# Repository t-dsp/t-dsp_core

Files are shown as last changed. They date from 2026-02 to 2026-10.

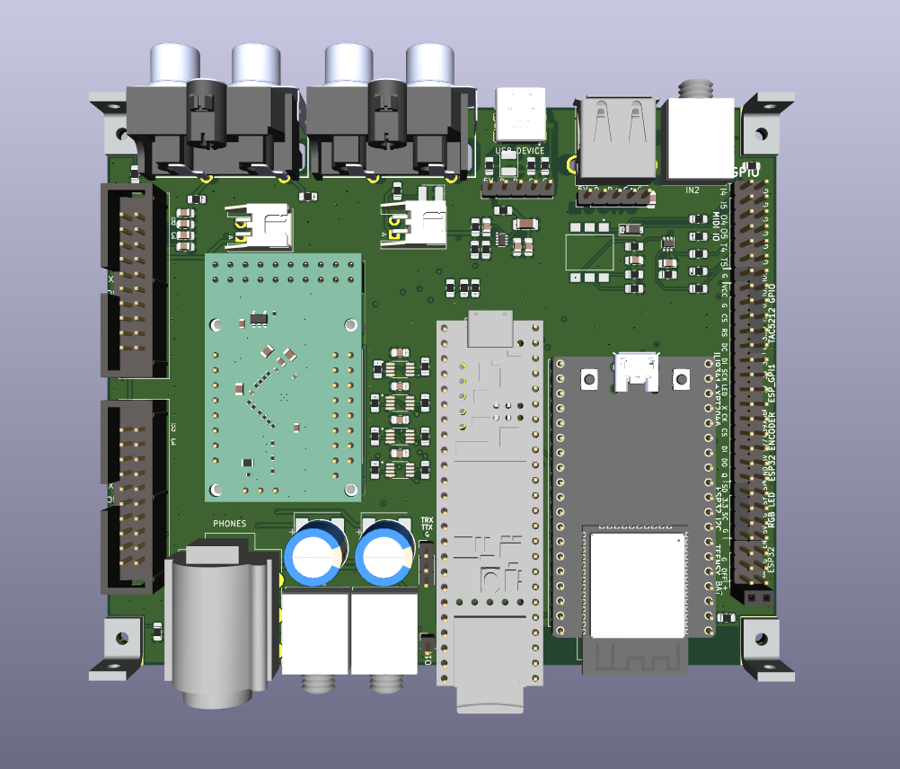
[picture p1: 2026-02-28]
documentation/t-dsp-desktop-pro-3d-top.png

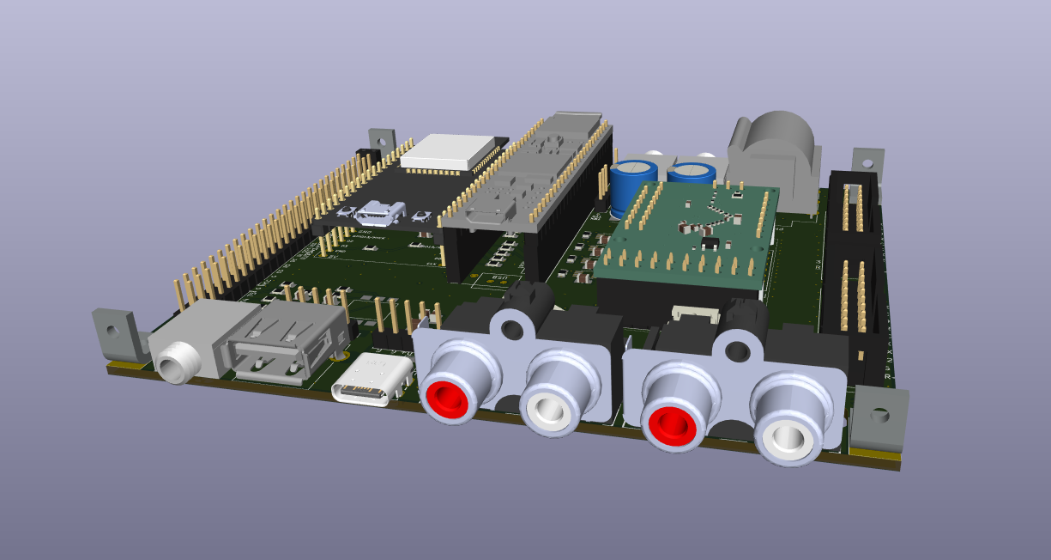
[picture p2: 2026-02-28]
documentation/t-dsp-desktop-pro-3d-angle_back.png

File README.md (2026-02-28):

# T-DSP Core

**Part of the [T-DSP](https://t-dsp.com) open modular audio platform.**

A compact 4-layer digital backplane for the T-DSP modular ecosystem. Hosts a Teensy 4.1 and ESP32 with USB Audio, MIDI, Ethernet, and TDM expansion headers for connecting T-DSP audio modules.

T-DSP Core - Top Isometric

| | |
|:---:|:---:|
| Top | Bottom |
| Front | Rear |

**[View 3D Render Gallery](https://t-dsp.github.io/t-dsp_core/gallery.html)** -- interactive slideshow of all board views

## About T-DSP

T-DSP is an open modular audio platform designed for musicians, engineers, and developers who want powerful digital signal processing in a flexible, hackable format. Built around the [Teensy](https://www.pjrc.com/teensy/) microcontroller and the [Teensy Audio Library](https://www.pjrc.com/teensy/td_libs_Audio.html), T-DSP combines studio-quality audio with a growing library of open-source modules.

Learn more at [t-dsp.com](https://t-dsp.com).

## Overview

The T-DSP Core is a **4-layer digital backplane PCB** hosting a Teensy 4.1 and ESP32 alongside supporting ICs. It provides USB Audio, MIDI, Ethernet, and TDM expansion headers for connecting T-DSP audio modules -- in a more accessible and cost-effective form factor than the 8-layer Desktop Pro.

## Processing

- **Teensy 4.1** -- ARM Cortex-M7 running the Teensy Audio Library for real-time DSP (mixing, effects, synthesis, routing). Also receives USB Audio.
- **ESP32** -- UI controller, WiFi/Bluetooth. Drives the display, buttons, and encoder, and sends commands to the Teensy over serial.

## Connectivity

### Audio I/O
- **3.5mm headphone jack** -- Switchcraft 35RAPC4BV4
- **RCA outputs** -- Stereo analog audio output
- **S/PDIF** -- Digital audio input and output

### USB
- **USB-C DEVICE** -- Power and USB Audio to Teensy with ESD protection
- **USB-A HOST** -- USB host connector

### Networking
- **RJ45 Ethernet** -- Wired network connectivity

### MIDI
- **MIDI input** -- 3.5mm TRS with optical isolation (H11L1)
- **MIDI GPIO** -- Configurable for MIDI in, out, or thru

### Power
- **Dual power input** -- USB-C or external supply via JST-XH header, with TPS22860 power switch for automatic switchover
- **Reverse polarity protection** -- P-channel MOSFET on power inputs
- **Power indicators** -- LED indicators for 5V and 12V rails

### Storage
- **SD card** -- Accessible via Teensy 4.1 built-in SD slot

## Expansion

- **2x TDM expansion headers** (2x10 pin, 2.54mm) -- Connect T-DSP audio modules
  - TDM digital audio bus (BCLK, LRCK, DATA_IN, DATA_OUT, MCLK)
  - I2C control bus (SDA, SCL)
  - Power rails (3.3V, 5V, 12V, GND)
  - Control pins (Held-high, Held-low)
- Modules can be soldered directly or socketed with pin headers
- Multiple modules can be chained on the same TDM bus

## User Interface

- **GPIO header** -- Active-low buttons, rotary encoder, and display connections for tactile UI
- **OLED display header** (128x64, SSD1306) -- Status and menu-driven UI
- **3.2" TFT touchscreen header** (ILI9341) -- Touchscreen UI
- **SK6812 addressable LED header** -- ESP32 and Teensy status indication, plus LED strip control

## Board Design

- **4-layer PCB** -- F.Cu (components/analog), In1.Cu (ground plane), In2.Cu (signal/digital), B.Cu (components/analog)
- **1.6mm board thickness**
- LDO voltage regulation for clean analog power
- Separate analog and digital ground domains
- Buffered digital outputs for reliable module distribution

## Project Files

| Directory | Contents |
|---|---|
| `/3d_models/` | 3D models for PCB components |
| `/documentation/` | Schematic PDF, board images, and reference docs |
| `/lib_fp/` | Custom KiCad footprint libraries |
| `/lib_sch/` | Custom KiCad schematic symbol libraries |
| `/manufacturing/` | CI-generated manufacturing outputs (gerbers, BOM, pick & place) |
| `/panel/` | Panelized board layouts for production |

## Status

This board is under active development.

If you build one, we'd love to hear how it goes -- please open an issue or reach out with your findings.

## Contact

For consulting, custom board design, or commercial licensing inquiries, reach out via [LinkedIn](https://linkedin.com/in/jayshoe).

## License

This project is licensed under the [Creative Commons Attribution-NonCommercial-ShareAlike 4.0 International (CC BY-NC-SA 4.0)](https://creativecommons.org/licenses/by-nc-sa/4.0/).

You are free to share and adapt this work for non-commercial purposes, as long as you give appropriate credit and distribute any derivatives under the same license.

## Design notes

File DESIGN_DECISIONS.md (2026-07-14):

# T-DSP Core — Design Decisions

Architecture decision records for the T-DSP Core (Desktop Pro) backplane. Newest first.

---

## ADR-002 — Next core: OPI PSRAM footprint for 32/64 MB resident fonts (2026-07-14)

**Status:** Accepted — design intent for the next core spin.

### Context
ADR-001 caps this Teensy-4.1 board at **16 MB** (stock QSPI PSRAM). To hold a high-quality GM
font **fully resident** in the chosen TSF engine — native GeneralUser GS (**30.6 MB** of
samples), or larger — the next system moves to a **bare i.MX RT1062** owning its own FlexSPI2,
populated with a single **OPI (Octal) PSRAM** chip. Downsampled GeneralUser variants
(`t-dsp_software/tools/sf2/`) let TSF fit 16 MB *today* (gu12 ~11.7 MB, gu14 ~13.5 MB) but
trade treble for fit; OPI PSRAM removes the ceiling.

### Decision
Design the next core around **one x8 OPI PSRAM footprint**, populated **one chip at a time**
with either density — these two parts are the targets:

| Target | Part number | Density / bus | Holds resident |
|---|---|---|---|
| **32 MB** | **AP Memory APS256XXN-OBRx** | 256 Mbit, DDR Octal (x8) | native GeneralUser GS (30.6 MB) + headroom |
| **64 MB** | **AP Memory APS512XXN-OBRx** | 512 Mbit, DDR Octal (x8) | GeneralUser + a 2nd font, or a ~40–50 MB studio font |

- **One land pattern, two densities.** Pick an x8 OPI BGA common to both the 256 Mb and 512 Mb
  parts so the same PCB accepts 32 MB *or* 64 MB per build. **Verify pin/package compatibility**
  between APS256XXN and APS512XXN in the chosen x8 package before committing the footprint (the
  512 Mb part also offers x16 — use **x8** to match the 256 Mb).
- Route FlexSPI2's **8 data lines + DQS** (vs. 4 for QSPI) plus CLK/CS.
- **Diminishing returns past 64 MB** (holding a 200–400 MB reference font resident) — beyond
  that, stream from SD (sf22aswt) or move to a larger-DRAM SoC.

### Firmware impact — going OPI BREAKS stock PSRAM until the Octal driver is written
- The stock Teensy / i.MXRT core PSRAM bring-up (`configure_external_ram`) speaks **QSPI
  APS6404 only**. It will **not** detect or initialise an OPI part: `external_psram_size` reads
  **0**, `extmem_malloc` fails, and **both SF2 engines are dead** until fixed.
- Fix = a one-time **Octal-DDR FlexSPI2 init driver** (custom LUT + mode-register config, and
  it must set `external_psram_size`), ported from the NXP SDK / RT1170 OPI examples. Everything
  *above* the PSRAM driver — the TSF int16 storage, the font loader, the engines — is
  chip-agnostic and unchanged.

### One interface only (decided) — OPI is not a second bus
OPI is **not a separate interface**. It is the **same FlexSPI2 controller** the Teensy already
uses for its QSPI PSRAM, run in **octal (x8) DDR** mode — a *superset* of the same pins (adds
DQ4–7 + a DQS strobe). So the next core routes exactly **one** PSRAM interface (the single OPI
chip on FlexSPI2) and does not populate any QSPI PSRAM. **No dual-routing.** On a bare RT1062,
FlexSPI1 stays the boot NOR flash; FlexSPI2 is yours for the OPI PSRAM.

**Fast/robust enough? Yes — *faster* than today's QSPI.** 8 DDR data lines vs 4 gives ~4–6× the
bandwidth (roughly ~66 MB/s QSPI → ~400 MB/s octal-DDR), and the DQS strobe aids timing closure
at speed. It's the mainstream external-RAM interface on the NXP RT1060/1170 EVKs and countless
shipping products. TSF already renders from QSPI PSRAM at ~45 % CPU today, so OPI is pure
headroom, not a risk — it just needs normal high-speed-DDR layout care (length-matched
DQ / DQS / CLK).

### Nested / concentric footprints (populate-one, zero extra routing)
Because QSPI is a **pin-subset** of OPI on the *same* FlexSPI2, multiple parts can share **one
land area** — populate exactly one, no second interface:
- **QSPI (SOIC-8) nested inside the OPI BGA.** APS6404 uses only SCLK, CS#, DQ0–3 — all of which
  the OPI part also uses (it adds DQ4–7 + DQS). Co-locate an 8 MB QSPI SOIC-8 land *inside* the
  OPI BGA, wiring the shared FlexSPI2 nets (CLK / CS0 / DQ0–3) to both, and DQ4–7 / DQS / RESET#
  to the BGA only. Stuff the QSPI part → **8 MB on the STOCK Teensy library** for board bring-up;
  later stuff the OPI part → 32/64 MB with the custom Octal driver. The earlier "fallback
  footprint" hedge is now **free** — it's the same nets, not a second bus.
- **APS256 (32 MB) and APS512 (64 MB) on one BGA.** Both are x8 Xccela; if they share the x8
  BGA-24 package (**verify** — the 512 Mb also comes as x16 BGA-49; use the x8), a single BGA
  land takes either density. Nest only if the packages actually differ.

Two caveats for the shared land: **(1)** keep the stub from the shared trace to each unpopulated
pad **short** — dangling stubs hurt the octal-DDR bus at speed; **(2)** **match IO voltage** —
Xccela OPI PSRAM is often **1.8 V** while APS6404L is commonly **3.3 V**; the shared FlexSPI2
pins sit at one bank voltage, so pick same-voltage parts (a 1.8 V QSPI PSRAM, or a 3.3 V OPI
part) or the nesting doesn't fly.

### More than 64 MB (e.g. 64+16)?
Possible, but not worth it. FlexSPI2 can address multiple devices on separate chip-selects, so an
OPI chip **plus** a QSPI chip (→ 64 + 16 = 80 MB) is not impossible — but it means two devices on
the high-speed bus (ideally split across FlexSPI2's A/B ports, pinmux permitting), a mixed
octal+quad custom driver, and tighter layout, all for capacity nothing needs: **64 MB already
holds native GeneralUser (30.6 MB) ~2× over.** If a font ever exceeds 64 MB, stream it from SD
(the sf22aswt engine) instead of adding RAM. **Target stays: one 32 MB or 64 MB OPI chip on the
single FlexSPI2 interface.**

### References
- Datasheets: **APS256XXN-OBRx** (256 Mb OPI) and **APS512XXN** (512 Mb OPI), AP Memory Xccela.
- Extends ADR-001's "Future / custom-MCU consideration" with committed part targets (supersedes
  the placeholder "APS25616" named there).
- Firmware font tooling: `t-dsp_software` → `tools/sf2/FONTS.md`, `tools/sf2/build_gu_fonts.py`.

---

## ADR-001 — PSRAM for the sampled soundfont engines (2026-07-14)

**Status:** Accepted

### Context
T-DSP Core hosts a **Teensy 4.1**. Its external PSRAM lives on the two QSPI pads on the
**underside of the Teensy module itself** (not on this backplane), so this is a
*populate-the-Teensy* decision, not a backplane-footprint one.

The T-DSP synth firmware includes sampled **General-MIDI SF2 engines** that need PSRAM
to hold sample data:

- **`teensy41_sf2_tsf` — TinySoundFont (the chosen engine).** Full-fidelity SF2 renderer:
  velocity layers, region layering, per-voice filters, and **MPE** (per-note pitch bend +
  pressure). It keeps the **entire font's samples RESIDENT in PSRAM** (stored as int16 via
  a local patch), so its font must *fit* PSRAM. Shipped font: **TimGM6mb (~6 MB)**.
- **`teensy41_sf2` — sf22aswt / AudioSynthWavetable.** Streams instruments **on-demand**
  from the SD card, so the font itself can be huge (full GeneralUser GS, 30 MB) while only
  the in-use instruments sit in PSRAM. Trade-off: fidelity ceiling — no velocity layers.

With `external_psram_size == 0` both are effectively unusable (TSF load fails; sf22aswt
falls back to a ~400 KB internal-RAM cap). The core auto-detects size and the firmware runs
unchanged on 0 / 8 / 16 MB.

### Decision
**Populate the Teensy 4.1 with PSRAM. Minimum 1× 8 MB; 16 MB (both pads) recommended.**

| PSRAM | Enables | Notes |
|---|---|---|
| 0 MB | *(no sampled GM)* | sampled SF2 engines don't run |
| **8 MB** (1 chip) | **TSF + TimGM6mb resident, full MPE** — the shipped config | minimum for the chosen engine |
| **16 MB** (2 chips) | headroom: larger resident TSF font (≤~14 MB) or bigger sf22aswt streaming cache | recommended full-populate |

Part: **AP Memory APS6404L-3SQR** — 64 Mbit (8 MB) QSPI PSRAM, SOIC-8 — one or both
underside Teensy pads. Adding the 2nd chip is auto-detected; **no firmware rebuild**.

### Rationale — quality is set by the *engine*, not PSRAM size
- TSF sounds best and does real MPE, but its font must be RESIDENT → compact font only
  (TimGM6mb-class at 8 MB; up to ~14 MB font at 16 MB).
- sf22aswt can reach genuinely high-quality fonts (FluidR3 ~150 MB) streamed from SD, but
  cannot render velocity layers.
- High-quality GM fonts are ~150 MB (FluidR3) to ~400 MB (reference); those live on **SD**,
  and PSRAM only ever holds the *working set* — you never need "as much PSRAM as the font."

Given the project has committed to TSF + MPE, **8 MB is the functional minimum and 16 MB the
comfortable target** for this Teensy-4.1-based board.

### Future / custom-MCU consideration (>16 MB via OPI PSRAM)
16 MB is the ceiling of the Teensy 4.1 / stock i.MXRT **QSPI** PSRAM driver. A future spin
that places a **bare i.MX RT1062** on this board (owning its own FlexSPI2) could go larger
with **OPI (Octal) PSRAM**:

- **QSPI caps at 8 MB/chip** (APS6404L). 16/32 MB parts are **OPI** — 8 data lines, not 4.
- **A single 32 MB OPI chip (e.g. APS25616) is the sweet spot:** it lets **TSF hold the full
  30 MB GeneralUser GS resident at full fidelity** — high-quality *and* fully expressive, the
  biggest quality-per-effort jump beyond 16 MB.
- **Cost:** route **8 data lines** (vs 4) + a one-time **Octal FlexSPI init** driver (the stock
  core is QSPI-only; port from the NXP SDK / RT1170 OPI examples). Everything *above* the PSRAM
  driver — the int16 TSF storage, the font loader, the engines — is chip-agnostic and unchanged.
- **Diminishing returns past ~64 MB** (holding a 200–400 MB reference font resident); at that
  point, stream from SD or move to a larger-DRAM SoC.

**Recommendation:** ship 8/16 MB **QSPI on the Teensy 4.1** (zero new firmware, sufficient for
the shipped TSF engine). *If* a custom-RT1062 spin happens and resident high-quality GM is a
goal, target **one 32 MB OPI PSRAM chip** + the Octal FlexSPI driver.

### References
- Firmware: `t-dsp_software` → `lib/TDspTsf` (TSF int16 patch), `lib/TDspSF2` (sf22aswt),
  build envs `teensy41_sf2_tsf` / `teensy41_sf2`, and `lib/TDspSF2/SF2_GM_ENGINE_PLAN.md`.
- Teensy 4.1 PSRAM: underside SOIC-8 pads on FlexSPI2, `external_psram_size` = 0/8/16.

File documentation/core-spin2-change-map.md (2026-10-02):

# T-DSP Core spin 2 — change map

Status: **schematic edits done 2026-09-28 on branch `spin2/core-module`** (stages 2–5 of §12). Netlist
verified after every stage; ERC is down to one residual (see §14). PCB not yet updated from the
schematic. This document
collects every decision made in the 2026-09-28 design review so the schematic work can be
checked against it. It supersedes the architecture parts of `bt-asrc-block-netplan.md`
where the two disagree (Port B routing, control-line assignments, the DIT). The netplan
remains the reference for the BT module pinout and the IDC747 → IDC777 migration.

Every item is tagged **[decided]**, **[consequence]** (follows from a decision), or
**[open]** (still needs the user's call).

---

## 1. What the board is

**[decided]** The core is a **general-purpose audio compute module**, not a finished
backplane. 2.54 mm headers on two board edges expose the Teensy 4.1, the ESP32-S3, the
audio buses, and the SRC. Users design a backplane that carries codecs, amps, jacks,
connectors, and power entry. The core accepts **5 V** and generates its own rails. The
backplane may carry the bulk of the system current (core ≈ 0.6 A typical, ≈ 1.3 A peak; see the
current budget in §7).

**[decided]** The **isolated DMX / RS-485 block stays on the core** (U16, U17, U18, J28,
D6). It keeps S3 pins IO1, IO5, IO48.

**[decided]** Single-source wireless audio. BT **or** WiFi streaming, never both. No
mixing on the S3, no software resampler on the S3.

**[consequence]** Parts that belong on the backplane and leave the core schematic:

| Leaves the core | Refs |
|---|---|
| Ethernet jack, header | ETHERNET1, ETHERNET_J1 |
| USB-A host, USB-B, USB-C device, USB ESD, USB pin headers | USBA1, USBB1, USBC1, U10, USB_HOST_1, USB_DEVICE_1, D5, CC1, CC2, RLED1, R27 |
| 3.5 mm jacks, 6.35 mm phone jack, RCA/line | J22, J23, J_PHONE1, HPTRS1, HPTRS2, OUT1, INPUT1 |
| MIDI jacks only (opto U4, buffer U9 and passives **stay**) | MIDI_IN_1, MIDI_OUT_1, MIDI_IO1, MIDI_OT1, MIDI_OT2 |
| Rotary encoder, tactile switches | SW1–SW10 (SW3/4/9/10 are the EN/IO0 buttons, see §6) |
| JST power inputs and reverse-polarity FETs | J10, J11, Q1, Q2 |
| Optical S/PDIF TX/RX | TT1, TT2, TR1, TR2, SPDIF1, SPDIF_IO1, SPDIF_IO2 |
| MEMS microphones | MIC1, MIC2 |
| LED chain header only (the SK6812 status LEDs D3/D4 and their 5 V level shifter IC1 **stay**; the chain continues to the backplane via the LED_OUT header pins) | J12 |
| TFT / GPI / encoder / I2C / programming header duplicates | ILI1, ILI2, GPI1, GPI2, ESP_R_ENC1, ESP_R_ENC2, ESP_I1, ESP_I2, ESP_PROG1, ESP_PROG2, T_PROG1 |
| Old ESP32 DevKitC and TAC5212 module symbol | U2, board_outline1 |
| Battery header/cell | BAT1, BAT2 |

Delete them rather than leaving them excluded-from-board: U2 alone is still on 30+ nets
and every one of these adds ERC noise and confuses the header map.

---

## 2. Wireless audio block (BT + S3 → mux → ASRC → Teensy)

> **Superseded on 2026-10-01 (stage 10y, section 11.8).** The SRC4382, both 74LVC157 muxes and the
> S/PDIF header are gone. IDC777 and S3 now reach the Teensy's SAI2 port through a 74LVC257 mux,
> sample-rate conversion is done in Teensy software, and a buffered J_SAI2 header offers the same
> port to an external I2S master or slave. The text below is kept as the history of the decision.

Architecture: IDC777 (U22) and the S3 are both **I2S masters** into a hardware mux, the
mux feeds SRC4382 Port A (slave), the SRC resamples onto the Teensy's clock and outputs on
Port B (slave to the Teensy). One source at a time.

### 2.1 Mux

**[decided]** Keep U21 (74LVC157A) for BT vs S3.

**[decided]** Add a **second 74LVC157A (U23)** cascaded after U21: selects between U21's
output and an **aux I2S input from the edge header** (BCK, LRCK, DATA). Aux must be an I2S
master. Cost: one TSSOP-16, three header pins. If the header pin budget gets tight, aux is
the first thing to cut.

### 2.2 SRC4382 (U19) wiring changes

| Pin | Today | New |
|---|---|---|
| 48 BCKB | BCLK1+TDM1 | **4_BCLK2** (Teensy pin 4, I2S2 BCLK) |
| 47 LRCKB | LRCK1+TDM1 | **3_LRCLK2** (Teensy pin 3, I2S2 LRCLK) |
| 45 SDOUTB | SRC_SDOUT (dangling) | **5_IN2** (Teensy pin 5, I2S2 IN) |
| 46 SDINB | NC | **2_OUT2** (Teensy pin 2, I2S2 OUT) — reverse ASRC path |
| 40 SDOUTA | NC | **edge header, aux I2S out** — reverse ASRC path |
| 24 ~RST | SRC_RST (dangling) | **ESP32_EN** net |
| 26 GPO1 | NC | **BT_RST** (U22 pin 36) |
| 27 GPO2 | NC | **BT_SYS_CTRL** (U22 pin 13) + 100 k pulldown to GND |
| 28 GPO3 | NC | **BT_S3_SEL** (U21 pin 1) |
| 29 GPO4 | NC | **AUX_SEL** (U23 select) |
| 1–8 RX1±…RX4± | NC | **edge header**, raw differential pairs |
| 31, 32 TX−, TX+ | NC | **edge header**, raw pair |
| 12 RXCKO, 11 ~LOCK, 15 ~RDY, 23 ~INT | NC | leave NC (or S3 GPIO later) |

Why: the SRC has **no TDM mode** (checked in the full SRC4392 datasheet) and drives SDOUT
continuously, so Port B cannot share the TDM1 data line. Moving Port B to Teensy I2S2
gives the Teensy a plain stereo `AudioInputI2S2`. GPOs default **low** at reset, are
register-forced high/low (regs 0x1B–0x1E), and cost zero S3 pins. BT held in reset until
the S3 configures the SRC is the desired ordering. SRC ~RST on ESP32_EN resets the SRC with
the S3 and satisfies the 500 µs I2C hold-off by a wide margin. The SRC4382 **does** have
a DIT (TX pins are real), contrary to the netplan.

Firmware notes that follow: soft-mute (reg 0x2D) around source switches, since the
hardware MUTE pin is tied to GND. Reverse path = SRCIS=Port B, AOUTS=SRC; one direction at
a time.

### 2.3 S3 I2S master

**[decided]** S3 is I2S master on its second I2S controller into U21 inputs I1a/I1b/I1d.
**[consequence]** The existing S3-slave I2S2 link to the Teensy is **retired in both
directions**: IO4/IO6/IO7 become the master port, IO16 is freed. The Teensy's I2S2 port is
now owned by the SRC (2, 3, 4, 5).

### 2.4 BT module (U22) — unchanged from netplan except:

- BT_UART_TX / BT_UART_RX → **S3 UART2** on IO16 (RX) and IO35 (TX) — see §3 for the
  variant dependency.
- BT_RST, SYS_CTRL, BT_S3_SEL now from SRC GPOs (§2.2).
- VCHG / VCHG_SENSE / CHG_EXT stay no-connect; add **test points** per datasheet advice.

---

## 3. ESP32-S3 (U13) pin map

| Pin | Use after spin 2 |
|---|---|
| IO4, IO6, IO7 | I2S master → U21 (DOUT, BCK, LRCK — assign in firmware) |
| IO16 | BT UART2 RX |
| IO3 | BT UART2 (S3 RX side, net `BT_UART_RX`). IO35 is not available on the N16R8 module |
| IO19, IO20 | **native USB D−/D+ → edge header** (OTG, host or device) |
| RXD0, TXD0 | Teensy Serial7 (programming + FlasherX tunnel) **and** edge header |
| IO0, EN | Teensy 36/37 **and** edge header (already pins 60/56) |
| IO1, IO5, IO48 | DMX (stays) |
| IO8, IO9, IO10, IO11, IO2, IO42, IO18 | TFT SPI + touch (already on header) |
| IO12, IO13, IO14, IO17 | SPI link to Teensy (internal) |
| IO15, IO38, IO39 | encoder (already on header) |
| IO40, IO41 | GPI (already on header) |
| IO21, IO47 | I2C (already on header) |
| IO45 | **→ J8** (strapping pin; document the boot constraint). IO46 drives the SK6812 chain (`ESP32_LED`), 5 V copy on J11 |
| IO35, IO36, IO37 | **NC** - owned by the octal PSRAM on the N16R8 module |

**[decided 2026-09-28] Module variant: ESP32-S3-WROOM-1-N16R8** (LCSC C2913202). Spotify
Connect (cspot and the Espressif audio SDK) buffers and decodes the Vorbis stream in PSRAM and
needs 4-8 MB; the 2 MB quad-PSRAM R2 parts are not enough. Octal PSRAM uses IO35/IO36/IO37,
so those three module pins are NC and the BT UART RX moved to IO3. PCB antenna (-1, not -1U).

---

## 4. Teensy 4.1 (U1) pin changes

| Pin | Today | New |
|---|---|---|
| 2 OUT2 | → S3 IO4 | `SAI2_OUT` → U21 buffer → J_SAI2 DOUT (stage 10y; was SRC SDINB) |
| 3 LRCLK2, 4 BCLK2 | → S3 (via 49.9 Ω) | `SAI2_LRCLK` / `SAI2_BCLK`: from the U19 257 mux (IDC777 or S3) or J_SAI2 via U21, or driven out to J_SAI2 (stage 10y) |
| 5 IN2 | ← S3 IO7 | `SAI2_IN`: from the U19 mux or J_SAI2 DIN via U20 (stage 10y) |
| 22 | NC | `SAI2_SEL` (U19 select: 0 = IDC777, 1 = S3; 10 k pull-down) — stage 10y, no longer on J3 |
| 26, 27 | NC | `SAI2_MODE0` / `SAI2_MODE1` (U23 interlock, 10 k pull-ups = all off) — stage 10y, no longer on J3 |
| 32 OUT1B | J15 (1-pin) | → edge header |
| 33 MCLK2 | J19 (1-pin) | `SAI2_MCLK` → U21 buffer → J_SAI2 MCLK in both header modes (stage 10y; J3 pin 22 is GND now) |
| 49 VUSB | NC | → **TPS2116 VIN2** (see §7) |
| 46 3V3 | on the 3.3V rail | **disconnected from the rail, not exposed** (see §7) |
| 55–57 host USB | USBA1 / USB_HOST_1 | → edge header (D+, D−, HOST_5V) |
| 66/67 device USB | USBC1 / U10 | **stays on the Teensy's own jack only; not on header** |
| 28/29 Serial7, 36/37 | S3 UART0 / IO0 / EN | unchanged — programming kit + FlasherX |
| 53 PROGRAM, 54 ON_OFF | header 55/59 | unchanged |

MIDI: MIDI_IN/OUT/THRU are on header pins 1–6 at the *jack* level. **[decided]** the opto
(U4), buffer (U9) and their passives stay on the core.

Also **[open]**: `9_OUT1C_INPUT` feeds Teensy pin 9 as TDM2's data-in. Pin 9 is OUT1C; the
audio library's inputs are IN1 (pin 8) and IN2 (pin 5). Confirm this is intentional or
re-purpose.

---

## 5. Edge headers

**[decided]** 2.54 mm headers, **two 2-row headers side by side near each 60.96 mm edge**
(four rows per end, inboard by ~5 mm): **≈168–176 pins**. See §11 for placement and §11.2
for the pin-assignment rules.

**[consequence]** The `board_outline` symbol (lib_sch:t-dsp_core, 106 pins) is the header
net map, but **no outline footprint has pads for it**. A real header footprint must be
built (this is the source of the six `footprint_link_issues` ERC errors). TDM1/TDM2 as
separate 2x10 connectors are redundant with the T*/TT* header groups and leave the core.

**[decided 2026-09-28] GPIO exposure policy: raw pins, not named UI functions.** The
core does not decide what a backplane builds. Pins go to the header as plain GPIO and the
backplane wires TFT, touch, encoder, buttons, LEDs, or nothing. Consequences:

- **S3 side:** every free S3 pin is `S3_IOnn`. The S3's GPIO matrix maps SPI, I2C, UART,
  PWM, and I2S to any pin, so nothing is lost by not naming them. The on-core TFT/touch
  pull-ups (R22/R23/R64/R65), LED jumpers (ILI_LED1–4), and the duplicate UI headers all go.
- **Teensy side:** every free Teensy pin is `T_nn`. The i.MX RT has *fixed* peripheral
  pins, so the header doc carries the Teensy pin-capability table (which pins are I2C,
  SPI, UART, CAN, PWM, analog). **MIDI logic stays on the core** (opto U4, buffer U9, their
  passives): the header carries MIDI IN/OUT/THRU at the *jack level* (existing pins 1–6);
  only the DIN/TRS jacks themselves are on the backplane. Same for DMX: isolation and
  transceiver on the core, the XLR on the backplane.
- **Exceptions, still named, because the core transforms or owns them:** the two buffered
  TDM buses, `I2C0` (shared with the SRC, pull-ups on the core), SRC S/PDIF RX/TX pairs,
  aux I2S in/out, the three USB pairs, S3 `UART0` + `EN` + `IO0` (programming), Teensy
  `PROGRAM`/`ON_OFF`, `VBAT`, **MIDI IN/OUT/THRU (jack level)**, **DMX A/B**,
  **ESP32_LED_OUT / TEENSY_LED_OUT** (SK6812 chain continuation, 5 V level), and all power pins.
- **The reference backplane** (dev board + test jig) is where the opinionated wiring lives:
  TFT, encoder, buttons, MIDI jacks, codec. That is what makes the platform "easy to build
  something useful with", not the core.

Signals to **add** to the existing 106:

| Group | Pins |
|---|---|
| SRC S/PDIF: RX1± … RX4±, TX± | 10 |
| Aux I2S in (BCK, LRCK, DATA) | 3 |
| Aux I2S out (SDOUTA) | 1 |
| S3 USB D−/D+ | 2 |
| S3 RXD0/TXD0 | 2 |
| S3 spare GPIO (IO3, IO45, IO46, IO36, IO37) | 3–5 |
| Teensy 22, 26, 27, 32, 33 | 5 |
| Teensy host USB D+, D−, HOST_5V | 3 |
| 5V_IN (into TPS2116 primary) | 1–2 |
| Extra GND adjacent to USB/clock pairs | ~6 |
| **Total ≈ 106 + 38 = ~144** | fits, barely |

Rules: every USB pair on adjacent pins with GND either side; the same for MCLK/BCLK;
5 V and 3.3 V pins are **output-only** except the dedicated 5V_IN. If short of pins, drop
in this order: aux I2S in/out, duplicate 3.3 V/5 V pins, S3 strapping pins.

---

## 6. USB and programming

**[decided]** **No USB mux.** The Teensy's own micro-USB jack is the core's power input and
the Teensy's programming / USB-audio port. The Teensy **device** pair is **not** on the
header (a second connector would be an unterminated stub on a 480 Mbps pair). A panel USB
for the Teensy on a product is a short extension from the Teensy jack.

**[decided]** Teensy **host** pair and S3 **OTG** pair go to the header. Backplane provides
connectors, ESD, VBUS switching (Teensy HOST_5V is just VIN; the host library has no
power-enable pin).

**[revised 2026-10-01, stage 10y]** All three USB ports are on headers and **none is isolated**
(the ISOUSB211 plan of stage 10x was dropped with the SAI2 rework): Teensy host pair on J4 odd
row (1 GND, 3 HOST_D1-, 5 HOST_D1+, 7 GND, 9 HOST_5V), Teensy device pads 66/67 on J4 even row
(2 GND, 4 T_USB_DN, 6 T_USB_DP, 8 GND, 10 GND), S3 OTG pair on J8 (31 S3_USB_DN, 32 S3_USB_DP,
33 GND, 34 5V). The S3 port is host or device by firmware; J8 pin 34 is the core's 5 V rail, so a
backplane wires it to a jack's VBUS only for a host-mode jack (or through a load switch); a
device-mode jack leaves VBUS unconnected. The Teensy device row has no VBUS pin: the Teensy's
VUSB is NC on the core (stage 10x). Ground-loop hum between a laptop and the externally powered
core is handled on the backplane (isolator or audio-side ground lift) if it shows up.

**[decided]** EN and IO0 on the edge connector (already). On-core prog headers and EN/IO0
buttons leave. **Add a 10 k pull-up on ESP32_EN** — required by the software repo's
`TDspProgrammingKit` README for the next spin and by the S3 module reference design.
Today the net has only the two 0.1 µF caps.

**[verified]** FlasherX path (`@FXUP` over Teensy Serial7 ↔ S3 UART0, EN from Teensy 37,
IO0 from Teensy 36) is fully wired. S3 UART0 is not its USB console, so the tunnel no
longer competes with logging. 115200 is a firmware constant on both ends.

**[consequence]** Teensy is flashed by the S3 via FlasherX only (self-reflash). HalfKay is
USB-only; recovery of a bricked Teensy needs a cable in the Teensy jack.

---

## 7. Power

```
edge header 5V_IN ──► TPS2116 VIN1 (priority) ─┐
Teensy VUSB (pin 49) ► TPS2116 VIN2 (secondary) ┴──► 5V rail ──► Teensy VIN
                                                        ├──► 3.3 V buck  ──► 3.3V_DIG (S3, BT, SRC, mux, ISO7761)
                                                        │                     └► TLV76718 ──► +1V8 (SRC core)
                                                        ├──► LT3045 (U15) ──► 3.3V (buffers, header, analog)
                                                        └──► TEA1-0505 ──► 5V_ISO (DMX)
```

| Item | Status | Action |
|---|---|---|
| TPS2116 input mux | wired (JST + USB-C) | **VIN1 ← header 5V_IN; VIN2 ← Teensy VUSB**. J20 already sits on VIN2. |
| Teensy VUSB↔VIN pad | intact | **Must be cut** on every Teensy. Otherwise PC USB 5 V and the backplane supply are paralleled. Build note. |
| 3.3V_DIG regulator | TLV76733 LDO, 1.3 W in 2×2 WSON at 750 mA | **[decided] replace with a 3.3 V buck**, 1.5–2 A class (TPS62A02 / TPS563xx class). Keep R66 enable pull-up semantics. |
| LT3045 (U15) | output dangling (only C42) | **connect OUT to the 3.3V rail**. SET = 33 k → 3.3 V. Check R58 ILIM value. |
| Teensy 3V3 (pin 46) | sources the 61-node 3.3V rail | **remove from rail; not exposed**. Never parallel two regulators. |
| LP5907 3.3V_A (U109) | mic rail via net-tie + jumper to 3.3V | mics leave the core; **[open]** keep as a second analog LDO or delete. |
| FL2 / CR1 / FB8 branch | dead (5V_unfiltered, GND_unfiltered single-node) | delete |
| 12V | JST + Q2 pass-through to headers | **[open]** keep as pass-through pin only, or drop. Core does not generate it. |
| 3.3V header pins | on rail | output-only, advertise a limit (~200 mA). Never accept 3.3 V in. |
| USB-C PD | none | **not on the core.** Backplane/submodule PD sink (STUSB4500 or CH224K) when >15 W is needed; backplane bucks to 5 V for 5V_IN. |
| MCLK1 | Y1 via R61 **and** Teensy pin 23 via R7 | **[open]** two drivers on one net. Y1 standby jumpers R59/R60 exist. Decide which populates. |

Current budget on the 5 V rail, core alone (revised 2026-09-30):

| Load | Typical | Peak | Note |
|---|---|---|---|
| Teensy 4.1 at 600 MHz + 2x PSRAM | 150 mA | 200 mA | +100 mA more with the Ethernet PHY linked |
| ESP32-S3 (via the 3.3V_DIG buck, ~90 %) | 200 mA | 450 mA | WiFi TX bursts; ~40 mA idle, ~100 mA BLE only |
| IDC777 BT audio | 50 mA | 100 mA | A2DP streaming |
| SRC4382 + 1V8 LDO | 60 mA | 80 mA | |
| DMX: TRACO TEA1-0505 + ISO7762 + RS-485 | 100 mA | 250 mA | 1 W converter at full isolated load |
| SK6812 D3/D4 | 40 mA | 120 mA | full white |
| Buffers, muxes, LDO quiescent | 15 mA | 20 mA | |
| **Core total** | **≈ 0.6 A** | **≈ 1.3 A** | plus Ethernet: ≈ 1.4 A peak |

Plan **1.5 A for the core** and a 2.5-3 A external supply once a backplane with codecs and small
amps hangs off `5V` and `3.3V`. The TPS2116 mux is rated 2.5 A. A PC USB port (500 mA) on the
Teensy jack programs both MCUs and runs the board with the radios idle, but browns out under
WiFi bursts or DMX + LEDs; a USB-C port at 1.5 A is fine for bench use.

---

## 8. Slave-clock option (keeps DAC-master and multi-core architectures possible)

Today the core can only be the audio clock **master**: buffers U5 (LRCK1), U6 (MCLK1),
U7 (BCLK1) have ~OE tied to GND and drive outward; the Teensy's clock pins sit behind them
with no path back from the bus.

**[decided]** Make it switchable, cheaply:

1. **Buffer ~OE pins** (U5, U6, U7, U8 data-out, U11 data-in) move from hard GND to a
   **solder jumper (default GND) or one S3/Teensy GPIO** (`BUS_MASTER_EN`). A slave core
   tri-states its drivers.
2. **Bypass jumpers** from the header-side clock nets (BCLK1+TDM1, LRCK1+TDM1, MCLK1+TDM1)
   to the Teensy-side nets (BCLK1, LRCK1, MCLK1) — one 2-pad solder jumper per line,
   default open. Closed + buffers disabled = Teensy is I2S slave to the bus.
3. **Y1** already has standby jumpers (R59 to VDD / R60 to GND); a slave core populates R60.
4. **SRC I2C address**: add a jumper option on A0/A1 (pins 19/21) so two cores on one I2C
   bus don't collide. Zero cost.
5. **No-radio build variant**: IDC777, S3 antenna path, U20/U21/U23 DNP-able. Multiple cores
   in one box should have radios on one core only.

Firmware: the audio library has I2S slave objects for both Teensy ports (stereo). A TDM
slave object does not exist in the software repo yet.

Why: a serious DAC stage wants the oscillator beside the DAC with the DAC as clock master;
multi-core digital mixing needs one clock master. Both need the core to accept clocks.
Cost is a handful of jumpers.

---

## 9. Cleanups found during the review

- Delete **U2** (ESP32-DevKitC, excluded-from-board, still on 30+ nets) and
  **board_outline1** (TAC5212 module symbol).
- Orphan single-node nets to remove or connect: `Earth`, `GNDD`, `S-GND`, `SN`,
  `ESP32_3.3V`, `5V_unfiltered`, `GND_unfiltered`, `MCLK2` (J19), `32_OUT1B` (J15).
- **Footprints missing**: C130, C131 (5 V decoupling), C132, C133 (3.3V_DIG decoupling),
  R66 (100 k enable pull-up).
- Konnect user config `%APPDATA%\konnect\config.json` line 10: `layer_count` is 2, the
  board is 4-layer. Set to 4 before trusting DRC.
- Antenna keepout for U22: 8 × 4.44 mm at the −X end, all copper removed on every layer
  out to the board edge, plus a PCB keepout rule. Board-edge, top-left per datasheet.

---

## 10. Open decisions (blocking nothing else)

| # | Decision | Default if not decided |
|---|---|---|
| 1 | ~~S3 module variant~~ **[decided 2026-09-28]: ESP32-S3-WROOM-1-N16R8** (8 MB octal PSRAM, required for Spotify Connect stream buffering; costs IO35-37). PCB antenna. | - |
| 2 | ~~Board outline~~ **[decided 2026-09-28]: 100 × 60.96 mm**, see §11 | — |
| 3 | MCLK1 driver: Y1 or Teensy pin 23 | Y1 (24.576 MHz = 512·fs), Teensy pin 23 via R7 removed |
| 4 | 12 V: pass-through pin or drop | pass-through pin, no on-core parts |
| 5 | ~~MIDI logic~~ **[decided 2026-09-28]: stays on the core**, jack-level on the header (user: MIDI and DMX are core features of an audio device) | — |
| 6 | LP5907 3.3V_A: keep or delete | delete (mics leave) |
| 7 | `9_OUT1C_INPUT` intent | ask |
| 8 | ~~External antennas~~ **[decided 2026-09-28]**: BOM options -1U and IDC767, u.FL J13 DNP on pad 57 (see section 11) | — |

---

## 11. Mechanical and placement

**[decided]** Outline **100 mm × 60.96 mm** (`project_fp:audio_project_board_outline_100x60.96`,
already placed as board_outline2). 60.96 mm = the Teensy 4.1's 2.4 in length.

**[decided]** The Teensy spans the full 60.96 mm depth with its **micro-USB end flush with
one 100 mm edge and its microSD end flush with the other**, so a backplane or enclosure
can expose either. Soldered directly, no socket.

**[decided]** The edge headers are on the two **60.96 mm edges**, perpendicular to the
Teensy. The 100 mm edges carry only the Teensy ends and the antennas.

**[consequence] Pin budget.** A 60.96 mm edge holds 24 positions at 2.54 mm with no
margin, ~21–22 with corner mounting holes. One 2-row header per edge = **~84–88 pins
total**, far short of the ~144 in §5. Options:

| Option | Pins | Notes |
|---|---|---|
| **A. Two 2-row headers side by side per edge** (4 rows, 10.16 mm strip) | 168–176 | **recommended.** Fits §5 with ~25 spare. Backplane sees two parallel 2×21/2×22 connectors per edge, a common arrangement. |
| B. One 2-row header per edge + cuts | 84–88 | needs ~55 pins cut: TDM2 bus gone, TDM GND pins thinned, MIDI THRU, aux I2S, S3 spares, SRC RX3/RX4, duplicate power pins. Loses the second TDM bus, which a backplane can replace by chaining modules on one bus. |
| C. 2.0 mm or 1.27 mm pitch | 100+ | rejected: 2.54 mm is a product requirement. |

**[decided 2026-09-28]: option A**, two 2-row headers per short edge (four rows).

**[consequence] Area.** With option A each short edge loses a 10.16 mm strip and the Teensy
takes an 18 mm strip: usable top area ≈ 62 × 61 mm ≈ 3800 mm². Estimated courtyard after
the §1 deletions and the §2/§7 additions ≈ 3300 mm² plus the headers. **Two-sided assembly
is required**: Teensy, S3, IDC777, SRC and headers on top; small ICs and passives on the
bottom. The bottom under the Teensy is usable, the top under it is not (the Teensy carries
bottom-side parts).

**[consequence] Antennas.** Both radios need a board edge with copper removed on every
layer: 8 mm along the edge × 4.44 mm inward for the IDC777, roughly 15 × 6 mm for a
PCB-antenna S3. Both go on the **100 mm edges**, in the 82 mm not occupied by the Teensy
end, offset ≥ 6 mm from the corners so the header strips on the short edges are not cut
into. One radio per long edge, or both on one long edge at opposite ends, ≥ 40 mm apart.

**[decided] Headers sit inboard, not on the edge.** Outer row centreline ≈ 5 mm from the
short edge (rows at x ≈ 5.0, 7.5, 10.1, 12.6 mm and mirrored at the other end). Nothing
requires a mezzanine header to touch the edge, and inboard gives every row an escape
channel on both sides, frees the true corners for mounting holes, and leaves a copper-free
margin. Moving them further inboard than that buys nothing: the routing lever is *which*
signals go to *which* header, set by the placement below.

### 11.1 Placement plan (drawn for routing, X in mm from the left short edge)

```
 x:  0    5   13  15         33  35                                   85  87   95  100
     |  [hdr L 4 rows] [  TEENSY  ]  [ S3 ]  [SRC][mux]   [DMX iso][pwr] [hdr R 4 rows]  |
     |                  USB end @ y=0  ant@y=0                                            |
     |                  SD end @ y=61  [IDC777 ant @ y=61]                                |
     bottom side under the Teensy: 5 bus buffers, series Rs, Y1, TPS2116, input caps
```

- **Left header = Teensy domain.** TDM1 and TDM2 buses (from the buffers directly beneath
  the Teensy on the bottom side, shortest possible path), MIDI, Teensy S/PDIF, CAN3,
  Teensy spares (22/26/27/32/33), Teensy host USB, PROGRAM/ON_OFF, VBAT, 5V_IN, power outs.
- **Right header = S3 / peripheral domain.** TFT SPI + touch, encoder, GPI, both I2C
  buses, S3 USB, S3 UART0, EN/IO0, S3 spares, DMX A/B, SRC S/PDIF RX/TX, aux I2S in/out,
  LED outs.
- **Antennas on the long edges** in the 50 mm between the Teensy and the right header:
  S3 PCB antenna on one long edge, IDC777 on the other, ≥ 40 mm apart.
- **Teensy near the left header** so its left pin row (pins 0–12: MIDI, I2S2, TDM data,
  SPI) is 2–3 mm from the header and the I2S2 pins face the SRC. Its right row (TDM
  clocks 20/21/23, I2C, S3 control) reaches the buffers on the bottom side through vias.

### 11.2 Header pin-assignment rules (for the pin map, not yet drawn)

1. **Order pins along Y to match the physical order of their sources** (Teensy pin 0 at the
   USB end ascending toward the SD end; S3 pins likewise) so traces do not cross.
2. **Outer 2-row header = signals that arrive on the outer layers; inner header = signals
   that arrive through the bottom side or In2.** Keeps layer changes near the pins.
3. **One GND per ≤ 4 signals, and a GND adjacent to every clock and every differential pair.**
   MCLK (24.576 MHz), BCLK, and the USB pairs get GND on both flanks.
4. **Differential pairs on adjacent pins in the same row**, never across rows: Teensy host
   USB, S3 USB, SRC RX1–RX4, SRC TX.
5. **Power pins at the ends of each block** (5V_IN, 5 V, 3.3 V, 12 V pass-through, GND) so
   wide copper stays out of the signal field.
6. **All four TDM lines of a bus in one row, contiguous, with GND between**: MCLK, BCLK,
   LRCK, DATA_OUT, DATA_IN.
7. **Reserve ≥ 8 spare pins per block** at the inner end, labelled RESERVED, never repurposed
   without a header-contract version bump.
8. **Name every pin by function, not by MCU pin number** (the header is the product API;
   a future core with a different MCU must fit the same backplane).

Stackup for routing: F.Cu signal, In1.Cu solid GND, In2.Cu signal with 3.3 V / 5 V islands,
B.Cu signal + bottom-side parts. Every header signal has In1 GND directly beneath it.

**[decided 2026-09-28] Teensy memory.** The Teensy 4.1 carries two bottom-side SOIC-8 pads for
PSRAM/flash. Fit **2 x APS6404L-3SQR-SN** (16 MB PSRAM, mapped as EXTMEM) for loop recording,
echo and reverb buffers, or one PSRAM + one W25Q128 flash. The chips are 1.2 mm tall on the
Teensy's underside, so the core's top side under the Teensy footprint is a **placement keepout**
and the Teensy mounts on 2.54 mm headers (not soldered flat). Power: about 10 mA per PSRAM at
3.3 V from the Teensy's own regulator.

**[decided 2026-09-28] Ethernet.** The Teensy's 10/100 PHY pairs are on six 2 mm-pitch pads
(60-65) on its underside. They are **not** reachable by a cable once the Teensy is mounted, so
the core picks them up: pads 60-65 return to the Teensy footprint (they exist in
`Teensy41.kicad_mod`, were dropped in `_mod3`) and route under 20 mm as two 100 ohm pairs to
**J12 `J_ETH`** right beside them. Magnetics, RJ45 and the LED resistor live on the backplane.

**[decided 2026-09-28] Antennas: on-board by default, off-board as a BOM option, no layout change.**
- S3: `ESP32-S3-WROOM-1-N16R8` (PCB antenna, C2913202) or `ESP32-S3-WROOM-1U-N16R8` (u.FL on the
  module, C3013946). Same pad layout; the -1U is 6 mm shorter. Keep the top-edge copper keep-out in
  both builds.
- Bluetooth: `IDC777-1` (chip antenna) or `IDC767` (external antenna). Verified from datasheets
  IDC767-DTS-V003 and IDC777-DTS-V003: identical 60-pad LGA and pin table; **pad 57 is EXT_RF on
  both** ("RF to EXT Antenna (Ext ANT SKU - IDC767)"), unused on the IDC777. The core routes pad 57
  to a DNP u.FL (J13) as a 50 ohm coplanar waveguide with ground pads 56 and 58 on either side,
  ground vias every 1-2 mm along it, trace as short as possible, continuous ground on the layer
  below. No matching network. With the IDC777 fitted the stub is simply unused.
- Off-board antennas also let the two radios be separated further than the 61 mm the board allows.

**[open] Mounting.** Four M3 (or M2.5) holes for standoffs to the backplane, needed for
header retention. Corners are the natural spot; each corner hole costs ~2 header positions
on that edge, already counted above. The 100x60.96 outline footprint currently has **no
holes and no header pads**; both are added when the header footprint is built.

---

### 11.3 PCB placement as executed (2026-09-28, Konnect IPC, single-sided top assembly)

Board-local coordinates (X from the left short edge, Y from the top long edge; KiCad x = 100 + X,
y = 139.04 + Y). Everything is on F.Cu. Collision-checked against real courtyards and every Teensy pad;
DRC after placement: no shorts, no clearance errors, 499 unrouted connections (expected).

| Block | Where | Notes |
|---|---|---|
| U1 Teensy 4.1 | X 15.7-33.5, full height, USB end at the top edge, rot 180 | mounts on 2.54 mm headers; PSRAM on its underside |
| Oscillator Y1/FB1/C44-46/R59-61/C129 | under the Teensy, X 23.5-30.7, Y 6-16.5 | next to Teensy pin 23 (MCLK); clear of the D+/D-/VUSB pads |
| Teensy series Rs, SPI pull-ups, C2-C5 | under the Teensy, three columns X 20/24/28, Y 18.5-44 | clear of the USB-host pads and the PROGRAM/ON-OFF pad row; flip to B.Cu if you prefer nothing under the Teensy |
| J2 J_TDM + U5-U8/U11 + R40-47/R55/56 + C17-20/C40 | left column X 1.5-13.5 | buffers 3 mm from the header rows |
| J4 J_USBH, J12 J_ETH, J3 J_T | strip X 33.6-39.3 right of the Teensy, top to bottom | USB host and Ethernet opposite the Teensy's own pads |
| C27-C30 | X 41, Y 3-17 | 3.3 V rail decoupling |
| MIDI U4/U9/D2/C16/C21 | X 53.5-63, Y 41-56.9, right of the IDC777 | R31-R35 in a row at X 54.5-65.7, Y 34-37.7; R36-R39 in spare slots under the Teensy; J5 (MIDI header) at the top-middle X 40.7-46.8, Y 1.2-14.5 |
| DMX U17/U18/U16/D6/R71 + J10 | X 56-75, Y 8-28; C134-C139 in the strip above U17 (X 54-60.5, Y 0-8) | isolated side kept together; J10 at X 42-56 |
| U13 ESP32-S3 | X 75.3-93.8, Y 0-26.5, antenna on the top edge | R67/R68/R73/PU_EN1 row at Y 28 |
| J8 J_S3 | right edge X 94-99.5, Y 6.6-45 | |
| U19 SRC4382 + C140-149 + U20 | X 68.7-86.4, Y 30-45 | |
| U21/U23 mux + C146/C152 | X 87.6-93.6, Y 29-49.5 | |
| J6 J_SPDIF | X 39.5-68.4, Y 27.5-34 | directly left of the SRC |
| J7 J_AUX | top-middle X 47-53.1, Y 1.2-14.5 beside J5 | |
| LED IC1/C1/C33/C22/C23 + J11 | top-middle: J11 at Y 16-19.3, IC1 and the four caps in a row at Y 21.5, X 41-55 | D3/D4 at X 54-64, Y 38.1-40.3, now top-emitting SK6812-EC20 (no board windows needed) |
| U22 IDC777 + J13 u.FL (DNP) | vertical, X 40-53, Y 37.5-61, rot 90, antenna end on the BOTTOM edge; J13 at X 55.7, Y 59.4 with its RF pad toward the module, 3.5 mm from EXT_RF pad 57 (X 52.3, Y 56.8) | the IDC777 antenna is at the module's short end (keep-out pads 56/58 side), not along its long edge; antenna zone X 42.5-50.5, Y 55.9-61 must stay copper-free on all layers. Opposite edge from the S3 antenna, ~63 mm apart |
| J1 J_PWR | X 64.6-80.1, Y 41.6-46.9 | |
| U3 TPS2116 + C12-15/C31/32/34/35 + R28-30 | row Y 49.5, X 64.5-91 | |
| U24 buck + L1 + C153/154/R66/C130/131 + R57 | row Y 54, X 64-89 | |
| U15 LT3045 + FL1 + C41-43/C132/133 + R58 | row Y 58.6, X 64-87 | |
| J9 J_USB3 | X 91.6-94.4, Y 47-60 | |
| H1-H4 | 3.2 mm NPTH at the corners (3.5, 3.5) (96.5, 3.5) (3.5, 57.46) (96.5, 57.46) | on the PCB after the user's re-sync; schematic footprint changed to `MountingHole:MountingHole_3.2mm` (3.7 mm courtyard) so the next sync clears the courtyard clashes with J2/J8/J9 |

Antenna keep-outs (2026-09-28, second pass): nothing sits inside the ESP32 footprint's keep-out rectangle
(X 60.5-100, Y 0-6.3) any more, and the IDC777 was turned vertical on the bottom edge so its antenna end faces outward, opposite the S3. Both
zones still need KiCad rule areas (no copper, all layers) before pouring ground.
**IDC777 keep-out, to be added to the footprint (2026-09-28, datasheet IDC777-DTS-V003 p.8-9).** The
"Ground Clearance Area" is 8.0 x 4.44 mm at the pad-free end of the module: no metal on any layer of the
host PCB, extended to the board edge, ground vias along its boundary through all layers. In
`project_fp:IDC777-1` it exists only as four `Dwgs.User` lines (local x -11.10..-6.66, y -4.0..+4.0) and a
text note, which DRC ignores. To make it enforceable like the ESP32 footprint, open the footprint in the
Footprint Editor and add:
1. a **rule area** inside the footprint, rectangle local x -11.75..-6.66, y -4.0..+4.0 (from the module
   end to the inner edge of the antenna), all copper layers, keep out copper pours, tracks, vias and
   footprints;
2. a **F.CrtYd** rectangle over the same area so courtyard DRC catches parts placed on it.
Konnect cannot edit footprint graphics (its library toolset only creates pad layouts and edits pads).
On this board (U22 at rot 90, origin X 46.5, Y 49.21) the area lands at **X 42.5..50.5, Y 55.87..60.96**;
until the footprint carries it, draw a board rule area there (x 142.5..150.5, y 194.91..200.0 in KiCad
coordinates) and stitch ground vias along X 42.5, X 50.5 and Y 55.5. The ESP32 keep-out is drawn as
courtyard only, so it also needs a board rule area for copper: X 75.3..93.8, Y 0..6.3 (x 175.3..193.8,
y 139.04..145.34).

Known DRC leftovers: courtyard overlaps against U13 caused by the stock ESP32-S3-WROOM-1
footprint's 15 mm antenna courtyard (the module body itself is clear); U13/U20 footprint-type
attribute mismatches and the WSON thermal-via 0.2 mm drills, both inherited footprint properties.
Konnect cannot flip footprints to B.Cu, so the board is single-sided as placed.

### 11.4 Layout rework (2026-09-28, stage 10m): four header rows, three slots, two-sided assembly

The single-sided placement of 11.3 was rejected: it fitted, but the passives were dropped into
generic columns (median 9.9 mm from the pin they serve, 59 of 118 more than 10 mm away) and the
top side was 80 % courtyard. Decisions:

- **Two-sided assembly, 4-layer stack**: F.Cu signal, In1.Cu GND plane, In2.Cu power plane, B.Cu
  signal. Chips, modules, headers and every capacitor stay on the front; resistors, ferrites,
  diodes and the EN solder jumper go on the back, directly under the pin they serve.
- **Headers in four vertical rows** (X = pin-1 column, mm from the left edge), each next to the
  slot it serves, so the backplane mates four straight connector rows instead of twelve scattered
  headers. J9 was folded into J8 (2x17) and J1 trimmed to 2x5 to make the rows fit the 61 mm height.

| Row | X (pin 1 column) | Headers top to bottom |
|---|---|---|
| A (left edge) | 3.0 | J3 J_T 2x12 (Y 8.75), J12 J_ETH 2x4 (Y 40.6); sits between H1 and H3 |
| B | 35.5 | J2 J_TDM 2x13, J5 J_MIDI 2x4, J4 J_USBH 1x5 |
| C | 63.0 | J6 J_SPDIF 2x11, J1 J_PWR 2x5, J7 J_AUX 2x5 |
| D (right edge) | 94.46 | J8 J_S3 2x17 (Y 8.75; S3 GPIO, UART0, EN/IO0, I2C, USB pair, 5V); sits between H2 and H4 |
| horizontal | - | J10 J_DMX 1x5 along the bottom edge of slot 2 (X 40.5-54.2, Y 57-60.5); J11 J_LED 1x5 vertical at X 41.77 in the strip left of the IDC777 |

Revised 2026-09-28 (stage 10n) at the user's request: the two outer rows are at the board edges and
fit between the corner holes (47 mm usable), so J4 moved to row B, J1 to row C, J10 and J11 to slot 2.

| Slot | X range | Contents |
|---|---|---|
| 1 | 13.3-33.7 | Teensy U1 full height; TDM buffers U5-U8/U11 on the front under it; Teensy passives on the back |
| 2 | 39.8-61.2 | IDC777 U22 on the right (X 48.1-61.2, Y 0.4-23.9), antenna out the top edge (ground-clearance keep-out X 50.6-58.6, Y 0-5.5); in the strip to its left: J11, J13 u.FL beside pad 57, LED driver IC1 with D3/D4; DMX isolated block (U18 horizontal, U17, U16, U20) in the middle; MIDI (U4, U9, D2) at the bottom above the horizontal J10 |
| 3 | 67.3-86.7 | power (U24 + L1, U3 in the top row, U15 below) at the top; SRC4382 U19 (Y 15.5) and muxes U21/U23 (Y 28.5) in the middle; ESP32-S3 U13 at the bottom with its pads at Y 35.2-53.2 and the antenna out the bottom edge (keep-out X 68-86, Y 53.2-61) |

Antenna-to-antenna distance is about 45 mm on opposite edges. Passive placement is net-driven
(scratchpad `placer2.py`): decoupling caps at the supply pin of the chip drawn next to them in
the schematic, pull-ups and series parts at the IC pin, chains through their neighbour; accepted
only with the passive-to-pin metric reported (target median < 3 mm, nothing > 6 mm).

**Passive footprints (stage 10n, 2026-09-28):** the hand-solder 0805 footprints (3.7 x 1.9 mm courtyard)
made it impossible to seat decoupling caps at the pins, so every 0805 resistor and every capacitor up
to 10 uF is now a plain 0603 (`Capacitor_SMD:C_0603_1608Metric`, `Resistor_SMD:R_0603_1608Metric`)
with JLCPCB basic parts: 100 nF C14663, 1 uF C15849, 10 uF C19702 (10 V, X5R), 4.7 uF C19666,
resistors UNI-ROYAL 0603WAF: 0R C21189, 33R C23140, 49.9R C23185, 120R C22787, 220R C22962,
300R C23025, 1.5k C22843, 2.2k C4190 (R13/R14/R16/R17/R67/R68 were 2.21k), 5.1k C23186, 10k C25804,
33k C4216, 100k C25803. Kept: R28 16.9k 0805 (C17484, no 0603 basic part), the 22 uF / 47 uF 0805 and
the 100 uF 1206 bulk caps, the three 0402 parts. Board footprints, values and fields were synced from
the schematic with pcbnew (`swap_fp.py`, `sync_fields.py`), so a plain *Update PCB from Schematic*
reports no changes.
**Result on the board (stage 10n):** passive-to-pin median 2.2 mm (was 9.9), 6 of 118 more than 10 mm
(R1/R2 Teensy TDM2 series resistors, R11, R52, 3.3V_DIG caps in the crowded DMX / power blocks).
DRC: no shorts or clearance errors; only the stock ESP32 courtyard overlaps and inherited drill
warnings. **Open:** C31 (10 uF) and C32 (100 nF) have pin 1 connected only to each other, a leftover
pair that decouples nothing; delete or assign a rail.

### 11.5 Stage 10o (2026-09-29): Teensy in the middle, MIDI + DMX top right, SRC + IDC777 left

User request. Same four rows and two-sided rule as 11.4; contents re-dealt:

| Row | X (pin 1 column) | Headers top to bottom |
|---|---|---|
| A (left edge) | 3.0 | J6 J_SPDIF 2x11 (Y 8.75), J7 J_AUX 2x5 (Y 38.1); between H1 and H3 |
| B | 35.5 | J3 J_T 2x12 (Y 3.0), J4 J_USBH 1x5 (Y 34.9), J11 J_LED 1x5 (Y 49.0) |
| C | 63.0 | J5 J_MIDI 2x4 (Y 3.2), J2 J_TDM 2x13 (Y 14.8), J12 J_ETH 2x4 (Y 49.2) |
| D (right edge) | 94.46 | J8 J_S3 2x17 (Y 8.75); between H2 and H4 |
| horizontal | - | J1 J_PWR along the top edge of slot 1 (X 8-21.7); J10 J_DMX along the top edge of slot 3 (X 78.5-92.2) |

| Slot | X range | Contents |
|---|---|---|
| 1 | 7.3-33.7 | power (U24, L1, U3, U15) top right under J1; SRC4382 U19 (X 7.6, Y 14) with muxes U21/U23 beside it; IDC777 U22 bottom-left (X 7.4-20.5, Y 37-60.5), antenna out the bottom edge (keep-out X 9.9-18, Y 55.4-61); J13 u.FL beside its pad 57; LED driver IC1 + D3/D4 next to J11 |
| 2 | 39.8-61.2 | Teensy U1 full height centred X 50.5; TDM buffers U5-U8/U11 on the front under it (X 48.7-52.2); Teensy passives on the back |
| 3 | 67.3-92.7 | MIDI (U4, U9, D2) at the top under J10 and beside J5; DMX isolated block (U18 horizontal Y 14.2, U17, U16, U20) below it; ESP32-S3 U13 at the bottom centred X 80, pads Y 35.2-53.2, antenna out the bottom edge (keep-out X 71-89, Y 53.2-61) |

Result: passive-to-pin median 2.4 mm, 5 of 118 more than 10 mm; signal ratsnest 3.5 m (3.7 m in 10n).
DRC: only the stock ESP32 courtyard overlaps and inherited drill warnings; parity clean apart from
board_outline2. Both antennas are on the bottom edge, 53 mm apart (IDC777 X 10-18, S3 X 71-89).

**Stage 10p (2026-09-29, user request):** SRC4382 U19 moved under the Teensy, on the front, below the
Teensy's interior VBAT/3V3/PROGRAM/ON-OFF pad row (box X 45.3-55.6, Y 49-59.3, between the two pin
columns at X 42.9 and 58.1). Muxes U21/U23 stay in the left slot at X 7.6 (Y 14-25.5). The Teensy on
8.5 mm headers leaves room for the 1.2 mm TQFP under it. Cost: the SRC's six 1V8/3V3 caps cannot sit
beside it (1.6 mm to the pin columns) and land 4.5-11 mm away above the pad row; the S/PDIF pairs from
J6 (left edge) now run about 40 mm to the SRC. Passive-to-pin median 2.6 mm, 8 of 118 more than 10 mm.

**Stage 10q (2026-09-29, user request):** the two 74LVC157 muxes U21/U23 go with the SRC: both under the
Teensy, rotated 90, side by side at X 45-50.5 / 51-56.5, Y 38.5-46.2, just above the interior pad row;
the SRC sits below that row (Y 49-59.3). The five TDM buffers moved up to Y 5-34 (5.9 mm pitch) to make
room. "SRC" in the user's instructions means SRC4382 plus its two muxes. Passive-to-pin median 3.3 mm.

**Stage 10r (2026-09-29, user request): TDM fan-out buffers consolidated.** The four SN74LVC2G125
(U5-U8, all enables hard-wired low) that copied LRCK1 / MCLK1 / BCLK1 and the two Teensy TDM data
outputs to J2 are replaced by one **SN74LVC541APWR** (U5, TSSOP-20, LCSC C113281, extended part).
Group A (OE1, pin 1, grounded) = TDM1 copies: Y0 LRCK1 -> R42, Y1 MCLK1 -> R41, Y2 BCLK1 -> R44,
Y3 OUT1A -> R46. Group B (OE2, pin 19 = `TDM2_OE`) = TDM2 copies: Y4 LRCK1 -> R43, Y5 MCLK1 -> R40,
Y6 BCLK1 -> R45, Y7 OUT1D -> R47. `TDM2_OE` is held low by solder jumper **JP1** (bridged,
`Jumper:SolderJumper-2_P1.3mm_Bridged`) with 10k pull-up **R74** to 3.3V: cut JP1 to tri-state
the whole TDM2 clock/data set when a backplane device (Pi CM) is the TDM2 clock master. The
series resistors R40-R47 and U11 (the 2G125 on the Teensy-input lines) are unchanged; C18-C20
removed, C17 is the 541's decoupling cap. Net names between U5 and the resistors: `TDM1_*_B`,
`TDM2_*_B`. Board synced with pcbnew (`swap_fp.py` now also adds/removes footprints and sets pad
nets from the netlist; `sync_fields.py` refreshes values, fields and pad nets). U5 sits at the top
of the column under the Teensy (X 47-54, Y 5-12.7), U11 below it.

### 11.6 Stage 10s (2026-09-29): holistic re-spacing, S3 and IDC777 swapped

User request: keep the flow (power top-left, TDM buffers middle, MIDI/DMX top-right) but give every part
air, and try the S3 in the wider left slot. Result:

| Row | X (pin 1 column) | Headers top to bottom |
|---|---|---|
| A (left edge) | 3.0 | J8 J_S3 2x17 (Y 8.75), next to the S3 |
| B | 35.5 | J3 J_T 2x12 (Y 3.0), J4 J_USBH 1x5 (Y 34.9), J11 J_LED 1x5 (Y 49.0) |
| C | 63.0 | J5 J_MIDI 2x4 (Y 3.2), J2 J_TDM 2x13 (Y 14.8), J12 J_ETH 2x4 (Y 49.2) |
| D (right edge) | 94.46 | J6 J_SPDIF 2x11 (Y 8.75), J7 J_AUX 2x5 (Y 38.1) |
| horizontal | - | J1 J_PWR top edge of slot 1 (X 8-21.7); J10 J_DMX top edge of slot 3 (X 78.5-92.2) |

| Slot | X range | Contents |
|---|---|---|
| 1 | 7.3-33.7 | power row under J1 (U24 X 9, L1 X 15, U3 X 21.8, U15 X 26.6, all Y 7.5-12.3); ESP32-S3 U13 centred X 20, pads Y 35.2-53.2, antenna out the bottom edge (keep-out X 11-29, Y 53.2-61); LED driver IC1 + D3/D4 in the strip X 29.8-32.8 beside the S3, next to J11 |
| 2 | 39.8-61.2 | Teensy U1 centred X 50.5; under it U5 (SN74LVC541A, Y 5-12.7), U11 (Y 15.2-20.7), muxes U21/U23 (Y 38.5-46.2), SRC4382 U19 (Y 49-59.3) |
| 3 | 67.3-92.7 | MIDI U4 (X 69.2-80.2, Y 5-14), U9, D2; DMX block U18 horizontal (Y 15.5-22), U17 (X 69.2-81, Y 23.5-34.3), U16/U20 (X 83.6-91); IDC777 U22 (X 69.2-82.3, Y 37-60.5) antenna out the bottom edge (keep-out X 71.7-79.8, Y 55.4-61); J13 u.FL beside pad 57 at X 82.4-86.8 |

Every chip has at least 1.6 mm to the nearest header courtyard and 2 to 3 mm to the next chip; the
passive placer margin is now 0.35 mm part-to-part (was 0.15). Antennas 45 mm apart on the bottom edge.
Passive-to-pin median 3.4 mm, 11 of 116 more than 10 mm. DRC: only the stock ESP32 courtyard overlaps
and the inherited drill warnings; parity clean apart from board_outline2.
**Open:** the 49.9 ohm series resistors (20x) may move to 0402 or to 4-element 0804 arrays
(Yageo AF124-FR-0749R9L, LCSC C6463554, extended); no MELF 0204/0206 49.9 ohm is stocked at JLCPCB.

**Stage 10t (2026-09-29, user request):** IDC777 moved as far right as its u.FL allows (U22 X 74.6-87.7,
J13 X 87.8-92.2, antenna keep-out X 77.1-85.2, Y 55.4-61; 45.6 mm clear between the S3 body and the
IDC777 body). J8 lowered to Y 9.7-53.9 so it sits beside the S3; row B is now J4 J_USBH (Y 1.2-14.9,
beside the Teensy host pads) / J3 J_T (Y 15.3-46.8) / J11 J_LED (Y 47.2-60.9). Nothing else moved.
**Series terminations (stage 10u):** user accepts anything from 22 to 100 ohm, easy to source. JLCPCB
stocks no 22-100 ohm MELF (0204/0206); chosen: **33 ohm 0402, Uniroyal 0402WGF330JTCE, LCSC C25105**
(basic part), footprint `Resistor_SMD:R_0402_1005Metric`, on R1-R7, R9, R10, R40-R47, R52, R55, R56
(twenty parts, were 49.9 ohm 0603). 22 ohm C25092 and 100 ohm C25076 are the basic alternatives.

**Stage 10v (2026-09-29, user request): OUT1B buffered, OUT1B and OUT1C direction-switchable.**
Before: OUT1A/OUT1D were output-only through the 541, IN1 and OUT1C input-only through U11, and
OUT1B (Teensy pin 32) reached the backplane only as raw GPIO `T32_OUT1B` on J3 pin 20 through R5.
Now: **U6** (SN74LVC2G125, C206035) buffers OUT1B in both directions to **J2 pin 27** (`32_OUT1B`;
J2 is a 2x14, pin 28 GND): half 1 Teensy -> J2 through R75 (33 ohm), half 2 J2 -> Teensy through
R76. **U7** (2G125) adds the Teensy -> J2 direction for OUT1C through R81 next to the existing U11
input half; U7's spare half is parked (2A GND, 2OE high, 2Y NC). Direction is chosen with 0 ohm
0402 jumper pairs (C17477) on the enable pins, one of each pair fitted:

| Line | Enable net | to GND | to 3.3V | Default |
|---|---|---|---|---|
| OUT1B output (U6 half 1) | `OUT1B_OE_OUT` | R77 fitted | R78 DNP | output |
| OUT1B input (U6 half 2) | `OUT1B_OE_IN` | R79 DNP | R80 fitted | disabled |
| OUT1C output (U7 half 1) | `OUT1C_OE_OUT` | R82 DNP | R83 fitted | disabled |
| OUT1C input (U11 half 2) | `OUT1C_OE_IN` | R84 fitted | R85 DNP | input |

To turn a line around, move both jumpers of that line. Never fit both enables of one line low.
`T32_OUT1B` stays on J3 pin 20 as the raw pin (it is the buffer's Teensy-side node). C18/C19 are
the new decoupling caps. Row C on the board: J5 pin 1 Y 3.2, J2 (2x14) pin 1 Y 14.4, J12 pin 1 Y 51.0.

**Stage 10w (2026-09-29, user request):** LED driver IC1 (X 17.8-22.3, Y 21-23.6) with D3/D4 below it
(Y 25.6-28) moved to the middle of the left column, in the free band between the power row and the S3.
J11 stays at the bottom of row B.

### 11.7 Stage 10x (2026-09-30): mandatory external supply, protected input, isolated USB device ports

**Power entry.** The TPS2116 mux (U3), its PR1 divider R28/R29/R30 and the Teensy-USB bulk caps
C13/C14 are gone; Teensy VUSB (pin 49) is NC (the VUSB-VIN pad is cut on every Teensy, so the
Teensy jack is a data-only service port). `5V_IN` (J1 pins 1/2) -> **D7** SMAJ5.0A TVS to GND
(C78401) -> **Q1** AO3401A P-MOSFET reverse-polarity protection (C15127; drain 5V_IN, source
`5V`, gate GND) -> `5V` rail (PWR_FLAG #FLG10). The core needs the external supply to run; a PC
USB port no longer powers it. J1 pins 5/6 stay 5V outputs. Current budget: change map section 7.

**USB isolation on the core (decision: both device ports, host port stays direct).** Two
**ISOUSB211DPR** (TI, high-speed USB isolator, LCSC C5772877, extended, ~$11), one per port:
- S3 port: module side `S3_USB_DN_M`/`S3_USB_DP_M` (U13 pins 13/14) -> isolator side 2 (DD-/DD+,
  VCC2/VBUS2 from `5V`, GND2 = GND); laptop side -> J8 pins 31 `S3_USB_DN`, 32 `S3_USB_DP`,
  33 `S3_USB_GND`, 34 `S3_VBUS` (was GND / 5V). Side 1 is powered from the laptop's VBUS.
- Teensy device port: Teensy pads 66/67 (`T_USB_DN_M`/`T_USB_DP_M`) -> isolator side 2; laptop
  side -> **J4 J_USB 2x5** even row: 2 `T_USB_GND`, 4 `T_USB_DN`, 6 `T_USB_DP`, 8 `T_USB_GND`,
  10 `T_VBUS`. The odd row keeps the unisolated host port: 1 GND, 3 HOST_D1-, 5 HOST_D1+, 7 GND,
  9 HOST_5V.
- `S3_USB_GND` and `T_USB_GND` are isolated grounds: never tie them to core GND or to each other,
  on the core or on a backplane. A backplane wires each jack straight to its four pins; VBUS must
  be brought in (it powers the isolator's laptop side).
- Symbol `ISOUSB211DPR:ISOUSB211DPR` (lib_sch/ISOUSB211DPR.kicad_sym, made from the datasheet pin
  table) and footprint `project_fp:SSOP-28_7.5x10.3mm_P0.65mm_ISO` (IPC land pattern, 8.2 mm
  clearance between the pad rows) were created with Konnect. **Manual step:** place two instances
  (U25 for the S3 port, U26 for the Teensy port) in eeschema; Konnect cannot place project-library
  symbols. Wiring after placement: EQxx to GND (default equalisation), CDPENZx to the local 3.3 V
  (CDP off), V1OK/V2OK NC, caps per datasheet 8.3 (1 uF on VBUSx, 0.1 uF on V3P3Vx, 2 uF + 0.1 uF
  + 10 nF on V1P8Vx; pins 4-11 and 18-25 tied), 45 ohm-ish 90 ohm differential routing, no vias
  on D+/D- (datasheet 8.4).

> The USB-isolation half of stage 10x was **reversed in stage 10y** (below): no isolators, all
> three ports unisolated on the headers. The ISOUSB211DPR symbol library, its SSOP-28 footprint
> and the sym-lib-table entry are still in the repo, unused; remove them in the KiCad library
> manager when convenient.

### 11.8 Stage 10y (2026-10-01): SAI2 aux input block replaces the SRC4382 + muxes + S/PDIF header

**Why.** The SRC4382 was the only consigned, non-stock IC on the core, it has no TDM mode, and the
Teensy can resample in software. The user's design note "SAI2 input routing + expansion header"
replaced the hardware ASRC path with a plain, interlocked SAI2 port. S/PDIF is served by the
Teensy's own pins 14/15 on J3 (J6 removed).

**Architecture (schematic commit 026acc0, board 0dd4533).** One asynchronous I2S source at a time
enters the Teensy's SAI2 (pins 4 BCLK2, 3 LRCLK2, 5 IN2, 2 OUT2, 33 MCLK2); SAI1 stays the TDM
engine for the codec backplane. Every driver reaches the shared `SAI2_*` / `AUX_I2S_*` nets through
its own 33 R 0402 (C25105), and a 74LVC138 interlock guarantees that only one driver group is ever
enabled:

| Part | Function | Enable |
|---|---|---|
| U19 SN74LVC257APWR (TSSOP-16, C205921) | 2:1 mux, A = IDC777 `BT_BCK/BT_LRCK/BT_SDATA`, B = S3 `S3_I2S_BCK/LRCK/DOUT`; S = `SAI2_SEL` (Teensy 22 = T22, 10 k pull-down: 0 = IDC777, 1 = S3). Outputs -> 33 R -> `SAI2_BCLK/LRCLK/IN`. Channel 4 inputs grounded, 4Y NC. | `SAI2_nOE_INT` = U23 Y0 (mode 00) |
| U21 SN74LVC244APWR (TSSOP-20, C7668) | Group 1 (core slave, header master): `AUX_I2S_BCK/LRCK` -> 33 R -> `SAI2_BCLK/LRCLK`; `SAI2_MCLK` -> 33 R -> `AUX_I2S_MCLK`; `SAI2_OUT` -> 33 R -> `AUX_I2S_DOUT`. Group 2 (core master): `SAI2_BCLK/LRCLK/MCLK/OUT` -> 33 R -> `AUX_I2S_BCK/LRCK/MCLK/DOUT`. | group 1 `SAI2_nOE_HDR` = Y1 (mode 01); group 2 `SAI2_nOE_OUT` = Y2 (mode 10) |
| U20 SN74LVC2G125DCTR (SOP-8, C206035) | `AUX_I2S_DIN` -> gate 1 and gate 2 (inputs tied) -> 33 R each -> `SAI2_IN` | gate 1 Y1, gate 2 Y2 (either header mode) |
| U23 SN74LVC138APWR (TSSOP-16, C485077) | A1:A0 = `SAI2_MODE1:MODE0` (Teensy 27/26 = T27/T26, 10 k pull-ups C25744), A2/E1/E2 GND, E3 3.3V_DIG; Y3-Y7 NC | - |

Mode table (firmware contract; the power-on default is 11 = everything tri-stated):

| MODE1:0 | Core role | Clock source | Enabled | Teensy SAI2 |
|---|---|---|---|---|
| 00 | internal | IDC777 or S3 (by `SAI2_SEL`) is I2S master | U19 | slave (BCLK2/LRCLK2 inputs), MCLK2 unused |
| 01 | header **slave** | external device on J_SAI2 is master | U21 group 1, U20 gate 1 | slave; MCLK2 still output to the header (buffered) |
| 10 | header **master** | Teensy is master | U21 group 2, U20 gate 2 | master (BCLK2/LRCLK2/MCLK2 outputs) |
| 11 | off | - | nothing | idle |

The firmware must set MODE and SEL **before** starting SAI2 and must never leave a Teensy-driven
clock enabled while switching to 00 or 01 (the 33 R resistors limit, but do not prevent, contention
during a bad sequence). Decoupling: 100 nF 0603 (C14663) C140 (U19), C141 (U21), C142 (U23),
C143 (U20). All four ICs run from `3.3V_DIG`.

**J_SAI2 = J7 (2x6, right edge, row D).** 1 GND, 2 GND, 3 `AUX_I2S_MCLK`, 4 GND, 5 `AUX_I2S_BCK`,
6 GND, 7 `AUX_I2S_LRCK`, 8 GND, 9 `AUX_I2S_DIN` (into the core), 10 `AUX_I2S_DOUT` (out of the
core), 11 `3.3V_DIG`, 12 `5V`. A GND flanks every clock in the even row. The old J_AUX 2x5
assignment and J6 J_SPDIF 2x11 are gone.

**Other pin moves.** J3 pins 17/18/19/22 (were T22/T26/T27/MCLK2) are GND. BT_RST and
BT_SYS_CTRL, previously SRC GPOs, now come from S3 IO40 / IO41; J8 pins 25/26 (were IO40/IO41)
are GND. USB: see section 6 (revised) and the note above 11.8.

**Removed.** U19 SRC4382 + C144-C149/C152 + R1/R2/R10, U20 TLV75718 1V8 LDO, U21/U23 74LVC157,
J6, the `+1V8` rail, the `SPDIF_RX*/TX*`, `SRC_A_*`, `MUX1_*`, `AUX_SEL`, `BT_S3_SEL` nets.

**Board.** U19/U23 sit under the Teensy at Y 38.5 (slot 2, where the two 157 muxes were); U21 in the
right column under U16 at (83.6, 29.3) and U20 beside the IDC777 at (88.4, 38.5, 90), both next to
J7; D7/Q1 (stage 10x) in the power row where the TPS2116 was. 131 passives re-placed two-sided
(median 2.4 mm, mean 3.4 mm to their pin; 8 beyond 10 mm). Three stray `/OUT1B_MCU` track
fragments from the old design were removed; the board has no routing. DRC with schematic parity:
only the pre-existing U13 courtyard (the module's antenna keep-out) against H3/J11, the U13 0.2 mm
thermal-via holes and the `board_outline2` outline footprint remain.

**Verification.** `kicad-cli sch export netlist` diffed against the stage 10x netlist: only the
nets listed above changed; ERC adds no violation versus commit 1c8bd6e (one pre-existing error:
D3 GND is a power-input pin on the project LED symbol). Hazard found on the way: Konnect
`add_schematic_text` writes literal newlines into the text string, which KiCad refuses to load;
multi-line notes must be separate single-line texts. Konnect `batch_delete` with a symbol's pin
uuid deletes the whole symbol (D3 had to be re-placed from the committed file).

### 11.9 Stage 10z (2026-10-02): DMX leaves the core

**Decision.** The isolated DMX block moves to its own board, `t-dsp_dmx_module` (sibling project
folder). MIDI stays on the core. Reasons: isolation belongs at the XLR jack (with the isolator on
the core, every backplane had to continue the barrier around J10), the isolated corner and its
plane split were the main obstacle to routing the core, and it cost about 9 USD per core plus
four Extended parts and the only tall through-hole component.

**Core schematic (commit f956de6).** Removed U16 THVD1450, U17 ISO7762, U18 TRACO TEA1-0505HI,
D6 SM712, R71, C134-C139 and the nets `5V_ISO`, `DMX_GND`, `DMX_A/B`, `DMX_*_ISO`. J10 `J_DMX`
is a 2x4 logic-level header: 1 GND, 2 GND, 3 `DMX_TX`, 4 `DMX_RX`, 5 `DMX_DE`, 6 `3.3V_DIG`,
7 `5V`, 8 GND. The three signals are ESP32-S3 pins (U13 5, 39, 25), so the port also serves any
other UART or RS-485 device.

**Core board (commit cfb9e5e).** J10 sits on row B at Y 49 beside the S3. Slot 3 is MIDI at the
top, U21 at (83.0, 27.5) beside J_SAI2 and the IDC777 at the bottom, with the area between
MIDI and U21 free. No isolation barrier and no plane split remain. New rule area `IDC777_ANT`
(all four copper layers, X 77.1-85.2, Y 55.4 to the edge) keeps copper out from under the BT
antenna; the stock footprint only had a silkscreen keep-out. 123 passives re-placed (median
2.4 mm, mean 3.3 mm, 7 beyond 10 mm). DRC with parity: only the S3 antenna courtyard (vs H3 and
J10), its 0.2 mm via holes and the outline footprint.

**The module.** ISO7731DWR (C524804) + B0505S-1WR3 (C7465178) + THVD1450DR + SM712, Neutrik
NC5FAH 5-pin XLR plus a 3-pin header, 63.9 x 31 mm, 2 layers, routed, about 3.10 USD of
semiconductors. Its J1 mates 1:1 with J10. Details in that project's README.

**Still open before routing the core:** the Ethernet decision (J12 nets are single-node until
the U1 symbol and footprint swap, or J12 is dropped), the In2 power-plane split (5V, 3.3V,
3.3V_DIG, V_BAT) and a differential-pair net class for the two USB pairs.

### 11.10 Stage 11a (2026-10-02): four GPIO columns

User requirement: every header in one of four columns so a backplane is easy to route, with pins
in the order of the chip pads they come from.

| Column | X (mm) | Headers, top to bottom | Content |
|---|---|---|---|
| A, left edge | 3.0 | J8 2x17 | ESP32-S3 IO, in module pad order |
| B, left of Teensy | 35.5 | J2 2x14, J7 2x6 | TDM1/TDM2 + I2C, SAI2 aux I2S |
| C, right of Teensy | 63.0 | J4 2x5, J3 2x12, J12 2x4 | Teensy USB host + device, Teensy GPIO, Ethernet |
| D, right edge | 94.46 | J5 2x4, J11 1x5 | MIDI, LED |

J1 (power) stays horizontal on the top edge. J10 is gone: with DMX on its own module the three S3
pins are plain GPIO on J8 as `S3_IO5`, `S3_IO1`, `S3_IO48`. T38-T40 moved from J8 to J3 pins
17-19, so column A carries only S3 pins and column C only Teensy pins.

**J8 pin order** follows the module perimeter as seen from the header, so traces leave the module
without crossing: far-side pads (EN, IO5, IO15, IO18, IO8, USB D-/D+ with GND and 5V) at the top,
the pad row facing the Teensy side next (IO9, IO10, IO11, SDA, SCL, IO48, IO45), then the pads
that face the header (IO0, IO38, IO39, IO42, RXD0, TXD0, IO2, IO1). Pin table in section 13.

**Board (schematic 59258c2).** LED driver IC1 and the LEDs D3/D4 sit beside J11 in the right
slot; MIDI parts at the top right beside J5; the SAI2 header buffer U21 and gate U20 moved under
the Teensy at the bottom beside J7. The Teensy footprint is now `project_fp:Teensy41` (user
change, Ethernet pads 60-65 present), so U11/U6/U7 start at Y 19.5 below those pads. MST ratsnest
length fell from 4415 mm to 3900 mm; 123 passives at median 2.2 mm / mean 3.1 mm from their pin.
DRC with parity: only the S3 antenna courtyard (vs H3, J7), its via holes and the outline footprint.

## 12. Edit order and verification

1. Commit the July 27 work as-is (BT/ASRC block + libraries) so it is not only in the
   working tree.
2. Deletions (§1, §9) → ERC drops from 466 to something readable.
3. Wireless block rewire (§2, §3, §4) → netlist check: each of `4_BCLK2`, `3_LRCLK2`,
   `5_IN2`, `2_OUT2` has exactly Teensy + SRC (+ series R); `S3_I2S_*` each has S3 + U21;
   `BT_RST`/`BT_SYS_CTRL`/`BT_S3_SEL`/`AUX_SEL` each has SRC GPO + load; `SRC_RST` on
   ESP32_EN.
4. Power (§7) → netlist check: `3.3V` sourced by U15 only; Teensy pin 46 isolated; VUSB on
   VIN2; no node on the old USB-C nets.
5. Slave-clock jumpers (§8), EN pull-up (§6), aux mux (§2.1).
6. Header footprint + pin map (§5); assign the five missing footprints; update PCB from
   schematic.
7. Fix Konnect layer count; choose outline; place antenna keepout; then layout.

All schematic edits go through Konnect and are verified with
`kicad-cli sch export netlist`, per the project's write-hazard rules.

## 13. Header pin map (spin 2, function-scoped headers, as wired 2026-10-02)

Generated from the kicad-cli netlist of schematic commit 59258c2 (stage 11a). The four 2x22 edge blocks (176 pins) are gone. J9 (S3 USB) was folded into J8 and J1 trimmed to 2x5 on 2026-09-28 (stage 10m); J6 (S/PDIF) was removed and J7 became the 2x6 J_SAI2 port on 2026-10-01 (stage 10y); J10 (DMX) was removed on 2026-10-02 and its S3 pins became plain GPIO on J8 (stage 11a). The nine headers sit in four columns (section 11.10): J8 on the left edge (ESP32-S3 IO, pins in module pad order), J2 + J7 left of the Teensy (audio buses), J4 + J3 + J12 right of the Teensy (Teensy USB, GPIO, Ethernet), J5 + J11 on the right edge (MIDI, LED); J1 power lies along the top edge. Each function has its own stock
`Connector_Generic` header placed next to the chip that serves it, so the PCB traces are short and
the backplane only needs to mate the headers it uses. Ground rule applied to every header: at least
one GND per three signals, a GND row (both rows) on both sides of every clock and every differential
pair, and GND at both ends of every header.

| Ref | Name | Size | Placed next to | Pins | GND |
|---|---|---|---|---|---|
| J8 | `J_S3` | 2x17 | ESP32-S3 U13 | 34 | 11 |
| J2 | `J_TDM` | 2x14 | TDM buffers U5/U6/U7/U11 under the Teensy | 28 | 13 |
| J7 | `J_SAI2` | 2x6 | U21 244 buffer / U20 2G125 gate | 12 | 5 |
| J4 | `J_USB` | 2x5 | Teensy USB host pads and device pads 66/67 | 10 | 5 |
| J3 | `J_T` | 2x12 | Teensy 4.1 | 24 | 10 |
| J12 | `J_ETH` | 2x4 | Teensy 4.1 Ethernet pads | 8 | 3 |
| J5 | `J_MIDI` | 2x4 | MIDI opto/buffer U4/U9 | 8 | 2 |
| J11 | `J_LED` | 1x5 | SK6812 level shifter IC1 | 5 | 2 |
| J1 | `J_PWR` | 2x5 | TVS D7 / P-FET Q1 / buck U24 / LT3045 U15 | 10 | 3 |
| | | | **total** | **139** | **54** |

Footprints: `Connector_PinHeader_2.54mm:PinHeader_<size>_P2.54mm_Vertical`. Odd pins are one row, even
pins the other (KiCad Odd_Even numbering). `DMX_GND` is the isolated ground, not core GND.
Net names are the current schematic names; the raw-GPIO rename (T_nn / S3_IOnn) is a later cosmetic
pass and does not change connectivity.

### J8 - `J_S3` 2x17, next to ESP32-S3 U13

S3 UART0 (also Teensy Serial7), EN/IO0, I2C, raw GPIO, and the S3 native USB (OTG) pair with 5V (pin 34 = core 5 V rail: wire to a jack VBUS only for host use). IO40/IO41 left the header in stage 10y (BT_RST / BT_SYS_CTRL); pins 25/26 are GND. IO35-37 are consumed by the octal PSRAM.

| odd | net | even | net |
|---|---|---|---|
| 1 | `GND` | 2 | `GND` |
| 3 | `S3_EN` | 4 | `S3_IO5` |
| 5 | `S3_IO15` | 6 | `S3_IO18` |
| 7 | `S3_IO8` | 8 | `GND` |
| 9 | `S3_USB_DN` | 10 | `S3_USB_DP` |
| 11 | `GND` | 12 | `5V` |
| 13 | `S3_IO9` | 14 | `S3_IO10` |
| 15 | `S3_IO11` | 16 | `GND` |
| 17 | `S3_IO21_SDA` | 18 | `S3_IO47_SCL` |
| 19 | `S3_IO48` | 20 | `S3_IO45` |
| 21 | `GND` | 22 | `GND` |
| 23 | `S3_IO0_BOOT` | 24 | `S3_IO38` |
| 25 | `S3_IO39` | 26 | `S3_IO42` |
| 27 | `GND` | 28 | `GND` |
| 29 | `/S3_IO44_RXD0` | 30 | `/S3_IO43_TXD0` |
| 31 | `S3_IO2` | 32 | `S3_IO1` |
| 33 | `GND` | 34 | `GND` |

### J2 - `J_TDM` 2x14, next to TDM buffers U5/U6/U7/U11 under the Teensy

Both TDM buses plus the two I2C buses for codec control. GND on both flanks of every clock; TDM1 in the odd row, TDM2 in the even row. Pin 27 (since stage 10v) is the buffered OUT1B line whose direction is set by 0 ohm jumpers.

| odd | net | even | net |
|---|---|---|---|
| 1 | `GND` | 2 | `GND` |
| 3 | `MCLK1+TDM1` | 4 | `MCLK1+TDM2` |
| 5 | `GND` | 6 | `GND` |
| 7 | `BCLK1+TDM1` | 8 | `BCLK1+TDM2` |
| 9 | `GND` | 10 | `GND` |
| 11 | `LRCK1+TDM1` | 12 | `LRCK1+TDM2` |
| 13 | `GND` | 14 | `GND` |
| 15 | `7_OUT1A+` | 16 | `6_OUT1D+` |
| 17 | `8_IN1` | 18 | `9_OUT1C_INPUT` |
| 19 | `GND` | 20 | `GND` |
| 21 | `T18_SDA0` | 22 | `T17_SDA1` |
| 23 | `T19_SCL0` | 24 | `T16_SCL1` |
| 25 | `GND` | 26 | `GND` |
| 27 | `32_OUT1B` | 28 | `GND` |

### J7 - `J_SAI2` 2x6, next to U21 244 buffer / U20 2G125 gate

Teensy SAI2 as an expansion I2S port (stage 10y, section 11.8). Core is header master (MODE 10) or header slave (MODE 01) by firmware; MCLK is always sourced by the core. DIN is into the core, DOUT out of it. GND flanks every clock.

| odd | net | even | net |
|---|---|---|---|
| 1 | `GND` | 2 | `GND` |
| 3 | `AUX_I2S_MCLK` | 4 | `GND` |
| 5 | `AUX_I2S_BCK` | 6 | `GND` |
| 7 | `AUX_I2S_LRCK` | 8 | `GND` |
| 9 | `AUX_I2S_DIN` | 10 | `AUX_I2S_DOUT` |
| 11 | `3.3V_DIG` | 12 | `5V` |

### J4 - `J_USB` 2x5, next to Teensy USB host pads and device pads 66/67

Odd row: Teensy host pair, GND flanked, HOST_5V is the host-port VBUS. Even row: Teensy device pair (pads 66/67) with GND on 2/8/10; no VBUS pin, the Teensy VUSB is NC. Neither port is isolated (stage 10y).

| odd | net | even | net |
|---|---|---|---|
| 1 | `GND` | 2 | `GND` |
| 3 | `HOST_D1-` | 4 | `T_USB_DN` |
| 5 | `HOST_D1+` | 6 | `T_USB_DP` |
| 7 | `GND` | 8 | `GND` |
| 9 | `HOST_5V` | 10 | `GND` |

### J3 - `J_T` 2x12, next to Teensy 4.1

Teensy S/PDIF (the only S/PDIF path since stage 10y), CAN3, Serial8, PROGRAM/ON_OFF, buttons, OUT1B. Pins 17/18/19/22 are GND since stage 10y (T22/T26/T27/MCLK2 now serve the SAI2 block).

| odd | net | even | net |
|---|---|---|---|
| 1 | `GND` | 2 | `GND` |
| 3 | `T14_SPDIF_OUT` | 4 | `T15_SPDIF_IN` |
| 5 | `GND` | 6 | `GND` |
| 7 | `T30_CRX3` | 8 | `T31_CTX3` |
| 9 | `T35_TX8` | 10 | `T34_RX8` |
| 11 | `T_PROGRAM` | 12 | `T_ON_OFF` |
| 13 | `T24` | 14 | `T25` |
| 15 | `GND` | 16 | `GND` |
| 17 | `T38` | 18 | `T39` |
| 19 | `T40` | 20 | `T32_OUT1B` |
| 21 | `GND` | 22 | `GND` |
| 23 | `GND` | 24 | `GND` |

### J12 - `J_ETH` 2x4, next to Teensy 4.1 Ethernet pads

Teensy 4.1 10/100 PHY pairs and link LED from pads 60-65 (needs the U1 symbol swap, see 14.1). Magnetics and RJ45 on the backplane.

| odd | net | even | net |
|---|---|---|---|
| 1 | `ETH_R+` | 2 | `ETH_R-` |
| 3 | `GND` | 4 | `GND` |
| 5 | `ETH_T+` | 6 | `ETH_T-` |
| 7 | `ETH_LED` | 8 | `GND` |

### J5 - `J_MIDI` 2x4, next to MIDI opto/buffer U4/U9

Jack-level MIDI IN / OUT / THRU (DIN pins 4 and 5 across the rows).

| odd | net | even | net |
|---|---|---|---|
| 1 | `MIDI_IN_4` | 2 | `MIDI_IN_5` |
| 3 | `MIDI_OUT_4` | 4 | `MIDI_OUT_5` |
| 5 | `MIDI_THRU_4` | 6 | `MIDI_THRU_5` |
| 7 | `GND` | 8 | `GND` |

### J11 - `J_LED` 1x5, next to SK6812 level shifter IC1

5 V SK6812 data outs from the Teensy and the S3, GND between, 5V for the strip.

| pin | net |
|---|---|
| 1 | `GND` |
| 2 | `TEENSY_LED_OUT` |
| 3 | `GND` |
| 4 | `ESP32_LED_OUT` |
| 5 | `5V` |

### J1 - `J_PWR` 2x5, next to TVS D7 / P-FET Q1 / buck U24 / LT3045 U15

Power entry and rails. 5V_IN (mandatory external 5 V since stage 10x) feeds the TVS + reverse-polarity P-FET; 5V, 3.3V (LT3045, analog), 3.3V_DIG (buck) and V_BAT are outputs.

| odd | net | even | net |
|---|---|---|---|
| 1 | `5V_IN` | 2 | `5V_IN` |
| 3 | `GND` | 4 | `GND` |
| 5 | `5V` | 6 | `5V` |
| 7 | `3.3V` | 8 | `3.3V_DIG` |
| 9 | `V_BAT` | 10 | `GND` |

## 14. Status after the 2026-09-28 edit session

Done (all verified with `kicad-cli sch export netlist` diffs, zero unexpected net changes):

- §1 deletions: 129 backplane parts, old DevKitC, pseudo net-map symbols, dead branches.
- §2 wireless block: Port B on Teensy I2S2, reverse path, GPO control lines, S/PDIF labels,
  U23 aux mux cascade, R72 SYS_CTRL pulldown, R73 EN pull-up. **S3 IO46 drives the SK6812
  chain (`ESP32_LED`)** because the old DevKitC GPIO5 went away; IO46 is therefore not on
  the header (J4.35 is RESERVED).
- §7 power: AP63203 buck (U24 + L1 + C153 + C154) replaces the TLV76733; LT3045 owns the
  3.3V rail; Teensy 3V3 pins NC; VUSB → TPS2116 VIN2 (`5V_VUSB`); VIN1 = `5V_IN` from J1.
  PWR_FLAGs on 3.3V_DIG, V_BAT, 5V_IN, the LT3045 input, U9 VCC, Y1 VDD, U4 pins 5/6.
- §5/§13 headers: J1–J4 wired, 176 pins checked against the pin map.
- Cleanups: SPI-link and I2S2 labels made global; C129 GND restored; no-connect flags on
  every intentionally unused pin; C129/C48 footprints fixed; no symbol overlaps.

Residual ERC (kicad-cli, all severities):

| Count | Item | Meaning |
|---|---|---|
| 1 | `power_pin_not_driven` D3 pin 4 (GND) | ERC quirk; the netlist shows D3.4 on GND with 47 GND power symbols and the Teensy GND pins. A PWR_FLAG on GND collides with the Teensy symbol's GND pins being typed *Output* (`pin_to_pin`). Leave, or retype those pins in the Teensy symbol. |
| 50 + 56 | `lib_symbol_issues` / `lib_symbol_mismatch` | cached symbols differ from the libraries; fix in eeschema with *Tools → Update Symbols from Library*. Not touchable through Konnect. |
| 30 | `unconnected_wire_endpoint` | pre-existing wire overshoots past labels (cosmetic). |

Not done / next:

1. **External MCLK (user wants it — §10 #3 decided):** the hardware is already right. Y1
   (24.576 MHz = 512·fs) reaches MCLK1 through R61 (33 Ω); Teensy pin 23 reaches MCLK1
   through R7 (49.9 Ω). Population rule, now printed on the schematic next to Y1:
   - **External-MCLK build:** R59 populated (Y1 enabled), R60 DNP. Firmware must make the
     Teensy's SAI1 MCLK pin an input: clear `SAI1_MCLK_DIR` in `IOMUXC_GPR_GPR1`, then
     run SAI1 with MSEL = MCLK1 so BCLK/LRCK are divided from the external clock. The
     Teensy audio library sets MCLK as output; this is a small patch in the SAI init
     (`output_i2s.cpp` / the F32 TDM variant in `t-dsp_software/lib`). Not written yet.
   - **Default build until then:** R60 populated (Y1 in standby, output high-Z), R59 DNP;
     Teensy drives MCLK1 at 256·fs. Never populate both: two drivers through 33 Ω + 49.9 Ω.
   - The SRC accepts either clock; the TDM codecs on the backplane must accept the chosen
     MCLK ratio (512·fs with Y1, 256·fs with the Teensy).
2. Raw-GPIO renames (legacy names SWITCH/OUTPUTA/CS/… → S3_IOnn, T_nn) — cosmetic, later.
3. ~~Header footprints for the PCB, board outline holes~~ **done 2026-09-28 (section 11.3)**: PCB synced
   from the schematic and fully placed; next are antenna keep-out zones, GND pours and routing.
4. Symbol library sync (see residual ERC).

### 14.1 Stage 9 (2026-09-28, later): function-scoped headers, PSRAM, Ethernet

- J1-J4 (4 x 2x22) deleted with all 339 stubs/labels/NC flags; **J1-J12** placed next to their
  blocks and wired (section 13). Netlist diff against stage 8 = pin moves only; no net lost except
  `S3_IO3`, `S3_IO36`, `S3_IO37` (PSRAM pins, now NC) and the dead `S3_IO46` header pin.
- U13 -> **ESP32-S3-WROOM-1-N16R8** (C2913202); `BT_UART_RX` relabelled from IO35 to IO3;
  NC flags on IO35/IO36/IO37.
- **J12 `J_ETH` placed and labelled** (`ETH_R+ ETH_R- ETH_T+ ETH_T- ETH_LED`), but the six nets
  are single-node until the manual step below is done.
- ERC after stage 9: 0 dangling wires/labels, 0 undriven pins; only the 40 pre-existing
  cosmetic `unconnected_wire_endpoint` overshoots and the library-sync warnings.

**Manual eeschema steps that Konnect cannot do** (its library search is the KiCad install only,
so `project_sch` symbols cannot be placed or swapped):

1. U1: *Change Symbol* -> `project_sch:Teensy4.1` (full symbol, adds pins 60-65). Then label
   60 = `ETH_R+`, 61 = `ETH_LED`, 62 = `ETH_T-`, 63 = `ETH_T+`, 64 = `GND`, 65 = `ETH_R-`
   (names from the symbol). Konnect can do the six labels once the symbol is in the cache.
2. Footprint: copy pads 60-65 from `Teensy41.kicad_mod` into `Teensy41_mod3` (or a `_mod4`).
3. *Update Symbols from Library* for the ISO7762 / TLV757 / ASE cached symbols.

## 15. Sourcing for JLCPCB assembly (2026-09-28)

Every symbol now carries an `LCSC` field (and `LCSC_MPN` where the manufacturer part
number matters). Numbers were confirmed on lcsc.com / jlcpcb.com part pages, not guessed.

Substitutions made so the board can be assembled from stock:

| Ref | Was | Now | LCSC | Why |
|---|---|---|---|---|
| U17 | ISO7761DW | **ISO7762DW** | C2859648 | ISO7761 not stocked. 7762 = 4 fwd / 2 rev; DMX uses A, B fwd and F rev. Pin 6 (was INE→GND) is now NC; pin 11 becomes INE (unused input, left NC — tie to DMX_GND once the symbol is swapped in eeschema). |
| U20 | TLV76718DRVR | ~~TLV75718PDRVR~~ **SN74LVC2G125DCTR** | C206035 | Stage 10y: the 1V8 LDO left with the SRC4382; U20 is now the J_SAI2 DIN gate (project `SOP65P400X130-8N`). |
| U19 | SRC4382IPFBR (consigned) | **SN74LVC257APWR** | C205921 | Stage 10y: SAI2 source mux, TSSOP-16, stock. |
| U21, U23 | 74LVC157APW | **SN74LVC244APWR** (U21), **SN74LVC138APWR** (U23) | C7668, C485077 | Stage 10y: J_SAI2 header buffer and the mode interlock, TSSOP-20 / TSSOP-16, stock. |
| R86-R88 | (new) | 10 k 0402 | C25744 | SAI2_MODE0/1 pull-ups, SAI2_SEL pull-down. |
| R89-R101 | (new) | 33 R 0402 | C25105 | series resistors on every SAI2 / AUX_I2S driver. |
| Y1 | ASDMB-24.576MHZ | **ASE-24.576MHZ-LC-T** | C6159263 | ASDMB not stocked; ASE has the same 4-pin function (1 = standby, 2 GND, 3 OUT, 4 VDD) in 3.2×2.5 mm; footprint updated. |
| U13 | WROOM-1U (u.FL) | **ESP32-S3-WROOM-1-N16R8** | C2913202 | PCB antenna; 8 MB octal PSRAM for Spotify buffering (was N16R2 C2913205 for one commit). |
| L1 | NR4018T3R3M | **NRS4018T3R3MDGJ** | C92960 | same 4×4 mm 3.3 µH 2 A family, stocked. |
| U24 | (new) | AP63203WU-7 | C780769 | buck, JLC stock |
| D3, D4 | SK6812 3.2x2.8 reverse-mount (MINI-E) | **SK6812-EC20** 2.0x2.0 top-emitting | C2909058 | Decided 2026-09-28: the LEDs sit mid-board, so a top emitter is visible without board windows. Footprint `project_fp:LED_SK6812-EC20_2.0x2.0mm` built from datasheet SPC/SK68XX-EC20 rev 04 (pads 0.8x0.7 on 1.3x1.2); pad numbers follow the project symbol (1 DIN, 2 VDD, 3 DOUT, 4 GND), which differs from the datasheet numbering (1 VDD, 2 DOUT, 3 GND, 4 DIN). SK6805-EC15 (C2890035) is the drop-in smaller/dimmer alternative with `LED_SK6812_EC15_1.5x1.5mm`. |

Consigned (not at LCSC; supplied to the assembler or hand-placed): **U22 IDC777-1**,
**U1 Teensy 4.1**. Their `LCSC` field says `CONSIGN`. (The SRC4382 left the design in stage 10y.)

No LCSC number (no part or hand assembly): H1–H4 holes, T108–T111 panel tabs, PU_EN1
solder jumper, **J1-J12 pin headers** (stock 2.54 mm THT headers cut from 2x40 / 1x40 strips such
as C2333 / C50981; hand-soldered, so no LCSC field).

Passive numbers used: 0805 100 nF C49678, 10 µF C15850, 22 µF C45783, 4.7 µF C1779, 1 µF
C6119929, 0402 100 nF C1525; 0805 resistors 10k C17414, 100k C17407, 33k C17633, 300 Ω
C17617, 33 Ω C17634, 120 Ω C17437 (R71, DNP), 49.9 Ω C17720, 2.21k C17520, 0 Ω C17477.

## 16. Functional blocks on the sheet (for re-organising in eeschema)

Each block now has a title text at its top-left. Konnect can move symbols but not their
wires and labels as a group, so the actual tidy-up is a block-select + move in eeschema.
Coordinates are sheet mm (x, y), symbol centres:

| Block | x range | y range |
|---|---|---|
| TEENSY 4.1 + series terminations, SPI link pull-ups | 105 … 472 | 211 … 318 |
| SK6812 status LEDs + 5V level shifter | 457 … 794 | 430 … 518 |
| TDM bus buffers (I2S1 -> TDM1/TDM2 headers) | 492 … 639 | 681 … 883 |
| MIDI in/out/thru (opto + buffer) | 777 … 880 | 775 … 838 |
| 3.3V analog rail (LT3045) + 24.576 MHz MCLK oscillator | 596 … 1098 | 1002 … 1123 |
| 5V input mux (TPS2116): header 5V_IN / Teensy VUSB | 1063 … 1146 | 276 … 406 |
| 3.3V rail decoupling | 296 … 678 | 666 … 739 |
| ESP32-S3 module + I2C pull-ups + EN pull-up | -298 … -193 | 597 … 655 |
| 3.3V_DIG buck (AP63203) + 5V decoupling | -310 … -211 | 785 … 833 |
| Isolated DMX / RS-485 | -279 … -124 | 879 … 1010 |
| Bluetooth sink (IDC777) + SYS_CTRL pulldown | 1306 … 1360 | 389 … 615 |
| SRC4382 ASRC + 1.8V LDO | 1458 … 1584 | 453 … 704 |
| I2S source mux (BT / S3 / aux) | 1628 … 1669 | 574 … 660 |
| Edge headers J1-J4 | 1346 … 1651 | 900 … 900 |
| Mounting holes / panel tabs | 1032 … 1180 | 635 … 892 |

Suggested target arrangement (left→right, top→bottom): power (5 V mux, buck, LT3045, MCLK)
· Teensy + TDM buffers + MIDI + LEDs · S3 + DMX · BT + SRC + mux · headers. Keep every
block's stub-and-label style; nothing crosses blocks except by global label.

## 17. DNP / excluded-from-board audit (2026-09-28, after the user spotted X marks)

- **C10, C11** (0.1 µF on the old Teensy 3V3 rail) were `dnp` + `on_board no` → deleted.
- **H1–H4** mounting-hole symbols were `on_board no` → deleted; holes come from the outline
  footprint / PCB (§11).
- **R19, R53 (SPI-link pull-ups) and C4, C5 (EN / IO0 caps) were `on_board no`** — they would
  have been missing from the PCB. Konnect cannot clear that flag, so they were deleted and
  re-placed at the same coordinates (netlist unchanged), now on-board with LCSC numbers.
- Intentionally DNP and kept: **U1 Teensy** (consigned, hand-placed — hence the X on the
  schematic), T108–T111 panel tabs, PU_EN1 solder jumper.
- 35 stale text notes from the backplane era (USB/optical/Ethernet/mic/switch labels,
  8-layer stackup note, old titles) removed.

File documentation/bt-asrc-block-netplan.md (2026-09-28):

# Bluetooth sink + ASRC block — net plan

Status: parts placed, **wiring done** (2026-07-27). Every net below is in the schematic and verified
against a `kicad-cli sch export netlist` dump. Decoupling added as C140–C151. Remaining loose ends are
listed under [Open items](#open-items) — they are all *far-end* pin assignments, not block wiring.

## Architecture

```
IDC777-1 (BT) ──I2S──┐
   (U22)             │
                     ├─► 74LVC157A ──► SRC4382 Port A ──► SRC ──► Port B ──► Teensy TDM
ESP32-S3 stream ─────┘     (U21)          (U19)                    │
                                                          MCLK1 ───┘
optical S/PDIF ─────────────────────► DIR (RX1..RX4, future)
```

It is a **mux, not a mixer** — only one source is live at a time, so a single ASRC serves all of
them. The ASRC reconciles whichever source is selected onto the system clock, which is why neither
the Teensy nor the S3 needs to run a software resampler.

## Parts

| Ref | Part | Footprint | Notes |
|-----|---|---|---|
| **U22** | IDC777-1 | `project_fp:IDC777-1` | replaces the EOL IDC747 (was U14) — see [BT module migration](#bt-module-migration-idc747--idc777) |
| U19 | SRC4382IPFBR | `Package_QFP:TQFP-48_7x7mm_P0.5mm` | pin/register compatible with SRC4392 + DIX4192 |
| U20 | TLV76718DRVR | `Package_SON:WSON-6-1EP_2x2mm_P0.65mm_EP1x1.6mm_ThermalVias` | 1.8 V core rail |
| U21 | 74LVC157APW | `Package_SO:TSSOP-16_4.4x5mm_P0.65mm` | quad 2:1 mux, 3 channels used |
| Y1  | 24.576 MHz | (existing) | 512·fs @ 48 kHz — exact match to the SRC reference clock |

*(Historical, IDC747 only:* do not use the SnapEDA IDC747 footprint — legacy KiCad 5 format, all 51
pads omit `F.Mask` so mask would cover every pad. `project_fp:IDC747-1` was the correct one. The part
is now superseded; `project_fp:IDC777-1` is purpose-built and has proper `F.Mask` on all 60 pads.*)*

## BT module migration: IDC747 → IDC777

**The IDC747 is discontinued** — the Qualcomm die inside it went EOL. IOT747's stated replacement is
the **IDC777-1**: same software/AT interface, adds LE Audio (Unicast + Auracast), but **not
pin-to-pin compatible**. It is QCC518x-class silicon (Snapdragon Sound: aptX / aptX HD / aptX
Lossless, AAC), i.e. current top-tier for a BT sink — not a stopgap.

Library files built from datasheet `IDC777-DTS-V003` (pinout p.6-7, mechanical p.4, land pattern p.5):

- `lib_sch/IDC777-1.kicad_sym` — 60 pins, registered in `sym-lib-table` as `IDC777-1`
- `lib_fp/project_fp/IDC777-1.kicad_mod` — 22.2 × 11.8 mm, 60 castellated pads, 0.8 mm pitch,
  land pad 1.0 × 0.6 mm sitting 0.4 mm outside / 0.6 mm inside the body edge

Pad layout: pins **1–21** top edge (pin 1 is 5.1 mm from the −X end), **22–34** right edge,
**35–60** bottom edge running right-to-left. The −X end carries the integrated antenna and has no
pads. Both files verified with `kicad-cli sym/fp export svg`; pad grid checked for count, uniform
pitch and zero overlaps.

### Pin remap for the nets in this plan

| Net | IDC747 pin | **IDC777 pin** | Name on IDC777 |
|-----|---|---|---|
| GND | 1,2,3,4,11,22,27 | **1,12,18,19,21,22,27,34,35,41,51,56,58,59,60** | GND |
| 3.3V_DIG (VBAT) | 32 | **31** | VBAT |
| 3.3V_DIG (VBAT_SENSE) | 31 | **30** | VBAT_SENSE |
| 3.3V_DIG (VDD_PADS) | 33 | **32** | VDD_PADS |
| `BT_UART_TX` | 41 | **38** | UART_TX |
| `BT_UART_RX` | 42 | **39** | UART_RX |
| `BT_RST` | 44 | **36** | ~{RST} |
| `BT_BCK` | 47 | **53** | PCM_CLK |
| `BT_LRCK` | 46 | **52** | PCM_SYNC |
| `BT_SDATA` | 48 | **54** | PCM_OUT |
| no-connect | 29,30,34 | **28,29,33** | CHG_EXT, VCHG, VCHG_SENSE |

Every **net name is unchanged**, so U19, U20, U21 and all decoupling are unaffected — only U14's own
connections move.

**This also resolves open item 3.** On the IDC777 datasheet, PCM_CLK (53) and PCM_SYNC (52) are
**Bi-directional**, and the part explicitly supports *"Master (generate CLK and SYNC) or Slave
(receive CLK and SYNC)"*. The new symbol declares them bidirectional, so configuring the module as
I2S master makes `BT_BCK`/`BT_LRCK` properly driven. The old IDC747 symbol's input-only pins were a
symbol defect, not an architecture problem.

### Antenna orientation changed

The IDC747 note below says top-**right**. The IDC777 datasheet specifies the module be placed at the
top-**left** corner/edge, antenna facing the desired range direction, with an 8 × 4.44 mm ground
clearance area plus all metal removed on **every** layer out to the board edge. The footprint marks
the clearance area on `Dwgs.User` as a reminder — you must still add a real keepout zone/rule in the
PCB. Re-check this against the 100 × 30.48 mm outline before placing.

## Nets

```
U22 IDC777-1 (BT sink)   [was U14 IDC747-1 — EOL, replaced]
  1,12,18,19,21,22,27,34,35,41,51,56,58,59,60  GND  -> GND
  31 VBAT / 30 VBAT_SENSE / 32 VDD_PADS -> 3.3V_DIG  (fixed-voltage config)
  38 UART_TX        -> BT_UART_TX
  39 UART_RX        -> BT_UART_RX
  36 RST#           -> BT_RST
  53 PCM_CLK        -> BT_BCK      (bidirectional; module configured I2S master)
  52 PCM_SYNC       -> BT_LRCK     (bidirectional; module configured I2S master)
  54 PCM_OUT        -> BT_SDATA
  28 CHG_EXT, 29 VCHG, 33 VCHG_SENSE -> no-connect
  13 SYS_CTRL       -> UNRESOLVED, see open item 8
  Unused: 2-9,23-26 PIO, 10/11 USB, 14-17,20 AIO/LED, 37 UART_CTS, 40 UART_RTS,
          42-45 SPKR, 46 MIC_BIAS, 47-50 MIC, 55 PCM_IN, 57 EXT_RF

U21 74LVC157A (source mux)   S=0 selects BT, S=1 selects S3
  16 VCC -> 3.3V_DIG    8 GND -> GND    15 ~E -> GND    1 S -> BT_S3_SEL
  ch1 BCK :  2 <- BT_BCK     3 <- S3_I2S_BCK    4 -> SRC_A_BCK
  ch2 LRCK:  5 <- BT_LRCK    6 <- S3_I2S_LRCK   7 -> SRC_A_LRCK
  ch3 DATA: 14 <- BT_SDATA  13 <- S3_I2S_DOUT  12 -> SRC_A_SDATA
  ch4 unused: 11,10 -> GND   9 -> no-connect

U19 SRC4382 (ASRC + DIR)
  25 MCLK  -> MCLK1              (Y1, 24.576 MHz)
  17 VDD18 -> +1V8
  9 VCC / 33 VDD33 / 42 VIO -> 3.3V_DIG
  10 AGND, 16 DGND1, 30 DGND2, 43 DGND3, 44 BGND -> GND
  14 MUTE  -> GND
  18 CPM   -> 3.3V_DIG           (I2C control-port mode)
  19 A0    -> GND                (address)
  21 A1    -> GND                (address)
  20 CCLK/SCL  -> ESP32_IO22_SCL
  22 CDOUT/SDA -> ESP32_IO21_SDA
  24 RST#  -> SRC_RST
  Port A (input, slave to selected source):
    37 BCKA  <- SRC_A_BCK
    38 LRCKA <- SRC_A_LRCK
    39 SDINA <- SRC_A_SDATA
  Port B (output, slaved to existing TDM clocks):
    48 BCKB  <- BCLK1+TDM1
    47 LRCKB <- LRCK1+TDM1
    45 SDOUTB -> SRC_SDOUT       (new net -> Teensy TDM input)
  Unused for now: 1-8 RX1..RX4 (optical), 26-29 GPO, 31/32 TX, 34 AESOUT,
                  35 BLS, 36 SYNC, 40 SDOUTA, 46 SDINB, 41 NC, 12 RXCKO, 13 RXCKI,
                  11 ~LOCK, 15 ~RDY, 23 ~INT

U20 TLV76718 (1.8 V core rail)
  6 IN -> 3.3V_DIG   4 EN -> 3.3V_DIG   1 OUT -> +1V8   2 SNS -> +1V8
  3,5 GND / 7 PAD -> GND
```

## Decoupling

All placed as `project_fp:C_0805_2012Metric_Pad1.15x1.40mm_HandSolder` (project convention).

- U19: 100 nF at each of VCC(9), VDD18(17), VDD33(33), VIO(42) — **C140, C141, C142, C143**;
  10 µF bulk on +1V8 and 3.3V_DIG — **C144, C145**
- U20: 1 µF in **C147**, 10 µF **C148** + 100 nF **C149** out
- U21: 100 nF at VCC(16) — **C146**
- U22: 100 nF **C150** + 10 µF **C151** at VDD_PADS/VBAT

Schematic placement of these caps is functional, not tidy — they are grouped in free space near
their ICs and connected by label. Rearrange in eeschema if the sheet needs to read cleanly.

## Open items

Nets that exist in the schematic with **only one node** — the block end is wired, the far end is not
assigned. ERC reports each as `pin_not_driven`, which is expected until these are resolved:

| Net | Wired end | Needs |
|-----|---|---|
| `S3_I2S_BCK` | U21.3 | S3 source (see 1) |
| `S3_I2S_LRCK` | U21.6 | S3 source (see 1) |
| `S3_I2S_DOUT` | U21.13 | S3 source (see 1) |
| `BT_S3_SEL` | U21.1 | one S3 GPIO |
| `SRC_SDOUT` | U19.45 | Teensy TDM input (see 2) |
| `SRC_RST` | U19.24 | a GPIO or RC reset |
| `BT_UART_TX` | U14.41 | host UART RX |
| `BT_UART_RX` | U14.42 | host UART TX |
| `BT_RST` | U14.44 | a GPIO or RC reset |

1. **`S3_I2S_BCK` / `S3_I2S_LRCK` / `S3_I2S_DOUT`.** Note the S3 (U13) *already* has an I2S link to
   the Teensy's I2S2 port: `IO6→4_BCLK2`, `IO16→3_LRCLK2`, `IO7→5_IN2`, `IO4→2_OUT2`. The cheapest
   option is to tap those three existing nets into the mux rather than burning three more GPIOs —
   one driver, two loads, electrically fine. The alternative (a second S3 I2S peripheral) needs three
   free GPIOs, and U13's only unused pins are `IO3`, `IO45`, `IO46` (all strapping pins) and
   `IO35`/`IO36`/`IO37` (unusable on octal-PSRAM `-R8` module variants). Decide before assigning.
2. **`SRC_SDOUT`.** The Teensy's TDM1 data input (pin 8 / `IN1`) is **already occupied** by `8_IN1+`.
   Sharing it means relying on both sources tri-stating outside their TDM slots; otherwise this needs
   a different input or a rework of the TDM slot map.
3. ~~**BT I2S clock direction.**~~ **Resolved** by the IDC777 migration — the part supports I2S
   master mode and the new symbol declares PCM_CLK/PCM_SYNC bidirectional. The old symbol's
   input-only clock pins were the defect. Configure the module as I2S master.
7. ~~**Swap U14 to the IDC777-1.**~~ **Done.** U14 deleted (with all 30 wire segments, 10 labels and
   3 no-connect flags); U22 placed and wired. Verified by netlist: `BT_BCK`/`BT_LRCK`/`BT_SDATA` each
   carry exactly two nodes, U22 → U21, and no U14 node remains anywhere.
8. **`SYS_CTRL` (U22 pin 13) — soft power control, currently unconnected.** *Decision: drive it from
   the S3 so firmware can switch the BT receiver on and off.*

   From the datasheet's *Module Boot Modes* (p.12):
   - The module has a real **'Power Off' state that persists while VBAT stays powered** — a genuine
     low-power off, not just a reset.
   - Power Off → Active: **a rising edge on SYS_CTRL held high for 20 ms**.
   - Active → Power Off: **a UART command**, or a rising edge on SYS_CTRL.
   - Applying VBAT from *no* power boots straight to Active, so the module **defaults ON** at
     power-up regardless of this pin.

   Consequences for the design:
   - **It is edge-triggered, not level** — both directions are a rising edge, so pin state does not
     tell you module state. Use **UART for the off path** (BT_UART_TX/RX are already wired, giving a
     deterministic shutdown and known state) and reserve the SYS_CTRL pulse for **boot/wake**.
   - **Add a ~100 k pulldown** at SYS_CTRL. The pin has *no internal pull* and S3 GPIOs are high-Z
     during the S3's own boot/reset; a floating input near threshold can self-trigger and randomly
     toggle BT power.
   - **Drive it directly, no divider.** The datasheet example uses a resistor divider only because it
     sources from a Li-ion VBAT (up to 4.2 V). Here VBAT and the S3 IO are both 3.3 V — same domain.
   - New net: `BT_SYS_CTRL`.
9. ~~`VCHG_SENSE` should be tied to VCHG.~~ **Withdrawn — the no-connects are correct.** That advice
   came from the general pin-description table; the datasheet's *Fixed Voltage Supply Configuration*
   section (p.10) is config-specific and overrides it: with VBAT/VBAT_SENSE/VDD_PADS on one rail,
   *"VCHG and VCHG_SENSE and CHG_EXT are left unconnected"*. As wired. The datasheet does suggest
   bringing all three out to **test points** rather than leaving them bare — cheap bring-up insurance,
   worth adding at layout.

   Context: the charger pins are an **integrated Li-ion charger** aimed at portable products where the
   module is the whole system (cell + module + USB, no external charge IC): VBAT/VBAT_SENSE take the
   cell (3.0–4.6 V), VCHG/VCHG_SENSE take 5 V USB (4.75–6.5 V), CHG_EXT drives an external pass
   transistor above the internal 2–200 mA. This board has a regulated rail and no cell, so the whole
   feature is simply unused — the datasheet calls fixed-voltage the *typical* configuration.
4. **Antenna keepout.** The IDC747 must sit at a top-right corner/edge with all copper removed on
   *every* layer in the clearance zone out to the board edges, no metallic parts, and no routing
   through it. Settle this before placement on the 100 × 30.48 mm outline.
5. `SRC4382` VCC (pin 9) is the DIR comparator/PLL supply — consider an RC or ferrite filter off
   3.3V_DIG rather than a direct tie, if measured jitter matters. Currently a direct tie (C140).
6. Konnect's project config reports `layer_count: 2`; the board is 4-layer. Fix before DRC.

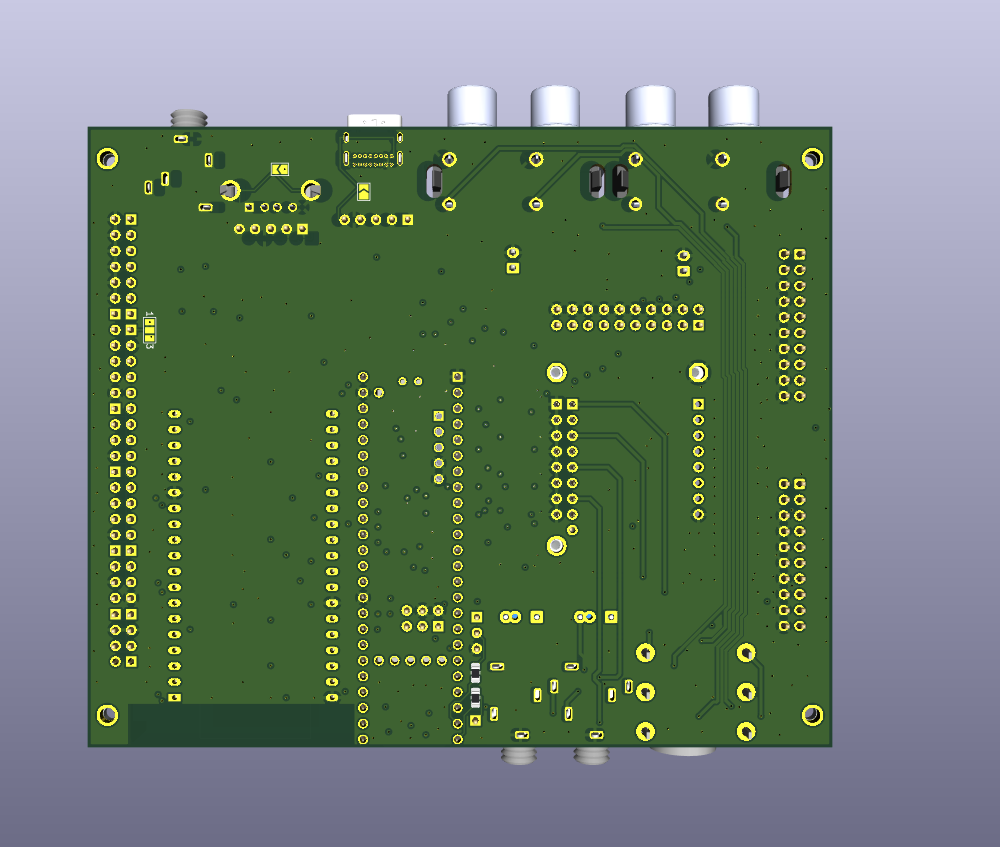
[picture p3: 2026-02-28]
documentation/t-dsp-desktop-pro-3d-bottom.png

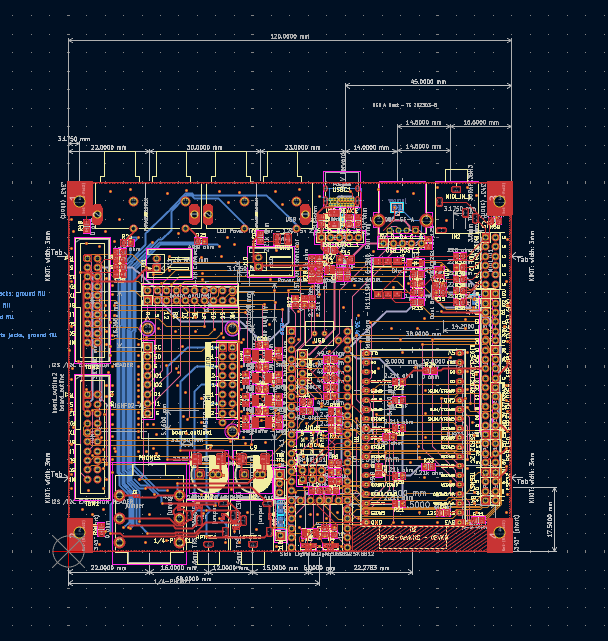
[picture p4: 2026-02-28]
documentation/t-dsp-desktop-pro-pcb-layout.png

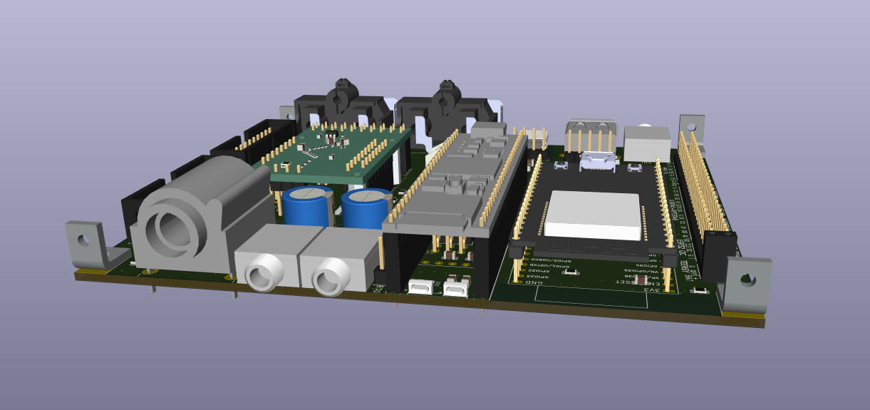
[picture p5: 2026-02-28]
documentation/t-dsp-desktop-pro-3d-angle_front.png

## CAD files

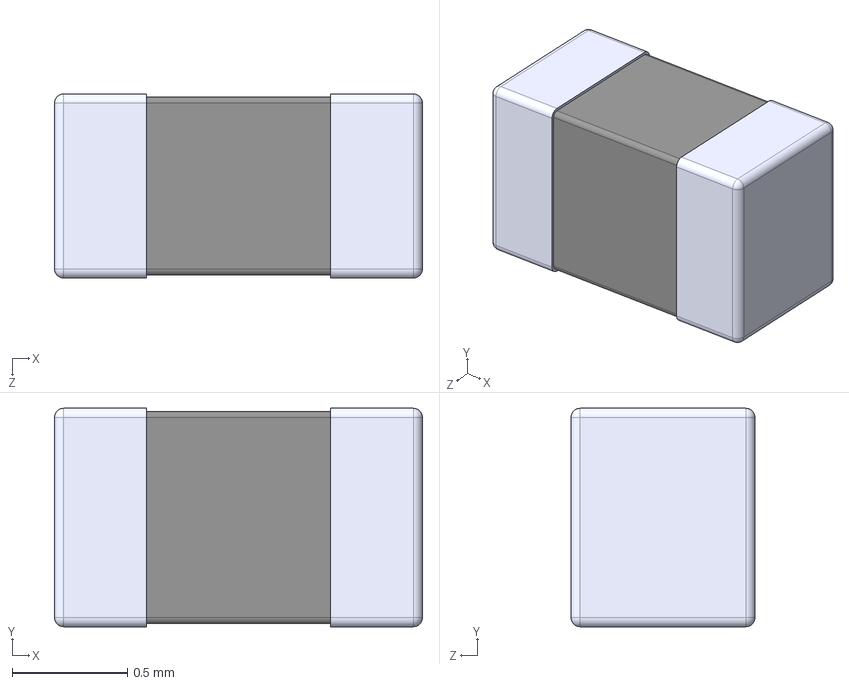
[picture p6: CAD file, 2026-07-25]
lib_sch/BLM18BA121SN1D.step
1.60 x 0.95 x 0.8 mm

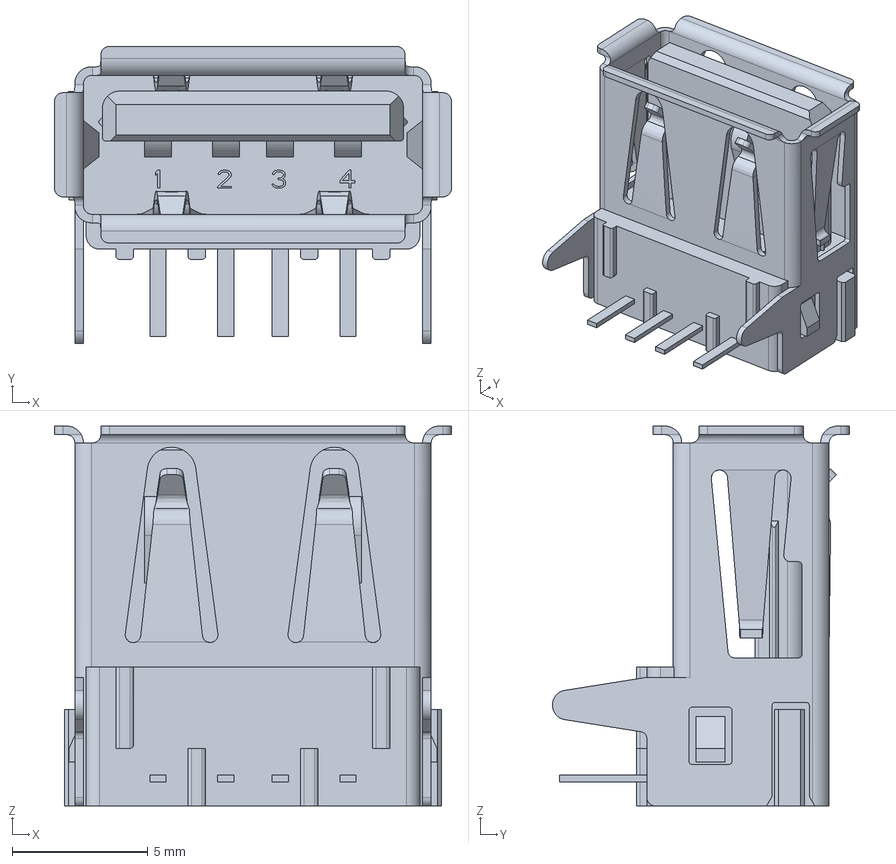
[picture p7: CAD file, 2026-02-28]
3d_models/c-6364372-2-o-3d.stp
14.6 x 10.9 x 14.0 mm

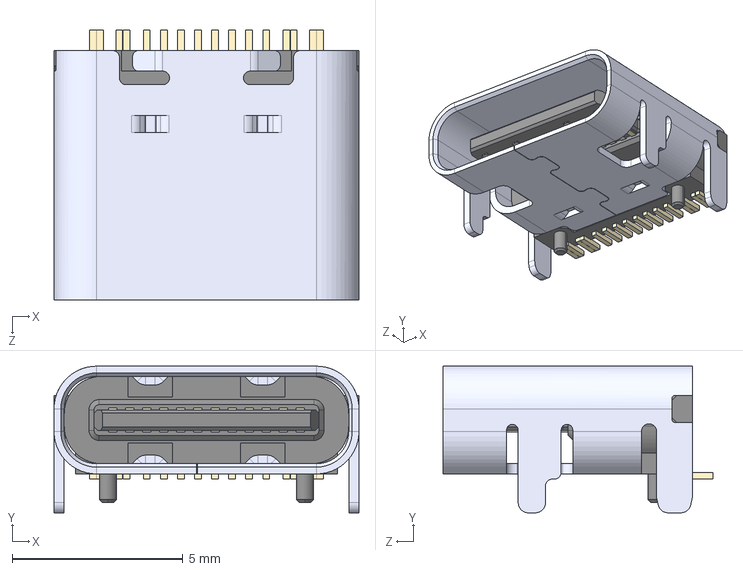
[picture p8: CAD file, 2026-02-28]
lib_fp/project_fp/TYPE-C-31-M-12.step
8.94 x 4.30 x 7.90 mm

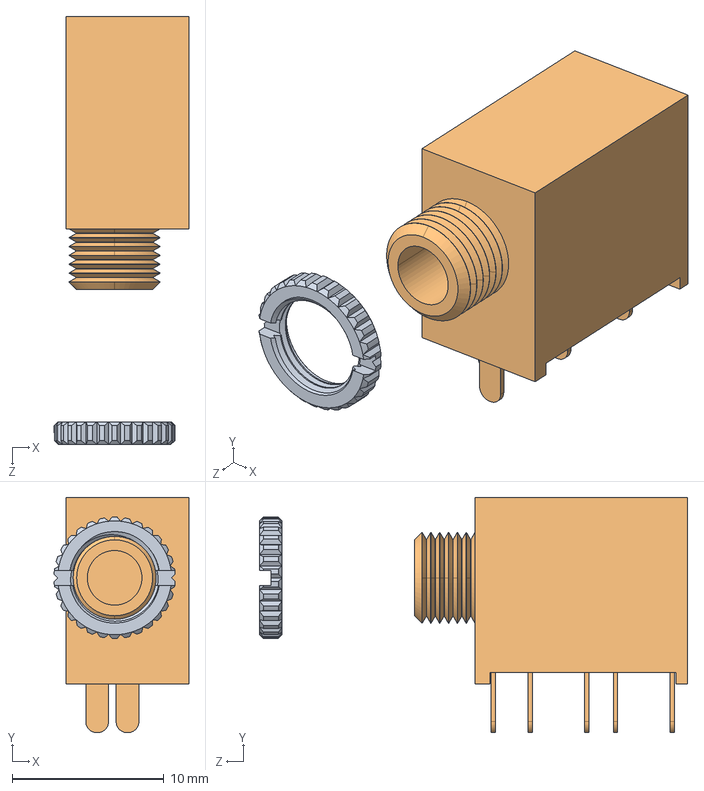
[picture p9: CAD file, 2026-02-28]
lib_sch/35RAPC4BV4.step
8.89 x 15.5 x 28.2 mm

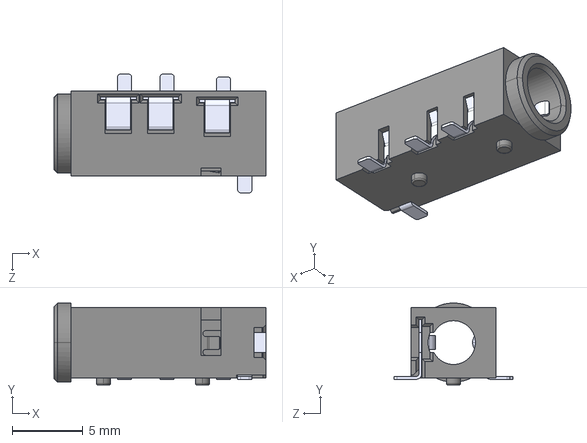
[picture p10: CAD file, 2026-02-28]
3d_models/SJ2-3574A-SMT-TR.step
15.0 x 5.80 x 8.40 mm

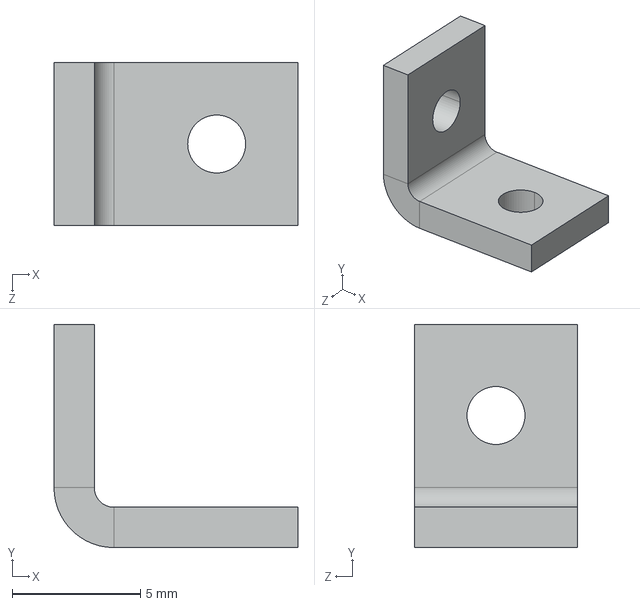
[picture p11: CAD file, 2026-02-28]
3d_models/Bracket 4-40 621.STEP
9.53 x 8.71 x 6.35 mm

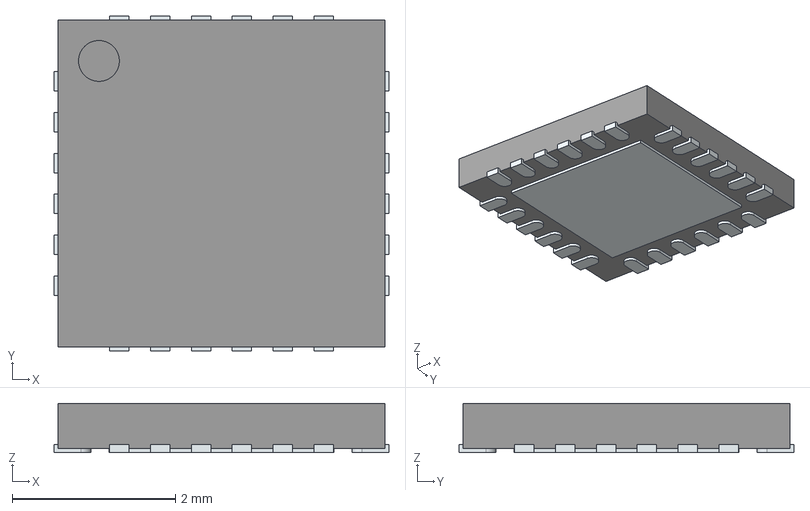
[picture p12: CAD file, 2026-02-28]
lib_fp/project_fp/CYPD3177-24LQXQ.stp
4.10 x 4.10 x 0.6 mm
ThermalPin
PinsArrayLR
PinsArrayTB

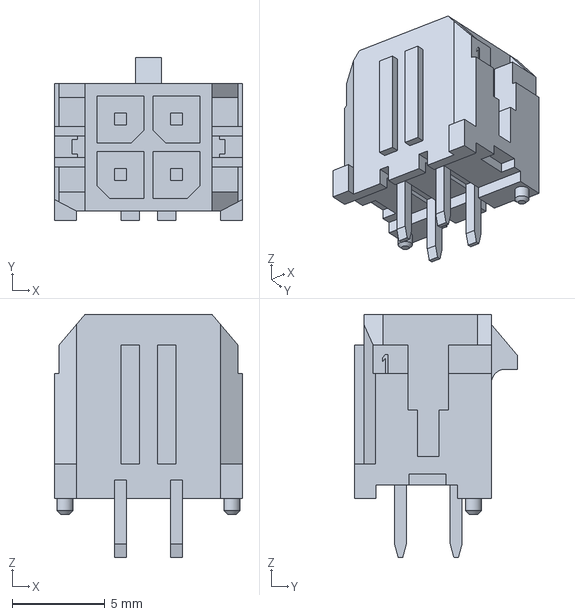
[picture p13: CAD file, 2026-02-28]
3d_models/MicroFit3-43045-0428.stp
10.1 x 8.77 x 13.1 mm

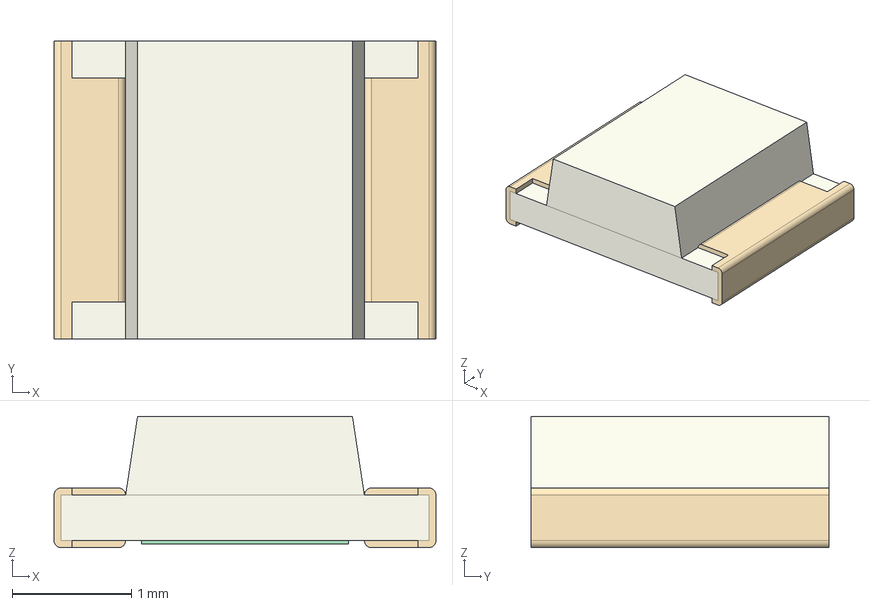
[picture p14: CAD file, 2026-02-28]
3d_models/LED_1210_3225Metric.step
3.20 x 2.50 x 1.10 mm

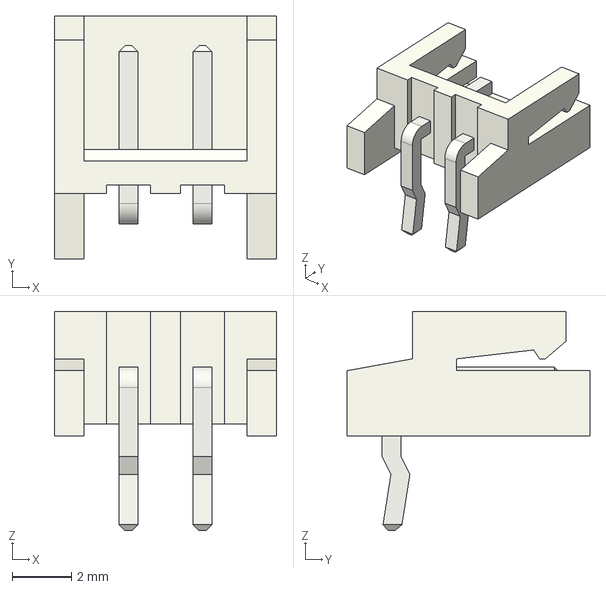
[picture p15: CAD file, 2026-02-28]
3d_models/JST_EH_S2B-EH_1x02_P2.50mm_Horizontal.step
7.50 x 8.20 x 7.40 mm

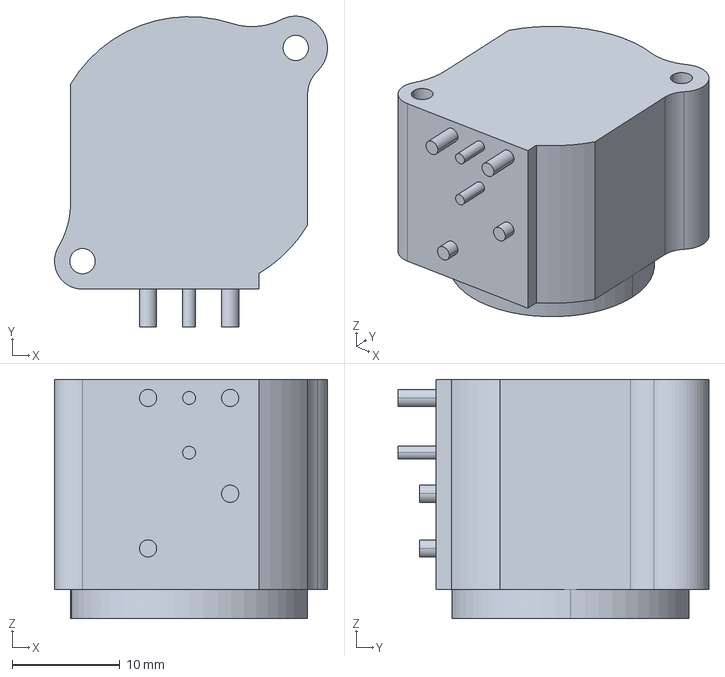
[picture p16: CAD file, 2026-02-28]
3d_models/3-D NC3MAH.stp
25.3 x 28.8 x 22.2 mm

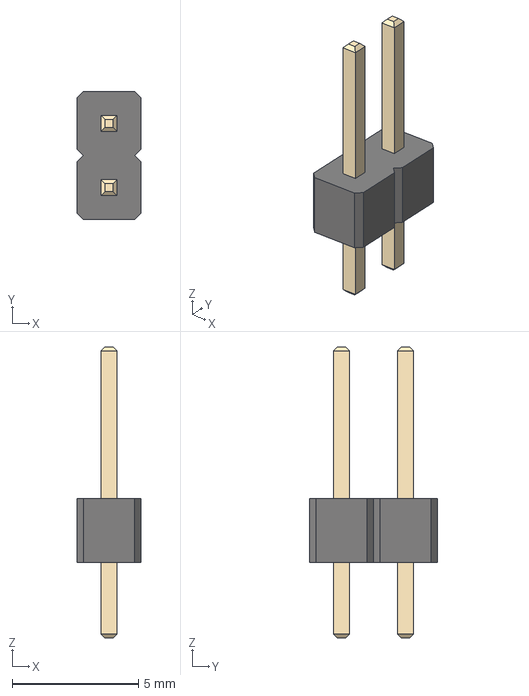
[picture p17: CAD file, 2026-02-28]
3d_models/PinHeader_1x02_P2.54mm_Vertical.step
2.54 x 5.08 x 11.5 mm

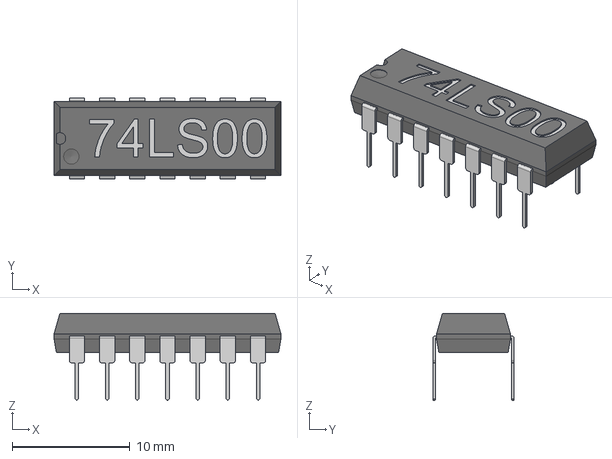
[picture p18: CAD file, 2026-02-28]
3d_models/74LS00.step
19.3 x 6.90 x 7.40 mm

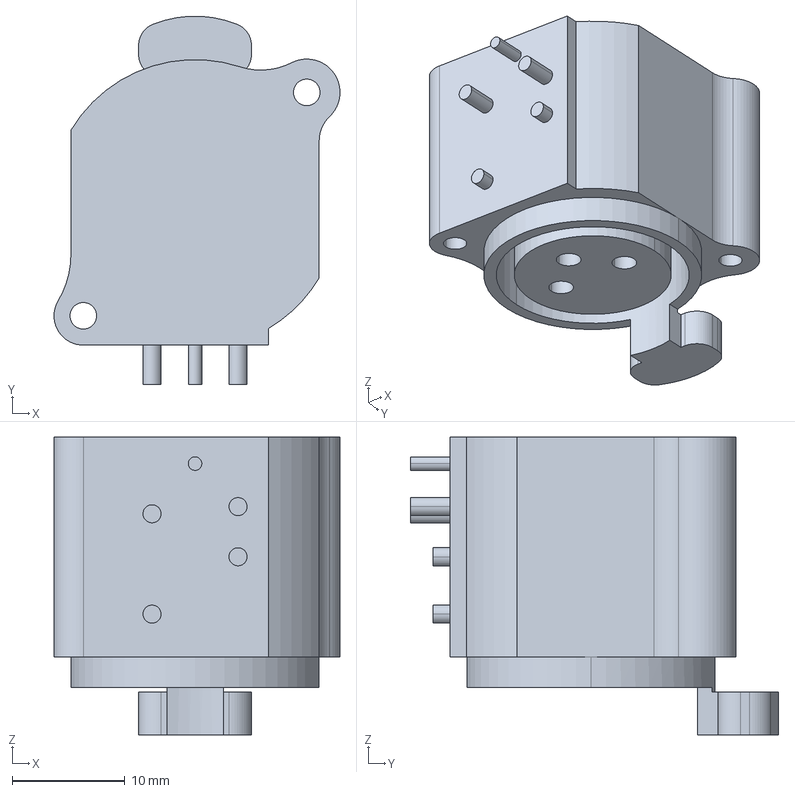
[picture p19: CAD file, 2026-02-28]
3d_models/d-nc3fah.stp
25.3 x 32.6 x 26.4 mm

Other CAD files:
3d_models/COMBO_XLR_NCJ6FI-H-0.stp
3d_models/PRT-14417.step
3d_models/COMBO-NCJ6FA-H.step
3d_models/1808--3DModel-STEP-630548.STEP
3d_models/2120--3DModel-STEP-630548.STEP
3d_models/3-D NCJ6FAH.stp
3d_models/3-D NCJ6FI-H-0.stp
3d_models/3-d-nmj6hcd3.stp
3d_models/3.5MM_STEREO_35RAPC4BHN2.STEP
3d_models/35RAPC3BH3.STEP
3d_models/35RAPC7JS.STEP
3d_models/35RAPC7JS_SIMPLIFIED.step
3d_models/3_2SPI-TFT-Modul_ILI9341.STEP
3d_models/4691.step
3d_models/73725-0110BLF.step
3d_models/73725-11A0BLF.stp
3d_models/74HCT2G125DC,125.stp
3d_models/CP_Radial_D10.0mm_P5.00mm.step
3d_models/C_1206_3216Metric.step
3d_models/DC_BARREL_PJ-202AH.step
3d_models/DIN-5.STEP
3d_models/DMG2307L-7.stp
3d_models/D_1210_3225Metric.step
3d_models/EC11E15204A3.stp
3d_models/EN11-HSM1AF15.STEP
3d_models/FCR6842032R ORJ3.stp
3d_models/FCR6842032T OTJ3.stp
3d_models/H11L1SM.step
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

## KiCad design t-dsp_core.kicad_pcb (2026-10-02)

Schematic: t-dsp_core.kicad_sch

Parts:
C1, C29, C30: 1 uF; C_0603_1608Metric; LCSC C15849
C2, C3, C4, C5, C16, C17, C21, C22, C32, C35, C40: 0.1 uF; C_0603_1608Metric; LCSC C14663
C12, C23, C31, C33, C34, C44: 10 uF; C_0603_1608Metric; LCSC C19702
C15: 100 uF; C_1206_3216Metric_Pad1.33x1.80mm_HandSolder; LCSC C15008
C18, C19, C131, C133, C140, C141, C142, C143, C150, C153: 100nF; C_0603_1608Metric; LCSC C14663
C27, C28: 47uF; C_0805_2012Metric_Pad1.15x1.40mm_HandSolder; LCSC C16780
C41, C42: 10 uF; C_0603_1608Metric; LCSC_MPN CL10A106KP8NNNC
C43: 4.7uF; C_0603_1608Metric; LCSC_MPN CL10A475KO8NNNC
C45: 1 uF; C_0402_1005Metric_Pad0.74x0.62mm_HandSolder; LCSC C29266
C46: 100nF; C_0402_1005Metric_Pad0.74x0.62mm_HandSolder; LCSC C1525
C129: 0.1uF; C_0402_1005Metric_Pad0.74x0.62mm_HandSolder; LCSC C106994
C130, C151: 10uF; C_0603_1608Metric; LCSC C19702
C132, C154: 22uF; C_0805_2012Metric_Pad1.15x1.40mm_HandSolder; LCSC C45783
D2: Diode - 1N4148; D_SOD-123; LCSC C81598
D3: SK6812-EC20; LED_SK6812-EC20_2.0x2.0mm; LCSC C5378721
D4: SK6812-EC20; LED_SK6812-EC20_2.0x2.0mm; LCSC TYPE SMD
D7: SMAJ5.0A; D_SMA; LCSC C78401
FB1: 600Ω@100MHz; BLM15AG601SN1D; LCSC C76884
FL1: BLM18BA121SN1D; LCSC C113012
H1, H2, H3, H4: M3 NPTH 3.2mm; MountingHole_3.2mm_M3
IC1: Logic Level Shifter - 74HCT2G125DC,125; SOP50P310X100-8N; LCSC C547558
J1: J_PWR; PinHeader_2x05_P2.54mm_Vertical
J2: J_TDM; PinHeader_2x14_P2.54mm_Vertical
J3: J_T; PinHeader_2x12_P2.54mm_Vertical
J4: J_USB; PinHeader_2x05_P2.54mm_Vertical
J5: J_MIDI; PinHeader_2x04_P2.54mm_Vertical
J7: J_SAI2; PinHeader_2x06_P2.54mm_Vertical
J8: J_S3; PinHeader_2x17_P2.54mm_Vertical
J11: J_LED; PinHeader_1x05_P2.54mm_Vertical
J12: J_ETH; PinHeader_2x04_P2.54mm_Vertical
J13: u.FL DNP (IDC767 ext-antenna build only); U.FL_Hirose_U.FL-R-SMT-1_Vertical
JP1: SJ bridged; SolderJumper-2_P1.3mm_Bridged_Pad1.0x1.5mm
L1: 3.3uH; L_Taiyo-Yuden_NR-40xx; LCSC C92960
PU_EN1: JUMPER; SolderJumper-2_Open_Pad0.5x1.0mm_PU; not fitted
Q1: AO3401A; SOT-23; LCSC C15127
R3, R4, R5, R6, R7, R9, R40, R41, R42, R43, R44, R45, R46, R47, R52, R55, R56, R75, R76, R81, R89, R90, R91, R92, R93, R94, R95, R96, R97, R98, R99, R100, R101: 33 ohm; R_0603_1608Metric; LCSC C23140
R8, R32, R34, R36, R37, R38, R39: 220 ohm; R_0603_1608Metric; LCSC C22962
R11, R19, R53, R54, R73, R74, R86, R87, R88: 10k; R_0603_1608Metric; LCSC C25804
R12, R15, R31, R35, R59, R60, R77, R80, R83, R84: 0 ohm; R_0603_1608Metric; LCSC C21189
R13, R14, R16, R17, R67, R68: 2.2k ohm; R_0603_1608Metric; LCSC C4190
R33: 1.5k ohm; R_0603_1608Metric; LCSC C22843
R57: 33.0 k; R_0603_1608Metric; LCSC_MPN 0603WAF3302T5E
R58: 300 ohm; R_0603_1608Metric; LCSC_MPN 0603WAF3000T5E
R61: 33 ohm; R_0603_1608Metric; LCSC_MPN 0603WAF330JT5E
R66, R72: 100k; R_0603_1608Metric; LCSC C25803
R78, R79, R82, R85: 0 ohm DNP; R_0603_1608Metric; LCSC C21189
T108, T109, T110, T111: Tab; not fitted
U1: Teensy 4.1 - DEVKIT; Teensy41; LCSC CONSIGN; not fitted
U4: Optoisolators - H11L1SM - 6-SMD, Gull Wing; IC_H11L1SM; LCSC C899473
U5: SN74LVC541APWR; TSSOP-20_4.4x6.5mm_P0.65mm; LCSC C113281
U6, U7, U20: SN74LVC2G125DCTR; SOP65P400X130-8N; LCSC C206035
U9: Dual Buffer - 74HCT2G17GW,125; SOT-363_SC-70-6; LCSC C547568
U11: Dual Buffer - SN74LVC2G125DCTR; SOP65P400X130-8N; LCSC C206035
U13: ESP32-S3-WROOM-1-N16R8; ESP32-S3-WROOM-1; LCSC C2913202
U15: LT3045EMSE#TRPBF; MSOP-12-1EP_3x4.039mm_P0.65mm_EP1.651x2.845mm; LCSC C666577
U19: SN74LVC257APWR; TSSOP-16_4.4x5mm_P0.65mm; LCSC C205921
U21: SN74LVC244APWR; TSSOP-20_4.4x6.5mm_P0.65mm; LCSC C7668
U22: IDC777-1; LCSC CONSIGN
U23: SN74LVC138APWR; TSSOP-16_4.4x5mm_P0.65mm; LCSC C485077
U24: AP63203WU; TSOT-23-6; LCSC C780769
Y1: 24.576MHz; Oscillator_SMD_Abracon_ASE-4Pin_3.2x2.5mm; LCSC C6159263

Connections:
3.3V: C17.1, C18.1, C19.1, C27.1, C30.1, C40.1, C42.1, C129.1, FB1.1, J1.7, PU_EN1.1, R11.1, R12.2, R15.2, R19.1, R31.2, R74.1, R78.2, R80.2, R83.2, R85.2, U5.20 (VCC), U6.8 (VCC), U7.7 (~2OE), U7.8 (VCC), U11.8 (VCC), U15.10 (OUTS), U15.11 (OUT), U15.12 (OUT)
3.3V_DIG: C132.1, C133.1, C140.1, C141.1, C142.1, C143.1, C150.1, C151.1, C154.1, J1.8, J7.11, L1.2, R73.1, R86.1, R87.1, U13.2 (3V3), U19.16 (VCC), U20.8 (VCC), U21.20 (VCC), U22.30 (VBAT_SENSE), U22.31 (VBAT), U22.32 (VDD_PADS), U23.6 (E3), U23.16 (VCC), U24.1 (FB)
5V: C15.1, C22.1, C23.1, C28.1, C29.1, C34.1, C35.1, C130.1, C131.1, D3.2 (VDD), D4.2 (VDD), FL1.1, IC1.8 (VCC), J1.5, J1.6, J7.12, J8.12, J11.5, Q1.2 (S), R35.2, R37.2, R39.2, R66.1, U1.48 (VIN), U24.3 (IN)
5V_IN: C12.1, D7.1 (K), J1.1, J1.2, Q1.3 (D)
6_OUT1D: R4.2, U5.9 (A7)
6_OUT1D+: J2.16, R47.2
7_OUT1A: R3.2, U5.5 (A3)
7_OUT1A+: J2.15, R46.2
8_IN1: J2.17, U11.2 (1A)
8_IN1+: R55.2, U1.10 (8_TX2_IN1)
9_OUT1C_INPUT: J2.18, R81.2, U11.5 (2A)
9_OUT1C_INPUT+: R56.2, U1.11 (9_OUT1C), U7.2 (1A)
32_OUT1B: J2.27, R75.2, U6.5 (2A)
/OUT1B_MCU: R5.2, R76.2, U1.24 (32_OUT1B), U6.2 (1A)
/OUT1B_OE_IN: R79.1, R80.1, U6.7 (~2OE)
/OUT1B_OE_OUT: R77.1, R78.1, U6.1 (~1OE)
/OUT1C_OE_IN: R84.1, R85.1, U11.7 (~2OE)
/OUT1C_OE_OUT: R82.1, R83.1, U7.1 (~1OE)
/S3_IO43_TXD0: J8.30, U1.20 (28_RX7), U13.37 (TXD0)
/S3_IO44_RXD0: J8.29, U1.21 (29_TX7), U13.36 (RXD0)
/TDM1_BCLK_B: R44.1, U5.16 (Y2)
/TDM1_DOUT_B: R46.1, U5.15 (Y3)
/TDM1_LRCK_B: R42.1, U5.18 (Y0)
/TDM1_MCLK_B: R41.1, U5.17 (Y1)
/TDM2_BCLK_B: R45.1, U5.12 (Y6)
/TDM2_DOUT_B: R47.1, U5.11 (Y7)
/TDM2_LRCK_B: R43.1, U5.14 (Y4)
/TDM2_MCLK_B: R40.1, U5.13 (Y5)
/TDM2_OE: JP1.1, R74.2, U5.19 (G2)
AUX_I2S_BCK: J7.5, R95.2, U21.2 (I0a)
AUX_I2S_DIN: J7.9, U20.2 (1A), U20.5 (2A)
AUX_I2S_DOUT: J7.10, R94.2, R98.2
AUX_I2S_LRCK: J7.7, R96.2, U21.4 (I1a)
AUX_I2S_MCLK: J7.3, R97.2, R101.2
BCLK1: R6.2, U5.4 (A2), U5.8 (A6)
BCLK1+TDM1: J2.7, R44.2
BCLK1+TDM2: J2.8, R45.2
BT_BCK: U19.2 (I0a), U22.53 (PCM_CLK)
BT_EXT_RF: J13.1 (In), U22.57 (EXT_RF)
BT_LRCK: U19.5 (I0b), U22.52 (PCM_SYNC)
BT_RST: U13.33 (IO40), U22.36 (~RST)
BT_SDATA: U19.14 (I0c), U22.54 (PCM_OUT)
BT_SYS_CTRL: R72.1, U13.34 (IO41), U22.13 (SYS_CTRL)
BT_UART_RX: U13.15 (IO3), U22.39 (UART_RX)
BT_UART_TX: U13.9 (IO16), U22.38 (UART_TX)
EN_3V3_DIG: R66.2, U24.2 (EN)
ESP32_LED+: D4.1 (DIN), IC1.6 (1Y)
ESP32_LED_OUT: D4.3 (DOUT), J11.4
ETH_LED: J12.7
ETH_R+: J12.1
ETH_R-: J12.2
ETH_T+: J12.5
ETH_T-: J12.6
GND: C1.2, C2.2, C3.2, C4.2, C5.2, C12.2, C15.2, C16.1, C17.2, C18.2, C19.2, C21.1, C22.2, C23.2, C27.2, C28.2, C29.2, C30.2, C31.2, C32.2, C33.2, C34.2, C35.2, C40.2, C41.2, C42.2, C43.2, C44.2, C45.2, C46.2, C129.2, C130.2, C131.2, C132.2, C133.2, C140.2, C141.2, C142.2, C143.2, C150.2, C151.2, C154.2, D3.4 (GND), D4.4 (GND), D7.2 (A), IC1.1 (~1OE), IC1.4 (GND), IC1.7 (~2OE), J1.3, J1.4, J1.10, J2.1, J2.2, J2.5, J2.6, J2.9, J2.10, J2.13, J2.14, J2.19, J2.20, J2.25, J2.26, J2.28, J3.1, J3.2, J3.5, J3.6, J3.15, J3.16, J3.21, J3.22, J3.23, J3.24, J4.1, J4.2, J4.7, J4.8, J4.10, J5.7, J5.8, J7.1, J7.2, J7.4, J7.6, J7.8, J8.1, J8.2, J8.8, J8.11, J8.16, J8.21, J8.22, J8.27, J8.28, J8.33, J8.34, J11.1, J11.3, J12.3, J12.4, J12.8, J13.2 (Ext), JP1.2, Q1.1 (G), R33.1, R53.2, R54.1, R57.1, R58.1, R60.2, R72.2, R77.2, R79.2, R82.2, R84.2, R88.2, U1.1 (GND), U1.34 (GND), U1.47 (GND), U1.52 (GND), U1.58 (GND), U1.59 (GND), U5.1 (G1), U5.10 (GND), U6.4 (GND), U7.4 (GND), U7.5 (2A), U9.2 (GND), U11.1 (~1OE), U11.4 (GND), U13.1 (GND), U13.40 (GND), U13.41 (GND), U15.9 (GND), U15.13 (GND), U19.8 (GND), U19.10 (I1d), U19.11 (I0d), U20.4 (GND), U21.10 (GND), U22.1 (GND), U22.12 (GND), U22.18 (GND), U22.19 (GND), U22.21 (GND), U22.22 (GND), U22.27 (GND), U22.34 (GND), U22.35 (GND), U22.41 (GND), U22.51 (GND), U22.56 (GND), U22.58 (GND), U22.59 (GND), U22.60 (GND), U23.3 (A2), U23.4 (E1), U23.5 (E2), U23.8 (GND), U24.4 (GND), Y1.2 (GND)
HOST_5V: C1.1, C33.1, J4.9, U1.55 (5V)
HOST_D1+: J4.5, U1.57 (D+)
HOST_D1-: J4.3, U1.56 (D-)
LRCK1: R9.2, U5.2 (A0), U5.6 (A4)
LRCK1+TDM1: J2.11, R42.2
LRCK1+TDM2: J2.12, R43.2
MCLK1: R7.2, R61.2, U5.3 (A1), U5.7 (A5)
MCLK1+TDM1: J2.3, R41.2
MCLK1+TDM2: J2.4, R40.2
MIDI_IN_4: J5.1, R32.1
MIDI_IN_5: D2.2 (A), J5.2, U4.2
MIDI_OUT_4: J5.3, R39.1
MIDI_OUT_5: J5.4, R38.1
MIDI_RX: R34.1, U1.2 (0_RX1_CRX2_CS1), U4.4, U9.3
MIDI_THRU_4: J5.5, R37.1
MIDI_THRU_5: J5.6, R36.1
MIDI_TX_T: U1.3 (1_TX1_CTX2_MISO1), U9.1
unnamed: C16.2, R31.1, R34.2, U4.6
unnamed: C31.1, C32.1
unnamed: D2.1 (K), R32.2, U4.1
unnamed: PU_EN1.2, R67.1, R68.1
unnamed: R12.1, R13.2, R14.2
unnamed: R15.1, R16.2, R17.2
unnamed: R33.2, U4.5
unnamed: R36.2, U9.4
unnamed: R38.2, U9.6
unnamed: R4.1, U1.8 (6_OUT1D)
unnamed: R3.1, U1.9 (7_RX2_OUT1A)
unnamed: R9.1, U1.42 (20_A6_TX5_LRCLK1)
unnamed: R6.1, U1.43 (21_A7_RX5_BCLK1)
unnamed: R7.1, U1.45 (23_A9_CRX1_MCLK1)
unnamed: R52.1, U1.23 (31_CTX3)
unnamed: R8.2, U1.33 (41_A17)
unnamed: R75.1, U6.6 (1Y)
unnamed: R76.1, U6.3 (2Y)
unnamed: R81.1, U7.6 (1Y)
unnamed: C21.2, R35.1, U9.5 (VCC)
unnamed: R55.1, U11.6 (1Y)
unnamed: R56.1, U11.3 (2Y)
unnamed: C41.1, FL1.2, U15.1 (IN), U15.2 (IN), U15.3 (IN), U15.4 (EN/UV)
unnamed: R58.2, U15.6 (ILIM)
unnamed: C43.1, R57.2, U15.8 (SET)
unnamed: R89.1, U19.4 (Za)
unnamed: R90.1, U19.7 (Zb)
unnamed: R91.1, U19.12 (Zc)
unnamed: R99.1, U20.6 (1Y)
unnamed: R100.1, U20.3 (2Y)
unnamed: R92.1, U21.18 (O0a)
unnamed: R95.1, U21.9 (O0b)
unnamed: R93.1, U21.16 (O1a)
unnamed: R96.1, U21.7 (O1b)
unnamed: R101.1, U21.14 (O2a)
unnamed: R97.1, U21.5 (O2b)
unnamed: R94.1, U21.12 (O3a)
unnamed: R98.1, U21.3 (O3b)
unnamed: C153.1, U24.6 (BST)
unnamed: C153.2, L1.1, U24.5 (SW)
unnamed: R61.1, Y1.3 (Out)
unnamed: R59.2, R60.1, Y1.1 (Standby)
unnamed: C44.1, C45.1, C46.1, FB1.2, R59.1, Y1.4 (VDD)
S3_EN: C4.1, J8.3, R73.2, U1.29 (37_CS), U13.3 (EN)
S3_I2S_BCK: U13.6 (IO6), U19.3 (I1a)
S3_I2S_DOUT: U13.7 (IO7), U19.13 (I1c)
S3_I2S_LRCK: U13.4 (IO4), U19.6 (I1b)
S3_IO0_BOOT: C5.1, J8.23, U1.28 (36_CS), U13.27 (IO0)
S3_IO1: J8.32, U13.39 (IO1)
S3_IO2: J8.31, U13.38 (IO2)
S3_IO5: J8.4, U13.5 (IO5)
S3_IO8: J8.7, U13.12 (IO8)
S3_IO9: J8.13, U13.17 (IO9)
S3_IO10: J8.14, U13.18 (IO10)
S3_IO11: J8.15, U13.19 (IO11)
S3_IO12_SPI_MISO: R53.1, U1.14 (12_MISO_MQSL), U13.20 (IO12)
S3_IO13_SPI_MOSI: U1.13 (11_MOSI_CTX1), U13.21 (IO13)
S3_IO14_SPI_SCK: U1.35 (13_SCK_LED), U13.22 (IO14)
S3_IO15: J8.5, U13.8 (IO15)
S3_IO17_SPI_CS: R19.2, U1.12 (10_CS_MQSR), U13.10 (IO17)
S3_IO18: J8.6, U13.11 (IO18)
S3_IO21_SDA: J8.17, R67.2, U13.23 (IO21)
S3_IO38: J8.24, U13.31 (IO38)
S3_IO39: J8.25, U13.32 (IO39)
S3_IO42: J8.26, U13.35 (IO42)
S3_IO45: J8.20, U13.26 (IO45)
S3_IO46_LED: IC1.2 (1A), U13.16 (IO46)
S3_IO47_SCL: J8.18, R68.2, U13.24 (IO47)
S3_IO48: J8.19, U13.25 (IO48)
S3_USB_DN: J8.9, U13.13 (USB_D-)
S3_USB_DP: J8.10, U13.14 (USB_D+)
SAI2_BCLK: R89.2, R92.2, U1.6 (4_BCLK2), U21.11 (I0b)
SAI2_IN: R91.2, R99.2, R100.2, U1.7 (5_IN2)
SAI2_LRCLK: R90.2, R93.2, U1.5 (3_LRCLK2), U21.13 (I1b)
SAI2_MCLK: U1.25 (33_MCLK2), U21.6 (I2a), U21.15 (I2b)
SAI2_MODE0: R86.2, U1.18 (26_A12_MOSI1), U23.1 (A0)
SAI2_MODE1: R87.2, U1.19 (27_A13_SCK1), U23.2 (A1)
SAI2_OUT: U1.4 (2_OUT2), U21.8 (I3a), U21.17 (I3b)
SAI2_SEL: R88.1, U1.44 (22_A8_CTX1), U19.1 (S)
SAI2_nOE_HDR: U20.1 (~1OE), U21.1 (OEa), U23.14 (O1)
SAI2_nOE_INT: U19.15 (OE), U23.15 (O0)
SAI2_nOE_OUT: U20.7 (~2OE), U21.19 (OEb), U23.13 (O2)
T14_SPDIF_OUT: J3.3, U1.36 (14_A0_TX3_SPDIF_OUT)
T15_SPDIF_IN: J3.4, U1.37 (15_A1_RX3_SPDIF_IN)
T16_SCL1: J2.24, R17.1, U1.38 (16_A2_RX4_SCL1)
T17_SDA1: J2.22, R16.1, U1.39 (17_A3_TX4_SDA1)
T18_SDA0: J2.21, R14.1, U1.40 (18_A4_SDA)
T19_SCL0: J2.23, R13.1, U1.41 (19_A5_SCL)
T24: J3.13, U1.16 (24_A10_TX6_SCL2)
T25: J3.14, U1.17 (25_A11_RX6_SDA2)
T30_CRX3: J3.7, U1.22 (30_CRX3)
T31_CTX3: J3.8, R52.2
T32_OUT1B: J3.20, R5.1
T34_RX8: J3.10, R54.2, U1.26 (34_RX8)
T35_TX8: J3.9, R11.2, U1.27 (35_TX8)
T38: J3.17, U1.30 (38_CS1_IN1)
T39: J3.18, U1.31 (39_MISO1_OUT1A)
T40: J3.19, U1.32 (40_A16)
TEENSY_LED: IC1.5 (2A), R8.1
TEENSY_LED+: D3.1 (DIN), IC1.3 (2Y)
TEENSY_LED_OUT: D3.3 (DOUT), J11.2
T_ON_OFF: C3.1, J3.12, U1.54 (ON_OFF)
T_PROGRAM: C2.1, J3.11, U1.53 (PROGRAM)
T_USB_DN: J4.4, U1.66 (D-)
T_USB_DP: J4.6, U1.67 (D+)
V_BAT: J1.9, U1.50 (VBAT)

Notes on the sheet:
SK6812 STATUS LEDs - 5V level shifter IC1, chain continues to header (TEENSY_LED_OUT / ESP32_LED_OUT)
5V INPUT MUX - TPS2116: VIN1 = header 5V_IN (priority), VIN2 = Teensy VUSB (cut the VUSB-VIN pad on the Teensy). VOUT = 5V rail -> Teensy VIN, buck, LT3045
MCLK SOURCE - Y1 24.576 MHz (512 fs) feeds MCLK1 via R61; Teensy pin 23 reaches MCLK1 via R7. EXTERNAL-MCLK BUILD: populate R59 (Y1 on), DNP R60; firmware must set IOMUXC_GPR_GPR1 SAI1_MCLK_DIR=0 so pin 23 is an input. DEFAULT BUILD (no firmware yet): populate R60 (Y1 standby), DNP R59; Teensy driv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
TEENSY 4.1 - series terminations, SPI link to S3, CAN3, program lines
Header net naming: functions keep function names (TDM, SPDIF, USB, MIDI, DMX, LED, power); raw GPIO is named by MCU pin: T<n> = Teensy 4.1 pin n,\nS3_IO<n> = ESP32-S3 GPIO n; an optional core function rides as a suffix (T14_SPDIF_OUT, T35_TX8, T18_SDA0, S3_IO43_TXD0, S3_IO47_SCL).\nSimple backplane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
Interlock U23 (SAI2_MODE1:MODE0, pulled up = 11 = all off). 00 internal: U19 mux (SAI2_SEL 0 = IDC777, 1 = ESP32-S3) drives BCLK/LRCLK/IN, Teensy SAI2 slave.
https://electronics.stackexchange.com/questions/310899/midi-out-thru-circuit-questions
01 header master (core slave): U21 group 1 passes AUX BCLK/LRCLK in and MCLK/DOUT out, U20 gate 1 passes AUX DIN. 10 core master: U21 group 2 drives AUX BCLK/LRCLK/MCLK/DOUT, U20 gate 2 passes AUX DIN.
J_ETH: Teensy 4.1 Ethernet pads 60-65 (R+ R- T+ T- LED GND, 2 mm 2x3 on the Teensy bottom).\nPENDING: change U1 to project_sch:Teensy4.1 in eeschema, label pins 60=ETH_R+ 61=ETH_LED 62=ETH_T- 63=ETH_T+ 64=GND 65=ETH_R-,\nand restore pads 60-65 in Teensy41_mod3 (they exist in Teensy41.kicad_mod). Ma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
ESP32-S3 - WROOM-1-N16R2 (PCB antenna). IO4/6/7 = I2S master -> mux, IO16/IO35 = BT UART, IO46 = LED chain, IO19/20 = USB -> header, UART0 -> Teensy Serial7 + header
BLUETOOTH SINK - IDC777-1 (CONSIGNED part). I2S master into mux U21. UART to S3, RST/SYS_CTRL from SRC GPO1/GPO2, R72 = SYS_CTRL pulldown. Antenna end at a 100 mm board edge, copper-free keepout all layers.
SAI2 AUX INPUT BLOCK (stage 10y). One asynchronous I2S source at a time into Teensy SAI2; sample-rate conversion is done in Teensy software (no hardware SRC).
Low-Jitter Audio Clock
3.3V RAIL DECOUPLING
U13 = ESP32-S3-WROOM-1-N16R8 (16 MB flash + 8 MB OCTAL PSRAM, needed for Spotify/cspot stream buffering).\nOctal PSRAM owns IO35/IO36/IO37 -> those module pins are NC. BT UART RX therefore uses IO3 (not IO35).\nDo not substitute an R2 (quad) module without re-checking: R2 frees IO35-37 but 2 MB PSR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
3.3V_DIG BUCK - AP63203 2 A (S3, BT, SRC, mux, isolator) + 5V input decoupling. EN pulled up by R66.
MIDI IN
TDM BUS BUFFERS - Teensy I2S1 -> TDM1 / TDM2 (74LVC2G125). Slave-clock option: buffer ~OE + bypass jumpers, see change-map section 8
MIDI THROUGH
MIDI
EDGE HEADERS - J1/J2 Teensy domain, J3/J4 S3 domain. Two 2x22 side by side per 60.96 mm edge. Pin map: documentation/core-spin2-change-map.md section 13. RESERVED pins carry no-connect flags.
Every driver reaches the shared SAI2_* / AUX_I2S_* nets through its own 33 R; only one group is ever enabled. Teensy pins: BCLK2 = 4, LRCLK2 = 3, IN2 = 5, OUT2 = 2, MCLK2 = 33, SEL = 44 (T22), MODE0 = 18 (T26), MODE1 = 19 (T27).
U1 Teensy 4.1 memory: fit 2x APS6404L-3SQR-SN (8 MB PSRAM each, 16 MB total, EXTMEM) on the Teensy's own bottom-side SOIC-8 pads\nfor loop recording, echo and reverb buffers. Optional W25Q128 QSPI flash on the second pad if 8 MB PSRAM + flash is preferred.\nPCB rule: no parts or pads on the core to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
MIDI circuit from TeensyMIDIAudio project.
3.3V ANALOG RAIL - LT3045 500 mA ultra-low-noise LDO (SET 33k = 3.3 V). Feeds buffers, pull-ups, header 3.3V pins. Teensy 3V3 is NOT connected to this rail.
MIDI OUT
J13 u.FL: DNP with the IDC777-1 (chip antenna). Fit J13 and populate U22 as IDC767 (same 60-pad LGA, pad 57 = EXT_RF) for an external antenna.\nPCB: 50 ohm CPW from pad 57 to J13, GND pads 56/58 either side, ground vias every 1-2 mm, keep it short, no matching network (IDC767-DTS-V003 p.8).
MOUNTING HOLES / PANEL TABS
MIDI IN / OUT / THRU - H11L1 opto + 74HCT2G17 buffer. Jack-level signals go to header J2 (MIDI_IN/OUT/THRU_4/5)

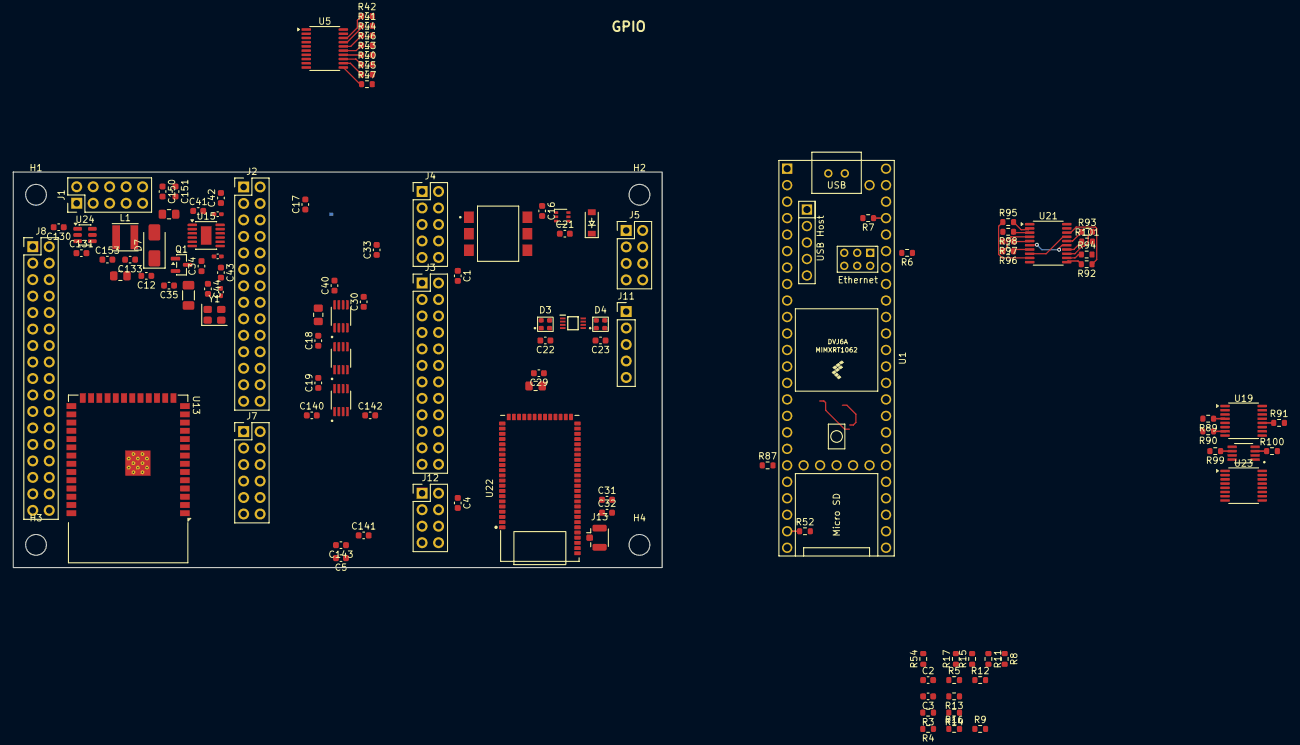
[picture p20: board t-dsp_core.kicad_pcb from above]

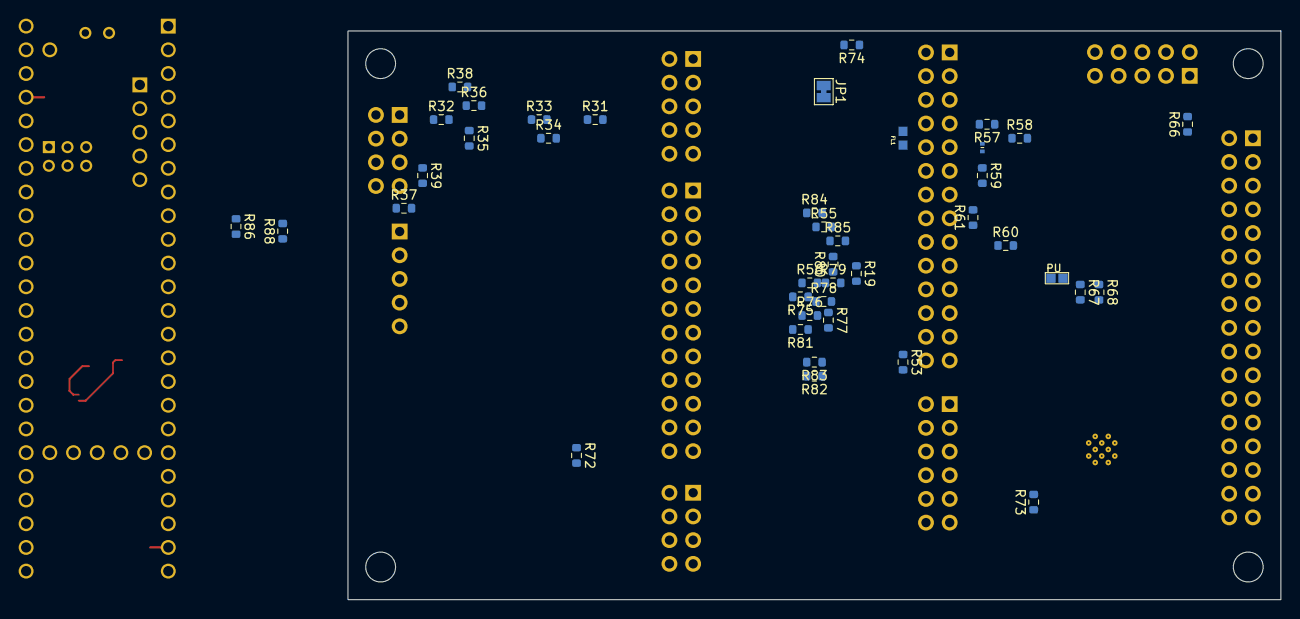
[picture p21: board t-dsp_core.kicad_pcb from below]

Board: 4 copper layers, 100.0 x 61.0 mm, 164 parts (41 on the bottom side), 172 nets.

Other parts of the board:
board_outline2: board_outline; audio_project_board_outline_100x60.96

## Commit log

2026-02-28 Initial commit: T-DSP Core 4-layer audio backplane
    KiCad project for the T-DSP Core — a 4-layer audio backplane hosting
    Teensy 4.1, ESP32, and T-DSP TAC5212 codec module. Derived from the
    T-DSP Desktop Pro with a simplified 4-layer stackup for lower cost.
    [1746311-1.step, 1808--3DModel-STEP-630548.STEP, 2120--3DModel-STEP-630548.STEP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]
2026-02-28 Fix CI: rename project references and update to 4-layer stackup
    - Update manufacturing.yml: all t-dsp_desktop_pro → t-dsp_core
    - Update .kibot.yaml: project name, 4-layer board comment, remove In3-In6
    layers from gerbers and pcb_pdf (4-layer has only F.Cu, In1.Cu, In2.Cu, B.Cu)
    - Update gallery.html: title, GitHub link, render filename prefix
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2026-07-25 Migrate project to KiCad 10 and add clock/filter block
    Two changes are combined here because KiCad 10 rewrote every file it
    opened, making the format churn inseparable from the design work.
    Design work:
    - Adds ~43 schematic symbols and 31 footprints: U11, U109, CR1 oscillator,
    FL1/FL2 common-mode chokes, FB8 ferrite, C40-C49, C129, R55-R58, R61,
    and associated wiring, junctions and global labels.
    - New library parts: BLM15AG601SN1D, BLM18BA121SN1D, CR_SMA_403AE_OSI,
    DLW32SH101XK2L, C_0402 hand-solder, MSOP-12-1EP, Abracon ASDMB
    oscillator, Tab.
    - Registers lib_sch in fp-lib-table.
    Format migration:
    - All .kicad_mod, .kicad_sch, .kicad_pcb and .kicad_pro files rewritten in
    KiCad 1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
    [BLM18BA121SN1D.step, t-dsp_core.kicad_pcb, t-dsp_core.kicad_sch]
2026-07-25 Merge ESP32-S3 section from t-dsp-core fork
    Brings the ESP32-S3 migration work into this repository, which has the
    git history, the origin remote, and the newer clock/filter block. The
    t-dsp-core working tree it came from is now redundant.
    Pasted section (241 elements at negative X): 106 wires, 64 global labels,
    28 symbols, 24 junctions, 11 labels, 7 no-connects, 1 text. Contains a
    duplicate of the ESP32 support circuitry with U110 (ESP32-S3-WROOM-1)
    placed at its centre, currently unwired.
    Seven reference designators collided with the existing clock/filter block
    and were reassigned on the pasted copies only, leaving the originals
    untouched:
    C43 -> C130 R55 -> R66 R57 -> R68 U1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
    [t-dsp_core.kicad_sch]
2026-07-25 Wire U110 (ESP32-S3) to the migrated net map
    Connects 19 of 41 pins on U110, replacing the ESP32-DevKitC pinout with
    ESP32-S3-WROOM-1 equivalents. Each connection is a 5.08mm wire stub plus a
    label matching the type already used for that net elsewhere on the sheet.
    Carried over unchanged:
    3V3->2 EN->3 GND->1/40/41 IO0->27 IO12->20 IO13->21 IO14->22
    IO16->9 IO17->10 IO39->32 (OUTPUTB)
    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
    [t-dsp_core.kicad_sch]
2026-07-25 Fix schematic made unloadable by Konnect, and revert ineffective renames
    connect_to_net rewrites the entire schematic rather than patching it. That
    rewrite dropped the arguments from the User paper size, leaving
    (paper "User")
    which KiCad refuses to load: "need a number for 'width', line 6". Restored
    to (paper "User" 1270 1270), the value held since c8ea8df. Verified by
    kicad-cli sch export netlist, which now parses the file and emits a
    532KB netlist.
    The same rewrite also regenerated every Reference property from the
    symbol instances blocks, which reverted the reference designator renames
    made in db33470. Those renames were never effective in the first place:
    edit_schematic_component w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
    [t-dsp_core.kicad_sch]
2026-07-25 Restore S3 section and resolve U13 collision (LT3045 -> U15)
    Snapshot of manual work in eeschema before wiring the remaining 12 nets:
    the ESP32-S3 box was restored with its 19 connections intact, U2 was
    brought back, and the LT3045 regulator was renamed U15 so U13 belongs
    solely to the ESP32-S3.
    Six reference designators still collide (C43, C44, R55, R56, R57, R61).
    [t-dsp_core.kicad_sch]
2026-07-25 Wire ESP32-S3 TFT, I2C and GPI interfaces (11 nets)
    Completes the U2 -> U13 net migration except for two cases noted below.
    The S3 now carries 28 of the 30 nets on the classic ESP32-DevKitC.
    Display and touch (ILI9341 + XPT2046), grouped on physically adjacent
    module pins for layout:
    SCK GPIO18 -> IO18 (11) SDO GPIO19 -> IO10 (18)
    T_CS GPIO32 -> IO8 (12) CS GPIO15 -> IO11 (19)
    SDI GPIO23 -> IO9 (17) DC GPIO2 -> IO2 (38)
    RESET GPIO4 -> IO42 (35)
    I2C header:
    ESP32_IO21_SDA GPIO21 -> IO21 (23)
    ESP32_IO22_SCL GPIO22 -> IO47 (24)
    GPI header:
    GPIO34 -> IO40 (33) GPIO35 -> IO41 (34)
    Not wired:
    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
    [t-dsp_core.kicad_sch]
2026-07-25 Add 3.3V_DIG rail passives and move the ESP32-S3 onto it
    Builds the digital 3.3V supply block for the ESP32-S3, minus the
    regulator itself (see below).
    Placed and wired:
    C130 10uF 5V input bulk
    C131 100nF 5V input HF
    C132 22uF 3.3V_DIG output bulk, sized for ESP32-S3 Wi-Fi transients
    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
    [t-dsp_core.kicad_sch]
2026-07-25 Wire U12 (TLV76733DRVR) - the 3.3V_DIG rail now has a source
    Completes the digital supply block for the ESP32-S3. U12 was placed in
    eeschema; Konnect cannot place symbols that are not already embedded in
    the schematic's lib_symbols, so that step had to be manual.
    pin 6 IN -> 5V
    pin 1 OUT -> 3.3V_DIG
    pin 2 SNS -> 3.3V_DIG (remote sense, required on the fixed version)
    pin 4 EN -> EN_3V3_DIG (100k pull-up to 5V via R66)
    pins 3/5/7 -> GND (GND, GND, thermal PAD)
    Footprint set to Package_SON:WSON-6-1EP_2x2mm_P0.65mm_EP1x1.6mm_ThermalVias.
    create_symbol had silently dropped the footprint and datasheet arguments
    when the library was generated, leaving both empty; set here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
    [t-dsp_core.kicad_sch]
2026-07-26 Baseline for board layout: ESP32-S3 migration complete
    Snapshot of the schematic and PCB after annotation was resolved in
    eeschema and the board was updated from the schematic. This is the
    starting point for layout work.
    Schematic:
    - All six duplicate reference designators resolved by Annotate
    (C43->C50, C44->C51, R55/R56/R57/R61 -> R67..R70). The netlist now
    exports without an annotation warning for the first time.
    - U2 (ESP32-DevKitC) is excluded from board. It remains in the schematic
    for reference but no longer appears in the netlist or on the PCB.
    - U13 (ESP32-S3-WROOM-1) carries 30 connected pins.
    - 3.3V_DIG is sourced by U12: C132.1, C133.1, U12.1, U12.2, U13.2.
    PCB (185 footp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
    [t-dsp_core.kicad_pcb, t-dsp_core.kicad_sch]
2026-09-28 Add BT sink + ASRC block and record the spin 2 core-module change map
    Schematic (July 27 work, previously uncommitted):
    - IDC777-1 Bluetooth sink (U22) replacing the EOL IDC747, with purpose-built
    symbol and 60-pad castellated footprint
    - SRC4382 ASRC (U19), TLV76718 1.8 V LDO (U20), 74LVC157 source mux (U21),
    decoupling C140-C151; block wiring verified by netlist
    - 100x30.48 and 100x60.96 outline footprints; PCB now on the 100x60.96 outline
    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
    [t-dsp_core.kicad_pcb, t-dsp_core.kicad_sch]
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2026-09-28 Spin 2 stage 2: delete backplane parts, old DevKitC and dead wiring
    - 129 symbols removed (connectors, jacks, switches, duplicate UI headers,
    old ESP32-DevKitC, TAC5212 module symbol, dead FL2/CR1/FB8 branch,
    LP5907 3.3V_A group, duplicate pull-ups/caps)
    - ~900 dead wires, labels, junctions and no-connects removed
    - 7 live connections cut by the cleanup were restored and verified by
    netlist: U1.22 CRX3, U1.50 V_BAT, R52.2 TRX3, R67/R68 I2C pull-ups,
    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
    [t-dsp_core.kicad_sch]
2026-09-28 Spin 2 stage 3: wireless block rewire
    - SRC4382 Port B moved from the TDM1 bus to Teensy I2S2 (4_BCLK2, 3_LRCLK2,
    5_IN2); SDINB to 2_OUT2 and SDOUTA to AUX_I2S_OUT for the reverse path
    - SRC ~RST on ESP32_EN; GPO1-4 drive BT_RST, BT_SYS_CTRL, BT_S3_SEL, AUX_SEL
    - SRC S/PDIF RX1-4 pairs and TX pair labelled for the edge header
    - S3 IO4/IO6/IO7 become the I2S master into U21; IO16/IO35 carry the BT UART;
    native USB and spare IO3/IO36/IO37/IO45/IO46 labelled for the header
    - U23 (second 74LVC157) cascaded after U21 for an aux I2S input, with C152
    - R72 100k pulldown on BT SYS_CTRL, R73 10k pull-up on ESP32_EN
    - footprints assigned to C130-C133, R66 and the new parts
    - every change confirmed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
    [t-dsp_core.kicad_sch]
2026-09-28 Spin 2 stage 4: power tree
    - TLV76733 LDO (U12) replaced by an AP63203 3.3 V buck (U24) with L1 3.3uH,
    C153 bootstrap cap and C154 22uF; EN reuses the R66 100k pull-up
    - LT3045 (U15) output now drives the 3.3V rail; the former '3.3V Teensy'
    cluster (buffers, pull-ups, decoupling, header pins) moved onto it
    - Teensy 3V3 output pins isolated with no-connect flags; VUSB (pin 49) feeds
    the TPS2116 secondary input as 5V_VUSB; primary input renamed 5V_IN
    - verified by netlist; no symbol overlaps
    [t-dsp_core.kicad_sch]
2026-09-28 Spin 2 stage 5: edge headers J1-J4 wired, old header net-map symbol removed
    - four 2x22 headers (Connector_Generic Odd_Even, PinHeader_2x22 footprint);
    all 176 pins verified against the pin map in the change map (section 13)
    - board_outline2 net-map symbol and its leftover stubs/labels removed
    - Teensy-side local labels converted to global (I2S2, encoder, SPI link);
    spare Teensy pins 22/26/27 labelled T_22/T_26/T_27; device USB pads NC
    - C129 GND side restored
    [t-dsp_core.kicad_sch]
2026-09-28 Spin 2 stage 6: final cleanup, power flags, no-connects
    - S3 IO46 now drives the SK6812 chain (ESP32_LED); J4.35 reserved
    - PWR_FLAGs on 3.3V_DIG, V_BAT, 5V_IN, LT3045 input, U9 VCC, Y1 VDD, U4
    - no-connect flags on all intentionally unused pins (U22, U19, U15, H1-H4,
    reserved header pins, Teensy device USB pads)
    - pseudo net-map symbols (#SAI1/#SAI2/#EPROG1/#EPROG2/#ESP32_*), floating
    power symbols, orphan passives, MIDI OUT/THRU jumpers and stacked leftover
    labels removed
    - C129/C48 footprints fixed
    - ERC: 1 residual error (D3.4 GND quirk, netlist-verified connected),
    remaining warnings are library-sync and cosmetic; documented in the change
    map section 14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
    [t-dsp_core.kicad_sch]
2026-09-28 Spin 2 stage 7: LCSC sourcing, PCBA substitutions, block titles, MCLK note
    - LCSC (and LCSC_MPN) fields on every part; SRC4382, IDC777 and Teensy
    marked CONSIGN; headers/holes/tabs/jumper have no LCSC part
    - substitutions for JLCPCB stock: ISO7762DW (pin 6 lifted from GND, pin 11
    NC), TLV75718PDRVR (pin-compatible), ASE-24.576MHZ oscillator with
    3.2x2.5 footprint, ESP32-S3-WROOM-1-N16R2 with PCB-antenna footprint,
    NRS4018T3R3M inductor
    - orphan decoupling caps from the deleted optical/jack blocks removed
    - a title text on every functional block; MCLK population rule printed
    next to Y1 (external-MCLK build vs default build)
    - change map: sections 15 (sourcing) and 16 (block map), MC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
    [t-dsp_core.kicad_sch]
2026-09-28 Spin 2 stage 8: DNP/excluded audit and stale notes
    - C10/C11 (dnp, excluded) and H1-H4 (excluded) removed
    - R19/R53/C4/C5 were excluded-from-board: re-placed on-board at the same
    coordinates with footprints and LCSC numbers; netlist unchanged
    - 35 obsolete text notes removed; orphaned GND symbols and hole NC flags removed
    - change map section 17
    [t-dsp_core.kicad_sch]
2026-09-28 Spin 2 stage 9: function-scoped headers J1-J11 replace the four 2x22 edge blocks; S3 N16R8 (octal PSRAM) frees IO35-37, BT UART RX moves to IO3
    [t-dsp_core.kicad_sch]
2026-09-28 Spin 2 stage 9b: J12 J_ETH header, PSRAM and Ethernet notes on the sheet, change map sections 3/10/11/13/14/15 rewritten for the function-scoped headers
    [t-dsp_core.kicad_sch]
2026-09-28 Spin 2 stage 10: PCB synced and fully placed (single-sided), M3 holes, stale FL1 and old tracks removed; change map 11.3
    [t-dsp_core.kicad_pcb]
2026-09-28 Spin 2 stage 10b: H1-H4 M3 mounting holes in the schematic (KiCad discarded the PCB-only holes); change map note
    [t-dsp_core.kicad_sch]
2026-09-28 Spin 2 stage 10c: external-antenna build option; J13 u.FL (DNP) on IDC777/IDC767 pad 57 EXT_RF; antenna decision in change map
    [t-dsp_core.kicad_sch]
2026-09-28 Spin 2 stage 10d: encoder nets become Teensy GPIO T_38/T_39/T_40 (A14-A16) on J8; S3 IO15/IO38/IO39 NC; backplane controls note and GPIO budget
    [t-dsp_core.kicad_sch]
2026-09-28 Spin 2 stage 10e: S3 IO15/IO38/IO39 back on J8 as their own nets (pins 23/24/28); Teensy 38/39/40 and S3 pins now separate
    [t-dsp_core.kicad_sch]
2026-09-28 Spin 2 stage 10f: header GPIO net-naming rule; 42 nets renamed to T<pin> / S3_IO<gpio> (fixes three wrong S3 GPIO numbers); topology unchanged
    [t-dsp_core.kicad_sch]
2026-09-28 Spin 2 stage 10g: MIDI passives out of the ESP32 antenna keep-out, 3.3V caps to the left column, holes at the corners, plain 3.2 mm hole footprint; schematic restored after a stale eeschema save
    [t-dsp_core.kicad_pcb, t-dsp_core.kicad_sch]
2026-09-28 Spin 2 stage 10h: IDC777 turned vertical on the top edge with its antenna end outward (the keep-out is at the module's short end); MIDI block to the bottom-middle, DMX caps above the isolator; change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
    [t-dsp_core.kicad_pcb]
2026-09-28 Spin 2 stage 10i: IDC777 vertical on the bottom edge (antenna out, opposite the S3); aux, MIDI and LED headers to the top-middle; MIDI opto right of the module
    [t-dsp_core.kicad_pcb]
2026-09-28 Change map: IDC777 ground clearance area (8 x 4.44 mm) and the rule areas both antennas still need
2026-09-28 Spin 2 stage 10j: J13 u.FL placed beside IDC777 pad 57; MIDI opto/buffer/diode and LEDs re-stacked, four MIDI resistors under the Teensy
    [t-dsp_core.kicad_pcb]
2026-09-28 Spin 2 stage 10k: opto row stacked up to clear the u.FL courtyard
    [t-dsp_core.kicad_pcb]
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2026-09-29 Change map: header tables for the 2x17 J8 / 2x5 J1, section 11.4 layout rework (four header rows, three slots, two-sided assembly, 4-layer stack)
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2026-09-29 Spin 2 stage 10m (2/2): net-driven two-sided passive placement (caps front at the supply pins, 55 resistors/ferrites/diodes/jumper on the back under their pins), 4-layer stack (F.Cu, In1 GND, In2 PWR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
    Placed with KiCad's pcbnew python on the saved file (the IPC path trips the project-lock dialog on 10.0.1).
    Passive-to-pin: median 2.9 mm (was 9.9), 7 parts > 10 mm (was 59). DRC: no shorts/clearance; only the
    stock ESP32 courtyard overlaps and the inherited drill warnings.
    [t-dsp_core.kicad_pcb]
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2026-09-29 Spin 2 stage 10q: muxes U21/U23 under the Teensy beside the SRC4382, TDM buffers tightened; passives re-placed
    [t-dsp_core.kicad_pcb]
2026-09-29 Spin 2 stage 10r: TDM fan-out buffers U5-U8 (4x SN74LVC2G125) replaced by one SN74LVC541APWR (U5, LCSC C113281); OE1 grounded (TDM1 group), OE2 = TDM2_OE via bridged solder jumper JP1 with 10k pull-u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
    Netlist verified: all other connectivity identical; new nets TDM1/TDM2_*_B between U5 and R40-R47, TDM2_OE.
    [t-dsp_core.kicad_sch]
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2026-09-29 Spin 2 stage 10s: S3 and IDC777 swapped (S3 bottom-left with J8 on the left edge, IDC777 bottom-right with J6/J7 on the right edge), chips spread with 2-3 mm air, passive spacing margin 0.35 mm; chan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
    [t-dsp_core.kicad_pcb]
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2026-09-29 Spin 2 stage 10u (board, fix): terminations really on 0402 footprints now (footprint sync reloads the board between phases); passives re-placed; change map note
    [t-dsp_core.kicad_pcb]
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2026-09-30 Spin 2 stage 10x (1/2): external supply mandatory. TPS2116 mux + PR1 divider + Teensy-USB caps removed, Teensy VUSB NC; 5V_IN -> SMAJ5.0A TVS (D7) -> AO3401A reverse-polarity P-FET (Q1) -> 5V rail wi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
    Netlist: all other connectivity identical; the new USB nets are single-node until the two
    isolators are placed (manual eeschema step, change map 11.7).
    [t-dsp_core.kicad_sch]
2026-10-01 Spin 2 stage 10y (1/2, schematic): SAI2 aux input block replaces the SRC4382 + 74LVC157 muxes + SPDIF header
    - Removed U19 SRC4382, U20 TLV75718 (1V8 LDO), U21/U23 74LVC157, J6 SPDIF header, their caps (C144-C149, C152) and R1/R2/R10; USB isolation prep reverted (Teensy pads 66/67 and S3 USB direct to J4/J8, J4 2/8/10 and J8 33 = GND, J8 34 = 5V).
    - New: U19 SN74LVC257A source mux (IDC777 or S3, SAI2_SEL), U21 SN74LVC244A header buffer (group 1 header-master in / MCLK+DOUT out, group 2 core-master out), U20 SN74LVC2G125 header DIN gate, U23 SN74LVC138A interlock (SAI2_MODE1:0 = 00 internal, 01 header master, 10 core master, 11 off = pull-up default), 13x 33 R 0402 series, 3x 10 k 0402, 4x 10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
    [t-dsp_core.kicad_sch]
2026-10-01 Spin 2 stage 10y (2/2, board): SAI2 block footprints synced and placed; stage 10x power parts placed
    - swap_fp/sync_fields from the stage 10y netlist: U19 TSSOP-16 (257), U21 TSSOP-20 (244), U23 TSSOP-16 (138), U20 SOP-8 (2G125), J7 2x6 J_SAI2, J4 2x5 J_USB, D7 SMA + Q1 SOT-23 added; J6, U3, C13/C14, R28-R30, C144-C149, C152, R1/R2/R10 removed; R86-R101 added.
    - Placement: U19/U23 under the Teensy (slot 2, Y 38.5), U21 and U20 in the right column beside J_SAI2, D7/Q1 in the power row where the TPS2116 was; passives re-placed two-sided by the net-driven placer (131 parts, median 2.4 mm / mean 3.4 mm to their pin).
    - Three leftover /OUT1B_MCU track fragments from the old design removed; the bo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
    [t-dsp_core.kicad_pcb]
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2026-10-02 Spin 2 stage 11b: all 0402 resistors to 0603 (footprints swapped in place, no re-placement)
    - 33 x 33 R (C23140), 10 x 0 R jumpers (C21189), 3 x 10 k (C25804) now Resistor_SMD:R_0603_1608Metric in schematic and board; positions and rotations unchanged, the 30 routed track segments kept.
    - Known result of swapping without re-placing: 26 resistor courtyard overlaps, 18 pad-to-pad clearance errors (0.05-0.10 mm) and one existing track (Net-(U21-O3b)) now touching R95 pad 2. These need manual nudging.
    - Capacitors C45, C46, C129 stay 0402.
    [t-dsp_core.kicad_pcb, t-dsp_core.kicad_sch]
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2026-10-02 Board: series resistors fanned out beside their driver pins (U19, U20, Teensy pins 23 and 45)
    - R89/R90/R91 at U19, R99/R100 at U20, R7 at Teensy pin 45 (MCLK1), R52 at Teensy pin 23: chip-side pad facing the pin, 2.6 mm off the pad (2.75 mm for the Teensy through-hole pins), same side as the chip, with a 0.25 mm stub track.
    - U5 and U21 groups were already done by hand and are untouched.
    - Not moved: R55/R56/R75/R76/R81 (U11/U6/U7 are stacked too tightly), R3/R4/R6/R9 (host and Ethernet pads sit beside those Teensy pins), R61 (J2 is in the way at Y1), R5 (header series resistor, no driver chip).
    [t-dsp_core.kicad_pcb]

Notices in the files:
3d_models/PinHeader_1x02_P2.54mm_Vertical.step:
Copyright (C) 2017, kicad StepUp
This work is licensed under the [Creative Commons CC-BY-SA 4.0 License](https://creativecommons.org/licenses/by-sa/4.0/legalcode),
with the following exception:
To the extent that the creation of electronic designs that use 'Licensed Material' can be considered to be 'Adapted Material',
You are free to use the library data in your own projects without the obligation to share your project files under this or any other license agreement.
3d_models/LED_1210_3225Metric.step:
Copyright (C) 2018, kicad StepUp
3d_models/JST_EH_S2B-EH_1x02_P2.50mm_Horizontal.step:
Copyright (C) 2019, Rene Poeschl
